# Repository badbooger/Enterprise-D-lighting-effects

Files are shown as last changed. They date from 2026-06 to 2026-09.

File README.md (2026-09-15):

# USS Enterprise-D Prop Controller

Custom lighting and sound controller for the DeAgostini USS Enterprise-D partwork model kit (31 issues). Replaces the original lighting PCBs with custom ESP32-based boards controlled from a 3D-printed LCARS PADD touchscreen.

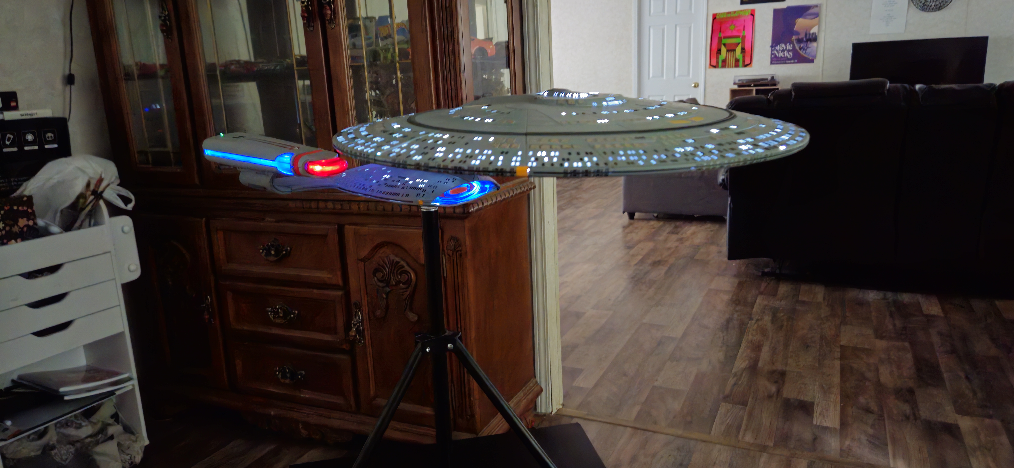
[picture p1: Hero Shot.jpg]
USS Enterprise-D prop model


## What it does

- **LCARS DataPad** — 7" touchscreen prop running a full LVGL LCARS interface. Controls all lighting, sound, and settings on both model sections wirelessly.
- **ESP-NOW mesh** — Bridge (saucer) and EngRoom (stardrive) communicate without any router or hub. Normal operation requires no WiFi.
- **Coordinated effects** — startup, shutdown, damage, warp, and navigation sequences across 18 LED groups on the saucer and 10 groups on the stardrive, all triggered from the PADD.
- **Sound** — DY-SV17F player on the Bridge drives 25 TNG sound files. DataPad has its own second player for UI sounds and ambient audio.
- **OTA updates** — all three units flash over WiFi via Arduino IDE. WiFi only starts when you need it; ESP-NOW resumes automatically when it disconnects.

All LEDs are white. All effects are brightness, PWM duty cycle, and timing patterns only — no colour control.

---

## Units

| Unit | Board | Sketch | Role |
|---|---|---|---|
| Bridge | ESP32-S3 | `Bridge_ESP/` | Saucer — 18 LED groups, sound |
| EngRoom | Xiao ESP32-C3 | `Engine_Room_ESP/` | Stardrive — 10 LED groups |
| DataPad 7" | Waveshare ESP32-S3 7" | `Data_Pad/` | LCARS touchscreen controller |
| WarpCore | Arduino Nano ESP32 | `WarpCore_ESP32/` | Standalone warp core display (see note below) |

There's also a **work-in-progress webpage-control variant** of Bridge and EngRoom — [`Bridge_ESP_Webpage/`](Bridge_ESP_Webpage) and [`Engine_Room_ESP_Webpage/`](Engine_Room_ESP_Webpage). Instead of the DataPad pushing WiFi credentials for OTA, Bridge hosts its own permanent access point with a built-in control webpage — no DataPad or home network required to run or control the model. It hasn't been tested as thoroughly as the sketches above yet; see each folder's README for details and current rough edges.

---

## Hardware

Six custom PCB designs (seven boards total), all designed in EasyEDA. Gerbers, BOMs, and pick-and-place files are in `enterprise documentation/PCB Design/`.

**Single power source option:** The EngRoom and Neck PCBs use wider 0.8–1mm VCC/GND traces than the rest of the boards, sized to carry the full model's power if you'd rather not run separate battery boxes. Route: drill a hole through the stand mount to run wires hidden from the stand into EngRoom's 2-pin JST connector → through the EngRoom PCB → out the FFC to the Neck PCB's 2-pin connector, reusing the same connector that would normally be power-in from a local neck battery → out through the neck to the spare 2-pin JST connector on Bridge PCB3, which is unused in the normal build → power wiring from there is the same as the original build. This wires the two sections together permanently — the model can no longer be physically separated into saucer and stardrive once this is done. The 2-pin connectors that come with the kit's battery boxes can be reused to make the jumper needed to run power from the Neck PCB to the Bridge PCB3 — or if you don't want to cut the wiring off the battery boxes, the connectors are standard JST and can be ordered from Amazon or a parts supplier of your choice.

**Fuse and reverse-polarity protection:** the external supply connects through a barrel jack instead of the model's battery boxes — unplug all three battery packs (both saucer packs and the neck pack) before running this way, since nothing in this design accounts for a battery pack and an external supply both being connected at once. Add an inline fuse (slow-blow, rated above the model's combined nominal draw — see `HARDWARE.md` for the full LED power budget) and a basic reverse-polarity diode in series with the barrel jack, outside the model where both are easy to inspect and replace. This is bare-minimum protection, not a full power-supply design — there's no BMS or onboard charge/discharge protection anywhere in this build. **Exact fuse rating, diode part, barrel jack size, and wiring routing are left to you** — every build's access points and cable runs differ enough that one prescribed part list won't fit every setup.

See `HARDWARE.md` for pinouts, resistor values, power budget, battery configuration, and connector maps.

Parts list with Amazon links: `amazon parts.txt`.

---

## Getting started

### Prerequisites

- Arduino IDE 2.x
- esp32 by Espressif Systems **v3.3.8** (Board Manager)
- Set your Arduino sketchbook path to this folder — all libraries are in `libraries/`

### First flash (USB)

> **Blank ESP32-S3 modules:** A new S3 chip that has never been programmed will not enumerate over USB — first flash must go through UART (TX/RX) with a USB-to-serial adapter. Alternatively, use an S3 desoldered from a dev board — those ship with USB CDC firmware already flashed. See `HARDWARE.md` for details.

Flash in this order so ESP-NOW communication works from the start:

1. **Bridge** — see [Bridge_ESP/README.md](Bridge_ESP/README.md)
2. **EngRoom** — see [Engine_Room_ESP/README.md](Engine_Room_ESP/README.md)
3. **DataPad** — see [Data_Pad/README.md](Data_Pad/README.md)

Before flashing: run `MAC_address_retriver/` on each board to get its MAC address, then update the peer MAC arrays in each sketch to match your hardware.

### OTA updates (after initial flash)

Normal operation: WiFi off, ESP-NOW on channel 1.

1. Press **START WIFI** on the DataPad — pushes your saved WiFi credentials to all units, all connect.
2. Arduino IDE → Tools → Port → select the network port for the unit to flash.
3. Upload. OTA password: **admin** (enter in Arduino IDE at upload time — no `setPassword()` call in the sketch).
4. Press **SAVE WIFI** again on the DataPad → all units disconnect, revert to channel 1.

> Use a **phone hotspot**, not a home mesh/multi-AP network. Units on different channels cannot reach each other via ESP-NOW and silently fail. See `DEVNOTES.md` for details.

---

## Repository contents

| Path | Contents |
|---|---|
| `Bridge_ESP/` | Saucer ESP32-S3 sketch |
| `Engine_Room_ESP/` | Stardrive Xiao ESP32-C3 sketch |
| `Bridge_ESP_Webpage/` | **Work in progress** — Bridge variant with a built-in WiFi control webpage |
| `Engine_Room_ESP_Webpage/` | **Work in progress** — EngRoom variant to pair with `Bridge_ESP_Webpage`, adds a WiFi fallback/recovery page |
| `Data_Pad/` | 7" DataPad sketch and LVGL UI files |
| `WarpCore_ESP32/` | WarpCore ESP32 sketch |
| `Bridge_NVS_Clear/` | Utility — wipes Bridge WiFi credentials from NVS |
| `EngRoom_NVS_Clear/` | Utility — wipes EngRoom WiFi credentials from NVS |
| `MAC_address_retriver/` | Utility — reads and prints a board's MAC address |
| `enterprise documentation/PCB Design/` | Gerbers, BOMs, pick-and-place for all 6 board designs |
| `enterprise documentation/Data Pad stl/` | DataPad PADD case STL files |
| `enterprise documentation/Warp_Core/` | Original Thingiverse WarpCore design archive (see below) |
| `enterprise documentation/pcbs test prints/` | PCB test-fit prints — print before ordering boards |
| `HARDWARE.md` | Full hardware reference |
| `SOUND_MAP.md` | Sound file list and trigger map |
| `amazon parts.txt` | Parts list with Amazon links |

**Not included:**
- `sounds/` — source TNG audio clips from [trekcore.com/audio](https://trekcore.com/audio/). See `SOUND_MAP.md` for the file list and naming format.
- `libraries/` — install per `PROJECT_REFERENCE.md`.

---

## WarpCore

The WarpCore is a standalone unit with its own repository — `WarpCore_ESP32/` is included here for reference. See the WarpCore repo for the full README, pin assignments, and build notes.

The 3D model is based on **ST:TNG Warp Core by ElmoC** (Thingiverse thing:1656741). The original listing is no longer available online. A complete archive including all STL files, the original PCB files, and the original Arduino sketch is preserved in `enterprise documentation/Warp_Core/`. Licensed under Creative Commons Attribution — Non-Commercial — No Derivatives 3.0.

Other warp core designs exist on Thingiverse in different sizes, including versions designed around ARGB LED strips which give a colour-animated effect. Worth exploring if you are starting from scratch.

---

## License

Code and PCB designs: [MIT](LICENSE)  
WarpCore 3D model: CC BY-NC-ND 3.0 (ElmoC — see `enterprise documentation/Warp_Core/LICENSE.txt`)  
Sound files: not included — source separately from trekcore.com/audio/

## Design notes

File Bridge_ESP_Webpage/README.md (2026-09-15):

# Bridge ESP (Webpage variant) — ESP32-S3

> **⚠️ Work in progress.** This is a newer variant of the Bridge firmware that hosts its own WiFi control page — it hasn't been through the same amount of real-world testing as the plain [`Bridge_ESP`](../Bridge_ESP) sketch yet. Expect rough edges. If you just want the proven, minimal firmware (DataPad-driven, no built-in webpage), use `Bridge_ESP` instead.

Saucer section controller — same core effects as `Bridge_ESP` (window groups, nav lights, impulse engines, sound player, startup/shutdown sequences, ESP-NOW to EngRoom/DataPad), plus:

- **Hosts its own WiFi access point and control webpage** (`WebServer.h`) — no home network or DataPad required to run the model. Connect a phone or laptop directly to Bridge's AP and control everything from a browser.
- **Autonomous demo mode** — an optional showpiece loop that cycles power on/off and fires random effects on its own, useful for unattended display.
- **DataPad auto-pairing window** — a button on the control page opens a short listen-and-adopt window so a new DataPad can be paired without recompiling anything.

---

## Arduino IDE setup

| Setting | Value |
|---|---|
| Board | ESP32S3 Dev Module |
| Board package | esp32 by Espressif Systems v3.3.8 |
| Partition scheme | Default 4MB with spiffs (or Huge APP if flash space is needed) |
| Upload speed | 921600 |

No external libraries needed — `WebServer.h` is part of the ESP32 Arduino core, same as everything else this sketch uses.

This folder needs both files together: `Bridge_ESP_Webpage.ino` and `control_html.h` (the control page's HTML/JS, served straight from flash).

---

## First flash

Same as `Bridge_ESP` — see that folder's README for PCB/module assembly notes and the board-settings-reset warning. OTA password is `admin`.

---

## MAC addresses to update

Open `Bridge_ESP_Webpage.ino` and find the peer MAC arrays near the top of the file:

```cpp
uint8_t broadcastAddress1[] = { 0x00, 0x00, 0x00, 0x00, 0x00, 0x00 }; // EngRoom
uint8_t broadcastAddress2[] = { 0x00, 0x00, 0x00, 0x00, 0x00, 0x00 }; // DataPad
```

Two ways to set these:
- **Edit and recompile** — replace with the actual MACs from your hardware (run `MAC_address_retriver/` on each board), same as the plain sketch.
- **Set them live over the control page** — once flashed and connected to Bridge's AP, browse to `http://<bridge-ip>/setmac?peer=engroom&mac=AA:BB:CC:DD:EE:FF` (or `peer=datapad`). Saved to NVS, applied immediately, survives reboots. No recompiling needed if you swap a board later.

---

## Connecting to Bridge's control page

Bridge hosts its own access point:

| Setting | Value |
|---|---|
| SSID | `Enterprise D` |
| Password | `ncc1701-d` |

Connect a phone or laptop to it, then browse to `http://192.168.4.1/`. Change the SSID/password constants near the top of the sketch if you'd rather use your own.

---

## Everything else

GPIO assignments, key effects, sound setup, and NVS settings are identical to the plain `Bridge_ESP` sketch — see that folder's README for the full reference tables. The NVS clear utility (`Bridge_NVS_Clear/`) works the same way here too.

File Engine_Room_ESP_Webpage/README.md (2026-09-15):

# Engine Room ESP (Webpage variant) — Xiao ESP32-C3

> **⚠️ Work in progress.** This is a newer variant of the EngRoom firmware, meant to pair with [`Bridge_ESP_Webpage`](../Bridge_ESP_Webpage). It hasn't been through the same amount of real-world testing as the plain [`Engine_Room_ESP`](../Engine_Room_ESP) sketch yet. Expect rough edges. If you just want the proven, minimal firmware, use `Engine_Room_ESP` instead.

Stardrive section controller — same core effects as `Engine_Room_ESP` (nacelles, deflector, impulse engines, nav lights, neck/case windows, ESP-NOW to Bridge/DataPad), plus:

- **Independent aft photon torpedo control**, for the optional second-LED "Photon 2x" torpedo variant (adds a connector on GPIO9, active-low, no transistor needed). Fires and animates separately from the forward tube — not just a mirror of it. If you don't have the second connector installed, this is simply unused.
- **Automatically joins Bridge's WiFi AP** on boot — no manual WiFi setup needed as long as `Bridge_ESP_Webpage` is running nearby with its default AP settings.
- **Fallback access point** if Bridge's AP can't be reached within 3 minutes (Bridge off, unflashed, or out of range) — EngRoom hosts its own small AP with a bare-bones recovery/test page, so you're never locked out of OTA just because Bridge is unreachable.

---

## Arduino IDE setup

| Setting | Value |
|---|---|
| Board | XIAO_ESP32C3 |
| Board package | esp32 by Espressif Systems v3.3.8 |
| Upload speed | 921600 |

No external libraries needed — `WebServer.h` is part of the ESP32 Arduino core, same as everything else this sketch uses.

---

## First flash

Same as `Engine_Room_ESP` — see that folder's README for module assembly notes, the download-mode button sequence, and the board-settings-reset warning. OTA password is `admin`.

---

## MAC addresses to update

Open `Engine_Room_ESP_Webpage.ino` and find the peer MAC arrays near the top of the file:

```cpp
uint8_t broadcastAddress[]  = { 0x00, 0x00, 0x00, 0x00, 0x00, 0x00 };  // DataPad
uint8_t bridgeAddress[]     = { 0x00, 0x00, 0x00, 0x00, 0x00, 0x00 };  // Bridge
uint8_t dataPad2Address[]   = { 0x00, 0x00, 0x00, 0x00, 0x00, 0x00 };  // DataPad 2.8" (optional)
```

Two ways to set these:
- **Edit and recompile** — replace with the actual MACs from your hardware (run `MAC_address_retriver/` on each board), same as the plain sketch.
- **Set them live over Serial** — connect at 115200 baud and send `SETMAC bridge AA:BB:CC:DD:EE:FF` (or `SETMAC datapad ...` / `SETMAC datapad2 ...`). Saved to NVS, applied immediately, survives reboots.

---

## Fallback AP and recovery page

If EngRoom can't join Bridge's AP within 3 minutes, it hosts its own:

| Setting | Value |
|---|---|
| SSID | `EngRoom Fallback` |
| Password | `ncc1701-d` |

Connect to it and browse to `http://192.168.4.1/` for a plain status/test page: connection status, All LEDs On/Off (also pings Bridge over ESP-NOW as a connectivity check), an LED test walk, a plain reboot, and a reset-to-default that clears settings but keeps your paired peer MACs. It keeps retrying Bridge's AP in the background and tears itself down automatically once Bridge is reachable again — no reboot needed.

---

## Everything else

GPIO assignments (including GPIO9 for the optional aft photon connector), key effects, and NVS settings are the same as the plain `Engine_Room_ESP` sketch — see that folder's README for the full reference tables. The NVS clear utility (`EngRoom_NVS_Clear/`) works the same way here too.

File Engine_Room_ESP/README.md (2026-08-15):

# Engine Room ESP — Xiao ESP32-C3

Stardrive section controller. Drives 9 LED groups through NPN transistors: nacelles (sine-wave pulse with warp mode), deflector, photon torpedoes, impulse engines, nav lights, engineering case sections, and neck (back of neck + both battle bridges on one pin). Communicates with Bridge and the DataPad via ESP-NOW. Supports OTA firmware updates and mDNS (`EngRoom.local`) when WiFi is connected.

---

## Arduino IDE setup

| Setting | Value |
|---|---|
| Board | XIAO_ESP32C3 |
| Board package | esp32 by Espressif Systems v3.3.8 |
| Upload speed | 921600 |

No external libraries needed — all dependencies are part of the ESP32 Arduino core.

---

## PCB and module assembly

The Seeed Studio Xiao ESP32-C3 must be soldered to the EngRoom PCB yourself — JLCPCB does not carry it as a placeable part, so it cannot be installed during PCB assembly. Order the Xiao separately and hand-solder it to the board after the PCB arrives.

Once soldered, the Xiao's own onboard USB-C connector is used for flashing — no other USB port is needed.

---

## First flash

Connect via the Xiao's USB-C port. The Xiao ESP32-C3 may need to be put into download mode on first flash: hold BOOT, tap RESET, release BOOT. Select the correct COM port in Arduino IDE and upload.

After the first USB flash, subsequent updates can be done OTA — see the root README for the OTA procedure.

**OTA password:** `admin` — entered in Arduino IDE at upload time.

> **Warning — board settings reset on sketch reload:** Arduino IDE resets board settings to defaults whenever a sketch is opened or the `.ino` file is replaced. Always verify the settings in the table above before flashing. If the wrong settings are used, the board will not boot and will require USB access to recover — the EngRoom board is inside the stardrive section and requires disassembly to reach.

---

## MAC addresses to update

Open `Engine_Room_ESP.ino` and find the peer MAC arrays near the top of the file:

```cpp
uint8_t broadcastAddress1[] = { 0x20, 0x6e, 0xf1, 0xa9, 0xa1, 0x14 };  // DataPad
uint8_t broadcastAddress2[] = { 0xe0, 0x72, 0xa1, 0xd7, 0x37, 0x14 };  // Bridge
```

Replace with the actual MACs from your hardware (run `MAC_address_retriver/` on each board).

---

## GPIO assignments

**Lower engineering section:**

| GPIO | Function |
|---|---|
| 2 | Battery ADC (270kΩ+100kΩ divider, ADC_11db) |
| 4 | Photon torpedoes |
| 5 | Nav lights |
| 6 | Deflector |
| 7 | Top engineering case |
| 8 | Left nacelle |
| 9 | Right nacelle |
| 10 | Impulse engine |
| 21 | Bottom engineering case |

**Neck section** (routed via FFC from lower engineering PCB):

| GPIO | Function |
|---|---|
| 20 | Neck windows — back of neck + both battle bridges wired together, one pin |

All LED groups are switched through MMBT2222A NPN transistors. Do not connect LEDs directly to GPIO pins.

> **Note on nav lights:** GPIO 5 drives 4 transistor bases in parallel (EngRoom PCB, neck PCB, port nacelle, starboard nacelle) — all nav LEDs across the stardrive section from one pin.

---

## Key effects

**Nacelle pulse (normal)** — slow sine-wave breathing (5000ms period, 80–115 duty range) when model is running.

**Nacelle warp mode** — triggered by `LED_WARP` command with a speed value 1–10. Three-phase startup: snap to 25% → ramp to 100% over ~1.5s → hold at speed-mapped brightness (80–100%). Speed changes while warp is active skip the ramp. Returns to normal sine on `LED_WARP val=0`.

> **Brighter warp flash:** The nacelle PCB uses 6× blue 1206 SMD LEDs wired as 3 parallel pairs, each pair sharing one current-limiting resistor. This build uses **240Ω** on those pairs — at 7.4V nominal with Vf ≈ 2.6–3.1V that's ~8.75mA per LED, noticeably brighter than a typical stock value and well within the 20mA LED rating — installed specifically to make the warp-flash effect punchier. In practice, brightness between paired LEDs is indistinguishable. Do not go below 220Ω. The single LEDs on the board (non-paired, through-hole) use a separate higher value, **470Ω**, to match the same per-LED current.
>
> The higher current only shows up during the warp effect itself. Normal-running nacelle brightness is capped in firmware well below what these resistors allow — the idle sine pulse stays in the 80–115/255 duty range (see "Nacelle pulse (normal)" below); only warp mode ramps up toward full 255 duty. So the resistor change buys headroom for the flash without making the nacelles run hot/bright all the time.

**Deflector** — 60% steady brightness during normal operation, 100% during warp.

**Photon torpedoes** — charge/fire flash sequence on `LED_ELEC_SHORT` (repurposed command). Charge for 750ms, fire flash at 200ms.

**Startup sequence** — lighting groups come on in steps coordinated with the Bridge startup. EngRoom sends `LED_BLINK` to Bridge at the nav step and `LED_ENGINE` at the impulse step so both sections sync their timing.

**Assembly mode** — all groups blink together for board testing and LED positioning.

---

## NVS settings

Namespace: `"engroom"`. All configurable from the DataPad settings screen.

| Key | Default | Purpose |
|-----|---|---|
| `blink_ms` | 1000 | Nav light blink interval (ms) |
| `sync_mode` | true | Assembled / Separated mode |
| `asm_mode` | false | Assembly blink mode |
| `eff_simple` | false | Simple effects mode (constant ON instead of sine/pulse) |

---

## NVS clear utility

If EngRoom gets stuck trying to connect to WiFi on every boot: flash `EngRoom_NVS_Clear/EngRoom_NVS_Clear.ino`, confirm "Done" in Serial Monitor (115200), then reflash the main sketch.

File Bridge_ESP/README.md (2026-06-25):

# Bridge ESP — ESP32-S3

Saucer section controller. Drives 15 window groups and 3 dedicated outputs (nav lights, two impulse engines) through NPN transistors. Runs the startup/shutdown sequence, engine pulse, navigation blink, and electrical-short damage effect. Hosts a sound player (DY-SV17F). Communicates with EngRoom and the DataPad via ESP-NOW.

---

## Arduino IDE setup

| Setting | Value |
|---|---|
| Board | ESP32S3 Dev Module |
| Board package | esp32 by Espressif Systems v3.3.8 |
| Partition scheme | Default 4MB with spiffs (or Huge APP if flash space is needed) |
| Upload speed | 921600 |

No external libraries needed — all dependencies (ArduinoOTA, ESPmDNS, Preferences, esp_now) are part of the ESP32 Arduino core.

---

## PCB and module assembly

The saucer PCBs are designed around an ESP32-S3 module (WROOM or equivalent). JLCPCB can place and solder the module as part of the PCB assembly order if they have the part in stock — check availability when ordering. The assembled PCB has its own USB-C connector for flashing, so no separate dev board is needed once the PCB is built.

If JLCPCB doesn't have the module available, or if you want to test the sketch before the PCBs arrive: flash the sketch onto a standalone ESP32-S3 dev board first, confirm it works, then transfer the module to the PCB. Once installed, use the onboard USB-C on the PCB or OTA for all subsequent flashes.

---

## First flash

Connect via the USB-C port on the PCB (or dev board). Select the correct COM port in Arduino IDE and upload.

After the first USB flash, subsequent updates can be done OTA — see the root README for the OTA procedure.

**OTA password:** `admin` — entered in Arduino IDE at upload time. There is no `ArduinoOTA.setPassword()` call in the sketch; the library accepts whatever the IDE sends.

> **Warning — board settings reset on sketch reload:** Arduino IDE resets board settings to defaults whenever a sketch is opened or the `.ino` file is replaced. Always verify the settings in the table above before flashing. If the wrong settings are used, the board will not boot and will require USB access to recover — the Bridge board is inside the saucer section and requires disassembly to reach.

---

## MAC addresses to update

Open `Bridge_ESP.ino` and find the peer MAC arrays near the top of the file. Replace with the actual MACs from your hardware (run `MAC_address_retriver/` on each board):

```cpp
uint8_t broadcastAddress1[] = { 0x3c, 0xdc, 0x75, 0xae, 0xcd, 0xb8 };  // EngRoom
uint8_t broadcastAddress2[] = { 0x20, 0x6e, 0xf1, 0xa9, 0xa1, 0x14 };  // DataPad
```

---

## GPIO assignments

| Label | GPIO | Function |
|---|---|---|
| G01–G15 | 6, 7, 35, 5, 15, 21, 16, 14, 13, 12, 11, 10, 8, 3, 9 | 15 window groups (indices 0–14) |
| NAV | 38 | Navigation lights — LEDC blink |
| IM LEFT | 36 | Impulse engine port — LEDC sine pulse |
| IM RIGHT | 37 | Impulse engine starboard — LEDC sine pulse |
| Sound TX | 17 | DY-SV17F UART TX |
| Sound RX | 18 | DY-SV17F UART RX |

All LED groups are switched through MMBT2222A NPN transistors. GPIO drives the transistor base; LEDs are on the collector side. Do not connect LEDs directly to GPIO pins.

**Startup sequence order:**
```
G15 → G14 → G02 → G01+G03 → G09 → G08+G10 → G07+G11 → G06+G12 → G05+G13 → G04 → NAV → Engines
```
Shutdown runs the same sequence in reverse.

---

## Key effects

**Engine pulse** — smooth sine-wave brightness cycle (80–255, 5-second period) on both impulse engines. Always on when the model is running.

**Navigation blink** — toggles at `blinkIntervalMs` (default 1000ms, configurable from DataPad). If DataPad contact is lost, switches to a fault pattern: 3 rapid flashes then a 1.8s pause.

**Electrical short (damage mode)** — 2–3 random window groups flicker via PWM; remaining windows snap to random on/off states; engines go to independent random flicker. Auto-cancels after 2 minutes. Restores pre-damage state on cancel.

**Auto-start** — if no ESP-NOW contact is received within `auto_ms` (default 30s) of boot, Bridge runs the startup sequence independently. Useful when running the saucer without the DataPad.

---

## Sound (DY-SV17F)

UART2, TX=GPIO17, RX=GPIO18, 9600 baud. 25 sound files on 4MB onboard flash. Files named `00001.mp3`–`00025.mp3` — copy them to the player in order (sorted by name). Ready-to-copy files are in `sounds/DY_Player/`. See `SOUND_MAP.md` for the full file list.

Auto-triggered sounds: startup plays file 1, shutdown plays file 2 or 3 (random), damage plays an alert klaxon then a random damage sound.

---

## NVS settings

Namespace: `"bridge"`. All timing values are configurable from the DataPad settings screen and persist across reboots.

| Key | Default | Purpose |
|-----|---|---|
| `blink_ms` | 1000 | Nav light blink interval (ms) |
| `win_ms` | 300 | Window startup step timing (ms) |
| `spc_ms` | 800 | Nav/engine startup step timing (ms) |
| `auto_ms` | 30000 | Auto-start timeout — 0 to disable |
| `conn_ms` | 300000 | Connection-lost timeout (ms) |
| `sync_mode` | true | Assembled (true) / Separated (false) mode |
| `asm_mode` | false | Assembly blink mode |

---

## NVS clear utility

If Bridge gets stuck trying to connect to WiFi on every boot: flash `Bridge_NVS_Clear/Bridge_NVS_Clear.ino`, confirm "Done" in Serial Monitor (115200), then reflash the main sketch.

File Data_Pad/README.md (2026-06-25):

# DataPad — Waveshare 7" ESP32-S3

LCARS touchscreen controller for the Enterprise-D prop. Runs a full LVGL-based LCARS interface on an 800×480 7" display. Controls all lighting, sound, WiFi/OTA, and settings across Bridge and EngRoom via ESP-NOW. Has its own DY1703A sound player for UI sounds and ambient audio.

---

## Arduino IDE setup

| Setting | Value |
|---|---|
| Board | Waveshare ESP32-S3-Touch-LCD-7 (or ESP32S3 Dev Module) |
| Board package | esp32 by Espressif Systems v3.3.8 |
| Flash size | 16MB |
| Partition scheme | 16M Flash (3MB APP/9.9MB FATFS) |
| PSRAM | OPI PSRAM |
| Upload speed | 921600 |

**Required libraries** (in `libraries/` — set sketchbook path to the project root):

| Library | Version | Notes |
|---|---|---|
| lvgl | 8.3.11 | Must be 8.x — LVGL 9 has a different API and will not compile |
| ESP32_Display_Panel | 1.0.0 | Display + touch driver |
| ESP32_IO_Expander | — | Dependency of ESP32_Display_Panel |
| esp-lib-utils | — | Dependency of ESP32_Display_Panel |

---

## First flash

Connect via USB-C to the Waveshare board. Select the correct COM port and upload. The board may need the flash mode button held during initial connection depending on the specific Waveshare revision.

After the first USB flash, subsequent updates can be done OTA — see the root README for the OTA procedure.

**OTA password:** `admin` — entered in Arduino IDE at upload time.

> **Warning — board settings reset on sketch reload:** Arduino IDE resets board settings to defaults whenever a sketch is opened or the `.ino` file is replaced. Always verify the settings in the table above before flashing. If the wrong partition scheme or PSRAM setting is used, the board will not boot and will require USB access to recover — the DataPad must be disassembled for that.

---

## MAC addresses to update

Open `Data_Pad.ino` and find the peer MAC arrays near the top of the file:

```cpp
uint8_t broadcastAddress1[] = { 0x3c, 0xdc, 0x75, 0xae, 0xcd, 0xb8 };  // EngRoom
uint8_t broadcastAddress2[] = { 0xe0, 0x72, 0xa1, 0xd7, 0x37, 0x14 };  // Bridge
uint8_t broadcastAddressWarpCore[] = { 0x20, 0x6e, 0xf1, 0x31, 0xda, 0x54 };  // WarpCore
```

Replace with the actual MACs from your hardware (run `MAC_address_retriver/` on each board).

---

## Screens

| Screen | File | Purpose |
|---|---|---|
| Screen 1 | `ui_Screen1.c` | Main ops — Power, Nav, Engines, Damage, Warp |
| Screen 2 | `ui_Screen2.c` | Settings — timing, sync mode, sensor, sound toggles |
| Screen 3 | `ui_Screen3.c` | WiFi credentials and OTA |
| BridgeSound | `ui_BridgeSound.c/.h` | DY-SV17F sound player controls |
| RedAlert | `ui_RedAlert.c/.h` | Full-screen red alert overlay |

---

## UI editing — important

The UI was built in SquareLine Studio (LVGL 8.3.x project) and then heavily hand-edited. Follow these rules before touching any UI file:

- **Never replace `ui_BridgeSound.c/.h` with a SquareLine Studio export** — it is hand-written from scratch and an SLS export will overwrite it.
- **Never replace `ui_Screen1.c` or `ui_Screen2.c` with an SLS export** — both have hand-written layout and event code that SLS doesn't know about.
- **`ui_events.c` stubs get re-commented on every SLS export** — after any SLS re-export, re-comment the stubs in `ui_events.c` manually.
- `ui.c` and `ui.h` (the screen registry) can be replaced with SLS export output safely.

All UI changes are made by editing the `.c` files directly.

---

## Sound (DY1703A)

UART1, TX=GPIO16, RX=GPIO15, 9600 baud. SD card in root — files `00001.mp3`–`00044.mp3`, no folders. Files 1–25 match the Bridge DY-SV17F file numbers exactly (same sound, same file number, different player). Files 26–44 are DataPad-only (touch feedback, voiced alerts, ambient loops, easter eggs).

See `SOUND_MAP.md` for the full file list.

---

## NVS settings

Namespace: `"datapad"`.

| Key | Default | Purpose |
|-----|---|---|
| `sync_mode` | 1 | Assembled (1) / Separated (0) — startup routes to both sections or each independently |
| `touch_snd` | false | UI touch click sounds |
| `ambient_on` | false | Ambient audio auto-play on power-up |
| `radar_on` | true | LD2410C presence sensor trigger enabled |
| `alert_radar` | true | Sensor fires red alert when model is already on |
| `nav_timing` | 1 | Nav light timing: 1=1.0s, 2=1.5s, 3=always on |
| `wifi_auto` | false | Auto-connect to saved WiFi on boot |

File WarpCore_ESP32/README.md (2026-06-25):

# USS Enterprise-D Warp Core Controller

ESP32-based lighting controller for a 3D-printed TNG warp core prop. Runs a 10-LED chase effect with a smooth ambient glow, speed-controlled by a potentiometer. Optionally integrates with the [Enterprise-D Prop Controller](<!-- add main repo link here -->) via ESP-NOW — the DataPad can control speed and on/off remotely, and the LD2410C presence sensor triggers the main model to power up when someone approaches.

Runs fully standalone with no other hardware required.

---

## 3D model

Based on **ST:TNG Warp Core by ElmoC**. Licensed under Creative Commons Attribution — Non-Commercial — No Derivatives 3.0.

The original Thingiverse listing (thing:1656741) is no longer available. A complete archive of all STL files, the original PCB files, and the original Arduino sketch is preserved in the main Enterprise-D repo under `enterprise documentation/Warp_Core/`.

A modified base (`WarpCoreBase_mmWaveSensor.3mf`) is included in that archive — it integrates the LD2410C mmWave sensor housing directly into the warp core base as a single unit, replacing the original base and a separate sensor mount.

Other warp core designs exist on Thingiverse in different sizes, including versions built around ARGB LED strips which give a full colour-animated effect. Worth exploring if you are starting from scratch — ARGB gives considerably more visual range than the single-colour PWM approach used here.

---

## Hardware

| Component | Notes |
|---|---|
| Arduino Nano ESP32 | Drop-in replacement for the original Arduino Nano in ElmoC's design |
| 10× NPN transistors (MMBT2222A or similar) | One per chase LED group |
| 10× chase LEDs | Through NPN transistors — do not connect directly to GPIO |
| 1× ambient LED | Driven via `analogWrite` on A5 |
| 10kΩ potentiometer | Speed control — wiper to A7, ends to 3.3V and GND |
| LD2410C mmWave presence sensor | Optional — OUT pin to D7, powered from 5V boost converter |

---

## Pin assignments

| Pin | Function | Notes |
|-----|---|---|
| A4 | Chase LED 1 | |
| A3 | Chase LED 2 | |
| A2 | Chase LED 3 | |
| A1 | Chase LED 4 | |
| A0 | Chase LED 5 | |
| D2 | Chase LED 6 | Use `D2` constant — raw `2` is a different GPIO on the Nano ESP32 |
| D3 | Chase LED 7 | Use `D3` constant |
| D4 | Chase LED 8 | Use `D4` constant |
| D5 | Chase LED 9 | Use `D5` constant |
| D6 | Chase LED 10 | Use `D6` constant |
| A5 | Ambient LED | `analogWrite` PWM — dim during chase, full on pause |
| A7 | Speed pot | ADC — wiper input |
| D7 | LD2410C OUT | Push-pull, HIGH = presence detected. No pull-up needed. |

> **Important:** On the Arduino Nano ESP32, `D2`–`D6` Arduino constants do **not** map to raw GPIO 2–6. Always use the `D2`/`D3` etc. constants in the sketch — using raw integers will drive the wrong pins.

---

## Arduino IDE setup

| Setting | Value |
|---|---|
| Board | Arduino Nano ESP32 |
| Board package | esp32 by Espressif Systems v3.3.8 |
| Upload speed | 921600 |

No external libraries needed — all dependencies (ArduinoOTA, ESPmDNS, Preferences, esp_now) are part of the ESP32 Arduino core.

---

## First flash

Connect via USB-C. Select the correct COM port in Arduino IDE and upload.

After the first USB flash, subsequent updates can be done OTA once WiFi is connected (see OTA section in the main Enterprise-D repo README).

**OTA password:** `admin` — entered in Arduino IDE at upload time.

> **Warning — board settings reset on sketch reload:** Arduino IDE resets board settings to defaults whenever a sketch is opened or the `.ino` file is replaced. Always verify the settings in the table above before flashing. If the wrong settings are used, the board will not boot and will require USB access to recover.

---

## MAC addresses to update

If integrating with the Enterprise-D system, open `WarpCore_ESP32.ino` and update the peer MAC arrays to match your hardware:

```cpp
uint8_t dataPadAddress[] = {0x20, 0x6e, 0xf1, 0xa9, 0xa1, 0x14};  // DataPad
uint8_t bridgeAddress[]  = {0xe0, 0x72, 0xa1, 0xd7, 0x37, 0x14};  // Bridge
uint8_t engRoomAddress[] = {0x3c, 0xdc, 0x75, 0xae, 0xcd, 0xb8};  // EngRoom
```

Run `MAC_address_retriver/` (from the main repo) on each board to read its MAC.

---

## How it works

### Standalone mode

On boot, if `on_default` is true in NVS (default), the chase effect starts immediately. Speed is read from the potentiometer on A7 — turn it to adjust the chase rate. No DataPad or other hardware needed.

### Chase effect

10 LEDs chase in sequence. When the last LED turns off, the ambient LED (A5) pulses to full brightness, holds briefly, dims back down, then the chase restarts. Speed maps pot/remote value 0–10 to a 200ms–20ms step delay.

### ESP-NOW integration (optional)

When connected to the Enterprise-D system the DataPad can:
- Turn the warp core on/off (`LED_ON` / `LED_OFF` / `LED_STARTUP` / `LED_SHUTDOWN`)
- Set warp speed 1–10 (`LED_WARP`) — overrides the pot while active, returns to pot on `LED_WARP val=0`
- Enable/disable the presence sensor (`LED_RADAR_EN`)

### Presence sensor (LD2410C)

When presence is detected on D7 and `radarEnabled` is true, WarpCore sends `LED_RADAR_TRIG` to the DataPad. DataPad powers up the full Enterprise model if it is off, or triggers red alert if it is already on.

Detection range is configured via the HLKRadarTool app over Bluetooth or UART. The current build has only the OUT pin wired (D7) — UART is not yet connected, so sensitivity must be configured via the Bluetooth app.

---

## NVS settings

Namespace: `"warpcore"`.

| Key | Default | Purpose |
|-----|---|---|
| `on_default` | true | Run chase effect on boot without waiting for DataPad |
| `radar_on` | true | LD2410C presence trigger enabled |
| `wifi_auto` | false | Auto-connect to saved WiFi on boot |

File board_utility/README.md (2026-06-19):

# Board Utility

> **Safety Warning:** These PCBs are experimental, hand-designed hobby boards — not certified consumer products. If you are building with LiPo or Li-ion batteries, take proper precautions: never leave charging batteries unattended, use appropriate cell protection, and verify polarity before connecting power. Incorrect wiring or battery handling can cause fire, burns, or damage to components. Proceed at your own risk.

---

## What This Does

This sketch comes preloaded on your ESP32 boards. When you power a board on for the first time, it starts a local WiFi access point — no internet connection or router needed. Connect to it with your phone or laptop and the board's MAC address is displayed on a webpage that opens automatically.

The boards in this project communicate with each other using ESP-NOW, a direct wireless protocol that requires each board to know the MAC addresses of its peers. Before you can flash the main sketches, you need to collect the MAC address from every board and enter them into the code.

**WiFi access point details:**
- SSID: `enterprise`
- Password: `ncc-1701-d`
- IP: `192.168.4.1`

This is a standalone access point — your phone/laptop connects directly to the ESP32. It does not connect to your home network or the internet.

**Built-in OTA (Over-The-Air) updates:** After the initial USB flash, this sketch can be updated wirelessly. If you connect your computer to the board's WiFi access point, the Arduino IDE will show `board_utility` as a network port under **Tools > Port**. You can upload updated sketches over WiFi without plugging in a USB cable. This also applies to the main project sketches once they are flashed — they all support OTA updates.

The MAC address is also printed to the serial monitor at 115200 baud if you prefer to read it that way.

## How to Use

1. **Open** `board_utility.ino` in the Arduino IDE.
2. **Select your board** in the IDE (e.g. ESP32-S3 for the Bridge, XIAO ESP32-C3 for EngRoom, etc.).
3. **Upload** via USB.
4. **Connect** your phone or laptop to the WiFi network:
   - SSID: `enterprise`
   - Password: `ncc-1701-d`
5. A captive portal page should **open automatically** showing the board's MAC address. If it doesn't, open a browser and go to `http://192.168.4.1`.
6. **Write down the MAC address** — you'll need it when setting up the main sketches.
7. **Repeat** for each board in the project.

## Clearing NVS Storage

The webpage also has buttons to clear the NVS (Non-Volatile Storage) on the board. NVS is where the main sketches save WiFi credentials, timing settings, and other preferences. If you need to reset a board to factory defaults or clear out saved WiFi credentials, tap the button for the unit you're working on:

- **Bridge** — clears the `bridge` namespace
- **EngRoom** — clears the `engroom` namespace
- **DataPad** — clears the `datapad` namespace
- **WarpCore** — clears the `warpcore` namespace
- **Clear All** — clears all four namespaces at once

Since this sketch is preloaded on the board, you don't need to edit any WiFi credentials or flash a separate clearing sketch — just connect to the AP and tap the button.

## OTA Updates

After the initial USB flash, you can update this sketch over WiFi:

1. Connect your computer to the `enterprise` WiFi network.
2. In Arduino IDE, go to **Tools > Port** and select `board_utility` from the network ports list.
3. Upload as normal.

## Next Steps

Once you have all your MAC addresses, head to the main repository for everything else — sketch documentation, GPIO pin assignments, board settings, wiring references, and assembly notes:

**https://github.com/badbooger/Enterprise-D-lighting-effects**

Each sketch folder in the repo has its own README with the specific setup instructions for that unit.

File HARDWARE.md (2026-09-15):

# USS Enterprise-D Prop Controller — Hardware Reference

## PCB Overview

The model splits into two physical sections, each with its own ESP32 and PCB stack.

| Section | Controller | PCB Stack | Ribbon Cables |
|---|---|---|---|
| Saucer (Bridge) | ESP32-S3 | 3 custom PCBs | 8-pin + 15-pin |
| Stardrive (EngRoom) | Xiao ESP32-C3 | 4 custom PCBs | 8-pin x2 |

Power distribution uses JST Micro 1.25 connectors throughout. The stardrive's two 8-pin FFCs (one signal, one power) are over-engineered — the entire stardrive draws 250–375mA, well within a single cable using the 2 spare signal pins for power.

---

## ESP32-S3 First Flash — UART Required for Blank Chips

A brand new ESP32-S3 WROOM module (fresh from reflow, never programmed) will not enumerate over USB. The S3's USB port is a software CDC peripheral — there is no hardware USB-to-UART bridge on the chip. Until firmware with USB CDC On Boot enabled is flashed, the PC never sees a serial port and the chip boot-loops on USB connection.

**First flash must go through the hardware UART pins (TX/RX) using a USB-to-serial adapter or a dev board with a UART bridge (CP2102/CH340).** Once a sketch is flashed with "USB CDC On Boot" enabled in Arduino IDE board settings, native USB works normally from that point on — including for OTA and future USB uploads.

**Alternative: use an S3 from a dev board.** ESP32-S3 dev boards ship with USB CDC firmware already flashed from the factory. Desolder the WROOM module from a dev board, reflow it onto the custom PCB, and USB works immediately — no UART step needed.

---

## Bridge ESP32-S3 — GPIO Pinout

| Group | GPIO Pin | Description |
|---|---|---|
| G01 | 6 | Window group 1 |
| G02 | 7 | Window group 2 |
| G03 | 35 | Window group 3 |
| G04 | 5 | Window group 4 |
| G05 | 15 | Window group 5 |
| G06 | 21 | Window group 6 |
| G07 | 16 | Window group 7 |
| G08 | 14 | Window group 8 |
| G09 | 13 | Window group 9 |
| G10 | 12 | Window group 10 |
| G11 | 11 | Window group 11 |
| G12 | 10 | Window group 12 |
| G13 | 8 | Window group 13 |
| G14 | 3 | Window group 14 |
| G15 | 9 | Window group 15 |
| NAV | 38 | Navigation lights |
| IM LEFT | 36 | Impulse engine — port |
| IM RIGHT | 37 | Impulse engine — starboard |
| TX (Sound) | 17 | DY-SV17F UART TX |
| RX (Sound) | 18 | DY-SV17F UART RX |

### Startup / Shutdown Group Order

```
G15 → G14 → G02 → G01+G02 (simultaneous)
→ G09
→ G08+G10 → G07+G11 → G06+G12 → G06+G13
```

### Known Issue — Pin Label Assignments Are Mirrored and Flipped

The reference drawing used during Bridge PCB design was sourced from a website and had its pin labels mirrored and flipped. The label assignments were taken from that drawing, so the group labels on the board do not match the original kit documentation.

**The physical board is correct** — mounting holes, connector positions, and board layout all fit the model as intended. No physical rework needed.

**Current state — functional as-is:** The LED connector labels on the board are correct relative to each other, so plugging each LED connector to its matching labelled pin works without any modification.

**Board revision items identified during neck assembly — both confirmed 2026-05-19:**

1. **Mounting holes** — need to shift to the opposite side of the board. During neck assembly the board had to be moved to clear the power switch, and the current hole positions no longer line up. Shift holes to the other side in the next PCB revision.
2. **Pin label assignments** — pin order issue encountered during neck assembly as expected. Resolved by swapping LEDs/connectors into physically correct positions rather than following kit documentation pin order. Labels need correcting in a board revision if kit documentation compatibility is wanted. Not required for current functionality.

---

## DY-SV17F Sound Player — Mode Selection

The DY-SV17F supports multiple operating modes (UART, one-wire, IO trigger, etc.), selected by pulling certain pins high or low at boot. PCB 3 has a resistor array of three groups of pull-up and pull-down footprints to allow the mode to be changed by populating or depopulating resistors, rather than cutting traces or rewiring. This was designed in as a fallback in case UART control didn't work — any other mode could be configured by swapping resistors instead of spinning a new board.

**Current mode: UART** (TX=GPIO17, RX=GPIO18, 9600 baud). UART works reliably.

**PCB revision 2026-05-21:** Non-UART mode resistors removed from PCB 3. Only the resistors required to configure UART mode are retained. Simplifies the board with no functional change.

### No-Sound Build Variant

If the DY-SV17F is not wanted — for a simpler build or to keep costs down — the sound player and its resistor array can be omitted entirely. Without the DY player there is no 5V requirement, which means the 2S (7.4V) battery is no longer necessary. A no-sound build could run on either:

- **Original kit power** — 3 AAA batteries, exactly as the kit shipped. Simple, no modifications needed.
- **1S LiPo + USB charging circuit** — single cell (~3.7V nominal) with a small charging module (e.g. TP4056). Adds recharging capability with less risk than the current 2S setup, which has no BMS. A reasonable upgrade path for a no-sound build.

Note: the 2S battery was chosen specifically to give a simple linear regulator path to 5V for the DY player. Remove the player and the reason for 2S goes away.

### External Boost Option (out of scope)

An alternative to the full 2S setup: add solder pads on the PCB to power the DY-SV17F from a small external boost converter (3.7V→5V) running off a 1S LiPo or the original 3 AAA cells. This would allow a simpler battery with sound still present. Adds a separate module and extra design work — outside the scope of the current project, noted here for future consideration only.

---

## LED Resistor Values and Voltage History

All LED current-limiting resistors are 0603 package. Values were chosen empirically to match the original kit brightness at each supply voltage.

| Version | Supply | LED current-limiting resistor | Calculated LED current (Vf ≈ 3.2V) |
|---|---|---|---|
| Original kit | 4.5V (3× AAA) | 820Ω | ~1.6mA |
| Current build (2S LiPo) | 7.4V nominal / 8.4V full | 1.2kΩ | ~3.5mA / ~4.3mA |
| 3S upgrade (board revision) | 11.1V nominal / 12.6V full | **2.2kΩ** | ~3.6mA / ~4.3mA |
| 5V bypass build (PCB 3, planned) | 5V (USB / direct 5V input) | **510Ω** (calculated, not yet built) | ~3.5mA |

The 2.2kΩ value for 3S was calculated to match the current 2S/1.2kΩ operating current almost exactly — same brightness, no PWM compensation needed. The 510Ω 5V value follows the same target current (~3.5mA) as the 2S and 3S builds; it hasn't been populated or tested on hardware yet — confirm before ordering.

**Note:** At these current levels (under 8mA in any configuration) the LEDs are lightly loaded relative to their ~20–30mA ratings. Long-term LED damage is not a concern at any of these supply voltages.

> ⚠️ **IMPORTANT — Two populations of 1.2kΩ resistors on the revised boards:**
> During the 2026-05-21 PCB revision, all transistor base resistors were changed from 10kΩ to **1.2kΩ** to reduce the BOM to a single resistor value per board. This means the boards now have two distinct groups of 1.2kΩ resistors:
> - **LED current-limiting resistors** — in series with each LED group. **These change when changing supply voltage.**
> - **Transistor base resistors** — between GPIO and transistor base. **These do NOT change with supply voltage — 1.2kΩ is correct for 3.3V logic at any supply.**
>
> When doing any voltage conversion, only replace the LED current-limiting resistors. The base resistors stay at 1.2kΩ regardless. Confusing these two populations and changing the base resistors would affect transistor drive and cause LEDs to be dim or not switch at all.

### 3S LiPo Upgrade Notes (for board revision)

Switching from 2S (7.4V) to 3S (11.1V nominal, 12.6V full) with existing 1.2kΩ resistors is safe for the LEDs — worst case is 7.8mA at full charge. PWM compensation works fine if doing this on current boards: drop baseline "full on" brightness from 255 to ~135 (~53% duty cycle) to match current brightness. No hardware change needed short-term.

For a board revision:
- Change **LED current-limiting resistors** to **2.2kΩ** — eliminates the brightness difference entirely (base resistors stay at 1.2kΩ)
- Replace linear voltage regulators with **buck converters** (e.g. MP2307, SOT-23-8 footprint) — linear regs run significantly hotter at 3S input (12.6V → 3.3V is a 9.3V drop vs 5.1V on 2S)
- Battery compartment gains ~50% more energy: 3× real 10440 cells (11.1V × 0.6Ah = 6.66Wh) vs current 2× cells + dummy (7.4V × 0.6Ah = 4.44Wh)
- 3S full charge = 12.6V — confirm voltage regulator input ratings before ordering

---

## EngRoom Xiao ESP32-C3 — LED Groups

9 LED pins, 6 groups (plus GPIO 2 for battery ADC):

| Group | Pins | Description |
|---|---|---|
| Windows | 3 pins (individual) | 3 addressable window groups: neck all (GPIO 20 — back of neck + both battle bridges wired together), eng top (GPIO 7), eng bot (GPIO 21) |
| Nacelles | 2 pins (1 group) | Port (GPIO 8) + starboard (GPIO 3) warp nacelles |
| Deflector | 1 pin | Deflector dish (GPIO 6) |
| Photon torpedoes | 1 pin | Forward torpedo launcher — GPIO 4, own 1.2kΩ resistor on neck PCB (see revision note below) |
| Impulse engines | 1 pin | Stardrive impulse (GPIO 10) |
| Nav lights | 1 pin | Navigation lights — GPIO 5, white LED, 4 transistors total: EngRoom PCB, neck PCB, port nacelle, starboard nacelle. Own 1.2kΩ resistor on neck PCB (see revision note below) |

> **Neck PCB revision in progress (2026-05-21):** Addresses nav/photon shared resistor and nav transistor issues.
> - Nav and photon LEDs previously shared a single 1.2kΩ resistor — caused photon backfeed to lower board nav LED (fix #3) and nav dimming (fix #5). Fixed in revision: each LED now has its own 1.2kΩ resistor on the neck PCB.
> - Nav lights redesigned: neck board previously had no transistor — the neck nav LED was connected directly to the EngRoom PCB transistor collector. Neck PCB now has its own transistor for the neck nav LED, driven by the GPIO 5 control signal via the FFC. GPIO 5 now drives 4 transistor bases in parallel (EngRoom, neck, port nacelle, starboard nacelle) — ~8.8mA total, within ESP32-C3 limits.
> - All pull-down resistors removed from neck PCB (consistent with battle bridge PCB decision — ESP32 OUTPUT mode holds pins LOW, external pull-downs redundant).
> - All base resistors changed from 10kΩ to 1.2kΩ — same value as LED current-limiting resistors, reduces BOM to one resistor value on the board.
> - Connector footprint reversed so nav/photon wiring is correct by design — no re-pinning needed after this revision.
> - Board layout and mounting hole locations updated to match original model dimensions.
>
> **EngRoom PCB also revised (2026-05-21):** Multiple changes — current boards unchanged, firmware update deferred until new boards fitted.
> - FFC connector updated — nav pin now carries GPIO 5 control signal to neck PCB nav transistor base (was post-transistor collector output).
> - Voltage regulator moved away from centre standoff; input/output decoupling caps moved with it.
> - Battery voltage monitor added on GPIO 2 (ADC1). Voltage divider: R1=270kΩ, R2=100kΩ — maps 6.0V–8.4V battery range to 1.62V–2.27V on ADC. Use ADC_11db attenuation in firmware. **Hand-assembly bench substitute:** 470kΩ (R1) + 200kΩ (R2) — maps same range to 1.79V–2.51V, comfortably within 11dB range and ratio close to final design. Calibrated multiplier (bench supply, 6.0V–8.4V, 2026-06-09): **Vbat = Vadc × 3.83** — accurate to within 1% across full range. Theoretical value was 3.70; ESP32 ADC reads ~3.4% low across this range. Divider placed on PCB close to GPIO 2, tapped directly from the local supply rail. Keep analog trace short.
> - Neck windows (10 LED-pair groups, 3 transistors) combined onto one GPIO signal — all 3 transistor bases tied to same net, no component changes needed.
> - Pull-down resistors removed. Base resistors changed from 10kΩ to 1.2kΩ — matches LED current-limiting resistor value, reduces BOM to one resistor value on the board.
> - Left nacelle connector footprint corrected to match physical wiring layout.
> - **New GPIO assignments for revised PCB:** GPIO 20 = all neck windows (back of neck + both battle bridges wired together), GPIO 8 = left nacelle, GPIO 3 = right nacelle, GPIO 2 = battery ADC (270kΩ+100kΩ, ADC_11db, multiplier 3.83). Firmware (`Engine_Room_ESP.ino`) updated to match — new board installed in model 2026-06-18.
>
> **Nacelle polarity fix (2026-06-17):** Left and right nacelle connector footprints had positive and negative pads reversed on the EngRoom PCB. Discovered during assembly — nacelle LEDs would not light with correct wiring polarity. PCB updated in EasyEDA and new Gerbers exported. No firmware change needed. Hardware workaround: masked the reversed pads with solder mask, then ran wires from the now-disconnected connector pins to power-in pads left over from the original kit board design — correctly oriented and already on the PCB, making the polarity swap straightforward.
>
> **GPIO 9 strapping pin fix (2026-06-18):** Right nacelle was originally assigned to GPIO 9, which is the BOOT strapping pin on ESP32-C3. The 1.2kΩ base resistor into the NPN transistor base-emitter junction pulled GPIO 9 LOW at power-on, putting the chip into download mode (boot freeze). Left nacelle on GPIO 8 was unaffected — Xiao board has a stronger external pull-up on GPIO 8. Fix: right nacelle moved to GPIO 3 in firmware and PCB. Hardware workaround on current board: solder mask GPIO 9 trace, jump wire to GPIO 3. Old EngRoom board was not affected — nacelles were on GPIO 2/3, neither is a strapping pin.

> **EngRoom + Neck PCB power trace widening (2026-08-08):** VCC/GND traces widened to 0.8–1mm on both boards (no other changes). Enables an optional single power source build — route power through a hole drilled in the stand mount into EngRoom's 2-pin JST connector, through the EngRoom PCB, out the FFC to the Neck PCB's 2-pin connector (reusing what's normally power-in from a local neck battery), out through the neck to the spare 2-pin JST on Bridge PCB3 (unused in the normal build), then stock wiring from there to Bridge PCB1/PCB2. This is a permanent mod — the saucer and stardrive can no longer be physically separated once wired this way. See `README.md` for the full write-up.
>
> **EngRoom Photon 2x — new board variant (2026-08-18):** Separate PCB variant (`Engroom Photon 2x.zip`, not a revision of the main EngRoom board) adding a 2-pin connector for a second, aft photon torpedo LED — mirrors a mod builders had already been doing by hand on models with an aft photon LED not in the original kit. Uses GPIO9, the only unassigned pin on the Xiao ESP32-C3, previously avoided due to the boot strapping issue above. Wired **active-low** to sidestep that issue rather than repeat it: LED anode to 3.3V through an on-board 330Ω 0603 series resistor, cathode to GPIO9 — idle/floating state (pin pulled high) puts no current through the LED, so nothing loads the pin down at boot the way the GPIO9 nacelle transistor did. Firmware drives GPIO9 LOW to light the LED. Single LED at ~3.5–4.3mA runs directly off the GPIO, no transistor needed. **Firmware support:** implemented as an independent second fire control (its own charge/fire animation, not a mirror of the forward tube) in the work-in-progress `Engine_Room_ESP_Webpage/` sketch — see that folder's README. Not yet ported to the plain `Engine_Room_ESP.ino`.
>
> **Planned next step (2026-08-15, not started):** Bridge saucer VCC/GND currently arrive as two separate rails, one per saucer battery pack. Since the single-power-source mod lands all incoming power at one point (PCB3's spare JST), the two saucer battery input rails need to be tied together on PCB1/PCB2 so the single source feeds both. EasyEDA not yet updated; PCB files pending, repo push deferred.
>
> **Fuse + barrel jack for single-power-source builds (planning, 2026-08-28, not yet built):** external supply enters through a barrel jack outside the model, in series with an inline fuse (slow-blow, sized above the combined nominal draw — Bridge ~353mA + EngRoom ~133mA, see LED power budget below) and a basic reverse-polarity diode. All battery packs get unplugged when running this way — nothing in this design tolerates a battery pack and external supply both connected at once. Exact fuse rating, diode part, and jack size are intentionally left to the builder, stated as a build-your-own-judgment call in `README.md` rather than a specified BOM item — every build's access points and cable runs differ too much for one prescribed part to fit all of them.
>
> **Kit external-power fuse — 2.5A slow-blow (ordered 2026-09-06):** Separate item from the single-power-source mod's fuse above — this one is for the standard kit's optional 9V power path (wall adapter and/or a 9V USB-C PD breakout/trigger board under evaluation), feeding the battery-input JST directly. Confirmed **not** routed through the ESP32-S3's own USB-C port, which is sized for 5V and would risk damaging the regulator/USB PHY at 9V. 2.5A is well above normal draw (see LED power budget below — well under 1A per section) so it won't nuisance-trip on boot inrush, but still clears a real wiring fault/short before anything overheats. **Ships loose in the kit, not pre-installed** — buyer wires it into the external power lead themselves; recommended placement is inline with the wall/USB-C power outside the model so a blown fuse is a quick swap rather than a teardown. Needs a line in the kit's box-insert warning/instruction card (not yet designed — see DEVNOTES Fix Queue Good-to-have #10).

> **Wiring issue resolved — nav/photon connector (2026-05-20):** Nav and photon wires were soldered in reverse order on the neck board connector. Connector re-pinned 2026-05-20 — firmware was already correct, no sketch change needed. Permanent fix applied in PCB revision above.

> **EngRoom lower PCB voltage regulator standoff — fixed in PCB revision 2026-05-21.** Regulator moved to clear the standoff. Decoupling caps moved with it.

### LED Count and Power Budget

| Section | LED count | LED pairs | Current @ 7.4V | Current @ 8.4V |
|---|---|---|---|---|
| EngRoom (all LEDs) | 50 | 25 | 87.5mA | 107.5mA |
| Bridge (all LEDs) | 170 | 85 | 297.5mA | 365.5mA |

ESP32 quiescent (normal use, ESP-NOW active, no WiFi):
- Xiao ESP32-C3 (EngRoom): ~45mA
- ESP32-S3 (Bridge): ~55mA

**Total current draw — all LEDs on:**

| Section | @ 7.4V nominal | @ 8.4V full charge |
|---|---|---|
| EngRoom | ~133mA | ~153mA |
| Bridge | ~353mA | ~421mA |

Real-world draw is lower — nav lights blink at ~50% duty, not all groups active simultaneously.

### Battery Configuration and Runtime

| Section | Config | 350mAh cells | 1000mAh cells |
|---|---|---|---|
| EngRoom | 1 set (2S, 2 cells) | 350mAh | 1000mAh |
| Bridge | 2 sets (2S2P, 4 cells) | 700mAh | 2000mAh |

Total cells: 6 × 10440 LiPo (AAA form factor).

**Estimated runtime — all LEDs on (worst case):**

| Section | 350mAh cells | 1000mAh cells |
|---|---|---|
| EngRoom | ~2.6 hrs | ~7.5 hrs |
| Bridge | ~2.0 hrs | ~5.7 hrs |

> **Battery note:** Original cells were 350mAh. Replacement/additional cells ordered are 1000mAh rated 10440. Bridge is the limiting section — 350mAh cells give ~2 hours worst case; 1000mAh cells give ~5.7 hours.

**Observed runtime — 2026-05-22 (real-world session):**

~2.5 hours of active use including all-LEDs-on testing, multiple OTA reflashes, and general operation. Cell voltages at end of session (measured per cell):

| Section | Start | End | Notes |
|---|---|-----|---|
| Bridge (saucer) | ~4.2V/cell | ~3.33V/cell | Getting low — near safe discharge floor. Total pack ~6.66V. |
| EngRoom (stardrive) | ~4.2V/cell | ~3.66V/cell | Still some headroom. Total pack ~7.32V. |

Bridge drained faster as expected — 170 LEDs at ~353mA vs EngRoom's 50 LEDs at ~133mA. **Note: Bridge was running on only one set of cells (350mAh) — the second set was not installed.** Full 2S2P config would be 700mAh and would roughly double Bridge runtime. The faster drain vs EngRoom is entirely explained by the higher current draw on half the intended capacity. Consistent with the ~2-hour estimate for 350mAh cells. Charge before further use when cells reach ~3.3V/cell.

**Battery compartment contact issue (discovered 2026-05-22):** 10440 LiPo cells (AAA form factor) have a protective insulating wrapper that extends over the top of the positive terminal to prevent shorts. The dummy filler cells have the same wrapper. The metal contact spring in the battery compartment lid can catch on this wrapper when cells are inserted, preventing the spring from making solid contact with the terminal. There is no workaround — the wrapper cannot be removed or repositioned. **If the model has no power or behaves unexpectedly after a battery swap, the first thing to check is the battery contacts.** Remove and re-seat all cells, pressing them firmly until the compartment lid closes flush and the spring contacts sit squarely on the terminal ends.

### EngRoom Current Measurements (bench)

| Section | State | Current | Notes |
|---|---|---|---|
| Neck | Power on (all neck LEDs lit) | 0.25 A (250 mA) | Measured on bench PSU, 2026-05-20. Includes ESP32-C3 current (WiFi likely active during test — explains higher reading vs calculated ~133mA). |
| Lower EngRoom | — | pending | Measure once accessible |
| Bridge | — | pending | Measure once accessible |
| Full model | — | pending | Both sections powered, all LEDs on |

### EngRoom Power Options

Unlike the Bridge, the EngRoom has no DY-SV17F and no 5V requirement. The 2S (7.4V) 10440 LiPo setup is used for consistency with the Bridge, but it is not technically required. The main drawback of the current setup is that to recharge the batteries they have to be physically removed from the model.

Simpler alternatives for the EngRoom:

- **Rechargeable AAA (NiMH)** — 3x NiMH cells (~3.6V total). Drop-in swap with no wiring changes. Only modification needed is changing the **LED current-limiting resistors** to values appropriate for the lower voltage (see LED Resistors table above). **Do not change the transistor base resistors** — both populations are 1.2kΩ on the revised boards but only the LED resistors are supply-voltage-dependent. Update the BOM to the correct LED resistor value only — worth confirming against the schematic before ordering.
- **1S LiPo + USB charging circuit** — single cell with onboard charging (e.g. TP4056). Adds recharging without battery removal. Same LED resistor consideration applies — base resistors stay at 1.2kΩ.

Either option removes the need to pull batteries for charging at the cost of a LED resistor BOM change. The rechargeable AAA route is the least effort — no new components, just different LED resistor values.

**Mains/external power via stand (future option):** The model sits on a display stand with a cable channel. A USB-C PD trigger board set to 9V could supply power through the stand and into the stardrive section — eliminating batteries in EngRoom entirely for display use. A 9V regulated supply or USB-C PD source would replace the 2S LiPo pack. Powering the saucer (Bridge) from the same source would require a mod to route power up through the neck connection, which is feasible but would make separating the two model sections harder. Alternative for saucer: leave Bridge on its own battery pack, power EngRoom from the stand only.

**Back to 4.5V / 1S LiPo with USB charging (future option):** The original kit LEDs were designed for 4.5V (3× AAA). Changing the **LED current-limiting resistors** to values appropriate for 4.5V (or a 1S LiPo at 3.7–4.2V) would allow a simpler single-cell setup with onboard USB charging — same approach as the DataPad (SM5308 charger, USB-C accessible from outside). Requires an LED resistor BOM change on all boards and a new 1S charging circuit, but removes the need to ever pull batteries. Compatible with USB-C PD supply via stand if resistors are matched to the supply voltage. **Note:** The revised boards have transistor base resistors that are also 1.2kΩ — do not change these. Only the LED current-limiting resistors are supply-voltage-dependent. See LED Resistors section for the full breakdown and the ⚠️ warning about the two populations.

**LIR2032 coin cell option (considered, not pursued):** The original kit includes 3× dual CR2032 holders (2 cells each = 6V per holder) used for section lighting. Standard CR2032s are 3V primary cells, not compatible with the 2S LiPo circuit. However, LIR2032 rechargeable lithium coin cells have the same 3.6–4.2V range per cell as 10440s — meaning 2× LIR2032 in series would match the 2S 10440 pack voltage. The 3 existing coin cell holders could in theory be wired in parallel with the 10440 pack to add capacity without modifying the compartments. Decided against: current runtime is adequate, wiring in the coin cell holders adds complexity and the holders are not well positioned for this purpose, and LIR2032 capacity (typically 70–100mAh each) adds only minor capacity gain per holder.

---

## Saucer Lighting — Section Map

Wiring color codes:

| Code | Colors |
|---|---|
| RB | Red / Black |
| RBlu | Red / Blue |
| YG / Gy | Yellow / Green |
| YW / WY | Yellow / White |
| GW | Green / White |
| YB | Yellow / Black |

### Saucer Sections by PCB and Connector

| Section | Top Connectors / PCB | Bottom Connectors / PCB |
|---|---|---|
| 1 | 36H 44D 28F — PCB 3,2,1 | 99C 83D (2-pin board 2 right) 65E*YG 99C*YB — PCB 1,2,3 |
| 2 | 24F 24E 18Fx2 40I 40H — PCB 1 | 76D (2-pin board 3 inboard) 62C 62C 01U*YB 62C 62C 71F — PCB 2,3 |
| 3 | 32C 48E 52C — PCB 2 | 76D* (2-pin board 3 outboard) 81E 105I#3 105I#2*RB — PCB 3 |
| 4 (top only) | 54D 53H 54D — PCB 3 | — |
| 5 | 35F 33C*YB 34G — PCB 2,3 | 101I 101I 101H 99C*R&BLU — PCB 3 |
| 6 | 43K 41H 42C — PCB 2 | 88G 88H — PCB 3 |
| 7 | 26E 27F 25E — PCB 1 | 84I 84H 84H — PCB 3 |
| 8 | 22K 22K 04J — PCB 1 | 73Gx3 (3 separate 4-pin connections) — PCB 2 |
| 9 | 04J 04J 19Ex4 20E 20E*RB 21I*YB — PCB 1 | 65E*RB 65E 60G 60H 67E 67E*YG — PCB 1,2 |
| 10 | 21I*RBlu 20E*YW 37C 38C — PCB 1 | 67E*RB 78H 78G 78G*RB — PCB 2,3 |
| 11 | 29J 30D 39F — PCB 2 | 78G*YW 92I 92H*YB — PCB 3 |
| 12 | 45D 46F 47F — PCB 2 | 92H*RBlu 96G 96G*YB — PCB 3 |
| 13 | 51E 50E*YW 49F — PCB 2 (50E split w/ impulse) | 96G*RBlu 107H 107I 105I*GY#2 105I#1*RB — PCB 3 |
| 14 | 01U*RBlu 01T — PCB 2 | 105I#1*YG 99D 83D — PCB 2,3 (2-pin board 2 left) |
| 15 (Bridge) | 01V — PCB 2 | — |
| 16 & 17 (Impulse) | 33C*RBlu 50E*RB — PCB 2,3 | — |
| 18 (Nav lights) | 58H 58E 58E 58F 58G — PCB 1 | — |

> Layout rule: always work **outer ring → inner ring**.
> "See Note" entries = 4-pin/2-LED connections split across panels — confirm wire combos once final layout is set.

---

## Upper Saucer Panel Map

Outer ring → inner ring order.

**Ring 1 (U1):**
| Panel | Connectors |
|---|---|
| U1-01 | 36H 36H |
| U1-02 | 44D 44D |
| U1-03 | 28F |
| U1-04 | 24F 24E 24E |
| U1-05 | 18F 18F / 18F 18F |
| U1-06 | 40I 40I 40H |
| U1-07 | 32C 32C |
| U1-08 | 48E 48E |
| U1-09 | 52C 52C |

**Ring 2 (U2):**
| Panel | Connectors | Notes |
|---|---|---|
| U2-01 | 35F 35F | |
| U2-02 | 43K 43K | |
| U2-03 | 27F 27F | |
| U2-04 | 22K 22K | |
| U2-05 | 19E | Split — also feeds U3-11 |
| U2-05 | 19E 21I | 21I is for panel U33-12 |
| U2-06 | 21I 37C | |
| U2-08 | 39F 39F | |
| U2-09 | 47F 47F | |
| U2-10 | 51E | |

**Ring 3 (U3):**
| Panel | Connectors | Notes |
|---|---|---|
| U3-01 | 54D 53D 54D | |
| U3-02 | 33C 33C | One 33C = impulse engines |
| U3-03 | 34G 34G | |
| U3-04 | 41H 41H | |
| U3-05 | 42C 42C | |
| U3-06 | 26E 26E | |
| U3-07 | 25E 25E | |
| U3-08 | 22K 22K | Split with U2-04 |
| U3-09 | 04J 04J | |
| U3-10 | 04J 04J 04J 04J | |
| U3-11 | 19E x6 | Split with U2-05 and U2-06 |
| U3-12 | 20E 20E 20E | |
| U3-13 | 20E 37C | |
| U3-14 | 38C 38C | |
| U3-15 | 29J 29J | |
| U3-16 | 30D 30D | |
| U3-17 | 45D 45D | |
| U3-18 | 46F 46F | |
| U3-19 | 49F 49F | |
| U3-20 | 50E 50E | Split with impulse engine |
| Bridge | 01V 01V | |
| Bridge decks + lower | 01T 01T 01U | 01U split with L1-06 |

---

## Lower Saucer Panel Map

Outer ring → inner ring order.

**Outer ring (L02):**
| Panel | Connectors | Notes |
|---|---|---|
| L02-01 | 101I 101I 101H (outer) / 101I 101I (inner) | |
| L02-02 | 88H 88H / 88G 88G | |
| L02-03 | 84H 84H 84H 84H / 84I 84I | |
| L02-04 | 73G x6 | |
| L02-05 | 65E (see notes) / 65E 65E | |
| L02-06 | 60G 60G | |
| L02-07 | 67E 67E / 67E (see notes) | |
| L02-08 | 78H 78H 78G 78G / (67E, 78G see notes) | |
| L02-09 | 92I 92I / (78G, 92H see notes) | |
| L02-10 | 96G 96G / (92H, 96G see notes) | |
| L02-11 | 107H 107I 107I / (96G, 105H see notes) | |

Saucer/neck transition: 105H and 99B add into L2 panels (see notes).

**Inner ring (L01):**
| Panel | Connectors | Notes |
|---|---|---|
| L01-01 | 99B 99B | |
| L01-02 | 83D | |
| L01-03 | 65E | See notes |
| L01-04 | 71F | |
| L01-05 | 62C 62C | |
| L01-06 | 01U | Split with bridge decks |
| L01-07 | 62C 62C | |
| L01-08 | 76D | Split with L01-09 |
| L01-09 | 76D | Split with L01-08 |
| L01-10 | 81D | |
| L01-11 | 105H 105H | Split with L02-11, neck/saucer transition |

Center under bridge: 105I (split bridge/L2-11), 99D, 83D (split bridge/L1-02).

---

## Split 4-Pin Connector Reference

All connectors marked `*` on the PCB label are split — the 4-pin connector is shared between two different lighting sections. Only the specified pins belong to the section you are wiring. Connecting the wrong pins will light the wrong panel group.

**Wire colour codes:** RB = Red/Black · RBlu = Red/Blue · YB = Yellow/Black · YG/GY = Yellow/Green · YW/WY = Yellow/White

Organised by connector for easy lookup during assembly:

| Connector | Pins 1–2 | Wire | Pins 3–4 | Wire | Notes |
|---|---|---|---|---|---|
| 01U | Section 2 | YB | Section 14 | RBlu | |
| 20E | Section 9 | RB | Section 10 | YW | ⚠️ Verify on assembly — known candidate for backwards LED connection |
| 21I | Section 9 | YB | Section 10 | RBlu | |
| 33C | Section 5 | YB | Section 16 & 17 | RBlu | |
| 50E | Section 13 | YW | Section 16 & 17 | RB | Section 13 share is split with impulse engines |
| 65E | Section 9 | RB | Section 1 | YG | |
| 67E | Section 10 | RB | Section 9 | YG | |
| 78G | Section 11 | YW | Section 10 | RB | |
| 92H | Section 11 | YB | Section 12 | RBlu | |
| 96G | Section 12 | YB | Section 13 | RBlu | |
| 99C | Section 1 | YB | Section 5 | RBlu | |
| 105I #1 | Section 13 | RB | Section 14 | YG | Split |
| 105I #2 | Section 3 | RB | Section 13 | YG | Split |
| 105I #3 | Section 3 | — | Section 3 | — | Not split — 4-pin, all pins Group 3 |

> ⚠️ **105I assembly note:** Three physically similar 4-pin connectors labelled 105I. #3 is not split — all pins belong to Group 3. #1 and #2 are split connectors whose pins span Groups 3, 13, and 14 across both. Verify each connector matches its label before seating — wrong connector = wrong group lit.

---

## Engine Section (Stardrive) Board Notes

- All lower lights on same circuit — not easy to separate
- Top LEDs: left and right independently
- Top middle dorsal: individual control
- Deflector: 2 individual LEDs on a 4-pin connector
- Option to add 2nd 2-pin connector for aft photon launcher

### Engine Section Connector Positions

| Position | Description |
|---|---|
| 79G | Top front right |
| 86H | Top middle right |
| 95J | Lower front right |
| 03G | Deflector (2 LEDs, 4-pin) |
| 84G | Top mid left |
| 77L | Top front left |
| 74G | Beacon lights |
| 93G | Lower back / lower front left |
| 101J | Lower back |
| 71E | Top rear left |
| 74H | Top rear right |
| 102F | Power IN |
| 81E | Top middle dorsal (2-pin, 1 LED) |

---

## Battle Bridge PCB Notes

- Saucer PCB 1 starts on stage 31
- Left Battle Bridge (LBB): connectors 11d, 10f, 9e, 11e (back of neck)
- Right Battle Bridge (RBB): 22L
- Aft battle bridge: 11d 10f 9e 11e
- Flashing lights: pins 3 & 4
- Photon launcher: pins 1 & 2 — **note: change to red LED**
- Impulse engine: 14d (2-pin)

### Pull-down resistors — do not fit, do not include in future revisions

The Left Battle Bridge board had a fault where fitting the base pull-down resistor caused all LEDs on the board to stay permanently on. Originally attributed to a copper pour clearance fault in EasyEDA, but testing never confirmed a direct short.

**Actual root cause (identified retroactively):** The battle bridge signal ran through the FFC back to GPIO 9 on the ESP32-C3 — the BOOT strapping pin. The pull-down resistor was pulling GPIO 9 LOW at power-on through the FFC, putting the chip into download mode. With the ESP in download mode, GPIO pins floated undefined, turning transistors on and keeping LEDs permanently lit. Same root cause as the later GPIO 9 nacelle boot freeze (see strapping pin fix 2026-06-18 above). The original boards used 10kΩ base resistors — on their own not enough to trigger the strapping pin, but the pull-down on top tipped it over. The revised boards changed to 1.2kΩ base resistors, which pull almost 10× harder — that's why the nacelle on GPIO 9 triggered the boot freeze on new boards without any pull-down at all.

**Resolution:** pull-down resistors removed from all battle bridge boards. Without the extra pull-down, the 10kΩ base resistor alone wasn't strong enough to hold GPIO 9 low at boot. Board operates correctly without them.

**Design decision:** do not include base pull-down resistors on any future board revisions. The ESP32 drives all LED pins as `OUTPUT` and actively holds them LOW when not commanded — this is lower impedance than any external pull-down resistor and makes the resistors redundant.

---

## Bridge PCB Revision 2026-05-21

All three Bridge PCBs revised. Current boards unchanged — firmware update deferred until new boards fitted.

- **PCB 2:** B0530W Schottky diode (SOD-123, 0.5A 30V, Vf≈0.34V) added on each 3.3V regulator output — prevents USB back-feed through battery regulator when battery is off. USB-C D+ and D- pins corrected (were swapped on original layout, required physical workaround to connect). **Hand-assembly substitute:** SS14 (SMA, 1A 40V) — electrically better, SMA body overhangs SOD-123 pads but both ends make solid contact. EasyEDA BOM retains B0530W for JLCPCB assembly.
- **PCB 2 EN pin circuit — fixed 2026-05-28:** Original schematic had the RC circuit reversed (3.3V → cap → EN → resistor → GND), holding EN low during boot. 100nF cap across reset switch also removed (unnecessary). EasyEDA updated to correct circuit: **3.3V → 10kΩ → EN pin → pushbutton → GND.** No capacitors. Confirmed working with new boards.
- **PCB 3:** Non-UART mode resistors removed from DY-SV17F mode selection array — only UART configuration resistors retained. Simplifies board with no functional change.
- **All boards:** Group 9 LED pin now correctly split between groups 9 and 1 — was only connected to group 9 on original layout. Battery voltage monitor added on GPIO 2 (ADC1) — voltage divider R1=270kΩ, R2=100kΩ on PCB, tapped from local supply rail close to GPIO 2. Maps 6.0V–8.4V → 1.62V–2.27V on ADC. Use ADC_11db attenuation in firmware.

> **PCB 3 — 0Ω regulator bypass jumper (2026-08-15):** Added a 0Ω 0603 resistor footprint in parallel with the linear regulator that steps the battery supply down to 5V for the DY-SV17F. PCB 3 is the only board with a 5V rail (for the sound module), so this is the only board that needs it. Lets a future 5V-input build skip a respin: depopulate the regulator, populate the 0Ω resistor to feed VCC straight from the 5V input, and swap the LED current-limiting resistors for the 5V-appropriate value (per the LED resistor table above).

---

## Nacelle PCB Notes

One board design used ×2 — port and starboard nacelles are identical boards. All components desoldered from original nacelle boards and transplanted to new PCBs, except the original power connector (footprint present on new board as a VCC injection point but not normally populated).

### SMD LEDs (YLED1206B, 1206)

6× blue 1206 SMD LEDs — main nacelle bussard collector glow ("warp flash" effect). Standard SMT assembly. Wired as 3 parallel pairs, each pair sharing a single current-limiting resistor, all 3 pairs switched together by one MMBT2222A transistor. LED specs: 20mA rated, Vf 2.6–3.1V.

**Current-limiting resistors (confirmed 2026-06-09, installed 2026-08-15):** Each parallel-pair resistor = **240Ω** (~8.75mA per LED at 7.4V nominal). Because each resistor serves a parallel pair, current won't split perfectly evenly (Vf mismatch), but the nacelle diffusers mask any visible imbalance — the only constraint is keeping the hotter LED under 20mA worst-case, which 240Ω satisfies comfortably. Chosen over the stock 820Ω-equivalent value purely to give a brighter warp-flash effect; see `Engine_Room_ESP/README.md` for why continuous brightness is still limited in firmware despite the higher available current.

### Through-hole footprints — not all are LEDs

The 4× through-hole LED footprints (204-10SUGC/S400-A5-L) serve different purposes and are all hand-assembled:

| Footprint use | Description | Resistor (0603) |
|---|---|---|
| 2×3×4 square LED | Actual square LED fitted directly to board | **470Ω** |
| VCC injection point | Replicates original power connector — not normally used, available if board needs external power injected for bench testing | — |
| Forward nacelle LED | Red 3mm LED on ~3" wire leads — runs to mounting location inside nacelle | **470Ω** |
| Nav lights | Two 3mm LEDs pigtailed in parallel, ~3" wire leads each — driven from nav lights transistor | **1.2kΩ** |

470Ω chosen to match ~8.75mA per LED of the parallel SMD pairs at 7.4V nominal, installed 2026-08-15. Nav lights 1.2kΩ unchanged from standard board value.

Original board photos retained for reference wiring layout.

---

## PCB Gerber Files

Located in `enterprise documentation/PCB Design/`:

| Gerber zip | BOM | Pick & Place | Description |
|---|-----|---|---|
| BridgePCB1.zip | BOM_BridgePCB1.xlsx | PickAndPlace_BridgePCB1.xlsx | Saucer PCB 1 |
| BridgePCB2.zip | BOM_BridgePCB2.xlsx | PickAndPlace_BridgePCB2.xlsx | Saucer PCB 2 (ESP32-S3, regulators, USB-C) |
| BridgePCB3.zip | BOM_BridgePCB3.xlsx | PickAndPlace_BridgePCB3.xlsx | Saucer PCB 3 (DY-SV17F sound player) |
| EngRoomPCB.zip | BOM_EngRoomPCB.xlsx | PickAndPlace_EngRoomPCB.xlsx | Engine room PCB (Xiao ESP32-C3) |
| Engroom Photon 2x.zip | BOM_Engroom Photon 2x.xlsx | PickAndPlace_Engroom Photon 2x.xlsx | Engine room PCB variant — adds 2-pin GPIO9 connector for front + aft photon torpedo LED connections |
| NeckPCB.zip | BOM_NeckPCB.xlsx | PickAndPlace_NeckPCB.xlsx | Neck PCB |
| NacellePCB.zip | BOM_NacellePCB.xlsx | PickAndPlace_NacellePCB.xlsx | Nacelle LED controller (used ×2) |

EasyEDA project files in `PCB Design/projects/` — main project: `enterprise pcbs.eprj`.

---

## 3D Print Files

All 3D print files are in `enterprise documentation/`.

### DataPad Case — `Data Pad stl/`

| File | Description |
|---|---|
| `shell data pad top.stl` | Top half of DataPad PADD case |
| `shell data pad bottom.stl` | Bottom half of DataPad PADD case |
| `Body23.stl` | Internal body/mount component |

### PCB Test-Fit Prints — `pcbs test prints/`

Test prints used to verify PCB dimensions before ordering. Print these before placing a JLCPCB order to confirm boards will fit in the model.

| File | Description |
|---|---|
| `PCB1.stl` | Test fit for saucer PCB 1 |
| `pcb 2&3.stl` | Test fit for saucer PCB 2 & 3 stack |
| `Necell test.stl` | Test fit for nacelle PCB |

### WarpCore — `Warp_Core/`

Full archive of the original Thingiverse design used for this build. The original listing (`thingiverse.com/thing:1656741`) is no longer available, so the complete download is preserved here.

**Design:** ST:TNG Warp Core by **ElmoC**
**License:** Creative Commons Attribution — Non-Commercial — No Derivatives (CC BY-NC-ND 3.0)
**Attribution file:** `attribution_card.html`, `LICENSE.txt`, `README.txt`

The original design uses a custom PCB (OSH Park order) and an Arduino Nano with a non-ESP32 sketch (`WarpCore/WarpCore.ino` — AVR only, uses SoftPWM, kept for reference). This project replaces that with an Arduino Nano ESP32 and a custom sketch.

| File/Folder | Description |
|---|---|
| `files/*.stl` | All printable parts (chamber, injectors, light rings, uprights, base, etc.) |
| `files/*.brd` / `*.zip` | Original Eagle PCB files — unmodified |
| `WarpCore/WarpCore.ino` | Original Arduino sketch — unmodified, AVR only |
| `files/Instructions.pdf` | Original build instructions |
| `images/` | Original Thingiverse photos |

**Note on alternatives:** Other warp core designs exist on Thingiverse in different sizes and configurations, including versions designed around ARGB LED strips rather than discrete NPN-transistor-driven LEDs. These may be worth considering for anyone building from scratch — ARGB gives colour control (the moving green/blue glow effect) vs. the single-colour PWM approach used here.

---

## DataPad (Waveshare 7" ESP32-S3) — Physical Build

3D-printed PADD prop case housing the Waveshare ESP32-S3-Touch-LCD-7 (800×480, 7" display). Self-contained unit with internal 1S LiPo, two independent charging paths, and a local sound module.

### Battery

3000mAh 1S LiPo, internal to the printed case.

**Observed runtime — 2026-05-22:** ~7 hours of active use including UI interaction, OTA reflashing, ESP-NOW communication, and screen on throughout. Battery was not fully depleted at the end of the session — exact remaining charge not measured. Power draw not yet characterised (screen backlight + ESP32-S3 + DY1703A audio player — screen likely dominates). The 3000mAh capacity is generous for this use case; runtime is not a concern for normal display sessions.

### Power Switch

SPDT 2-position switch wired as a transfer switch on the battery positive rail. The common terminal connects to battery+. The two throws connect to the load rail and the SM5308 charger BAT pin respectively — so only one path is connected to the battery at a time.

- **ON:** battery connects to Waveshare board and all electronics. External SM5308 charger is disconnected from battery. The Waveshare board has a built-in LiPo charger that could charge the battery in this state, but the Waveshare USB-C ports are not accessible with the case closed and fully assembled — so in practice charging does not occur in the ON position during normal use.
- **OFF:** Waveshare board and all electronics are disconnected from battery. External SM5308 charger is connected to battery and charges it. This is the only charging path available without disassembling the case.

The SPDT transfer arrangement naturally prevents the SM5308 and the load from being on the battery simultaneously, which avoids the charge termination issue that occurs when a load draws current through an SM5308 (no power-path management on that IC).

### Charging

Only one charging method is usable without opening the case:

**External SM5308 charger — USB-C port on case exterior:**

1S LiPo charger module based on the **SM5308** IC. BAT pin connects to the SPDT switch (OFF throw). Charge by flipping the switch to OFF and connecting USB-C to the external port. The board is unpowered while charging.

The Waveshare board has a built-in LiPo charger accessible via its own USB-C ports, but those ports are not reachable when the case is closed. That path is only available during bench work with the case open.

### Sound — DY1703A

- DY Electronics DY1703A module, RS485 connector, UART1: TX=GPIO16, RX=GPIO15, 9600 baud
- Same DY Electronics 0xAA frame protocol as the Bridge DY-SV17F — identical command structure
- Requires 5V; supplied by a small boost converter from the 3.3V rail (Waveshare only exposes 3.3V)
- SD card: files `00001.mp3`–`00044.mp3` in root (no folders). Full file map in `SOUND_MAP.md`.
  - Files 1–25: shared with Bridge DY-SV17F — same file number = same sound on both players
  - Files 26–44: DataPad-only sounds (touch feedback, voiced alerts, ambient loops, easter eggs)

### Mounting

Case attaches to Waveshare screen with M3×4 screws. Waveshare USB-C port is not accessible without disassembly — use the external SM5308 USB-C port for normal charging.

---

## DataPad 2.8" (Waveshare ESP32-S3-Touch-LCD-2.8)

**Board:** Waveshare ESP32-S3-Touch-LCD-2.8 (240×320 SPI, CST328 touch)
**Sketch:** `Data_Pad_240x320/Data_Pad_28/Data_Pad_28.ino`
**mDNS:** `DataPad2.local`

### Power latch

The board uses a hardware power latch circuit. Pressing the power button momentarily applies battery power; firmware must drive **GPIO 7 HIGH** during `setup()` to hold the MOSFET latched. Without it the board powers off the instant the button is released.

`BAT_Init()` sets GPIO 7 HIGH as its first action — this is the `PWR_HOLD_PIN` define in `BAT_Driver.h`.

To power off from software: `digitalWrite(7, LOW)`.

### GPIO assignments

| GPIO | Function |
|---|---|
| 5 | LCD backlight PWM |
| 7 | Power hold latch (OUTPUT, HIGH = on) |
| 8 | Battery ADC (voltage divider) |
| 39 | LCD RST |
| 40 | LCD SCLK |
| 41 | LCD DC |
| 42 | LCD CS |
| 45 | LCD MOSI |

---

## WarpCore Hardware

**Board:** Arduino Nano ESP32 (drop-in replacement for original Arduino Nano)
**Sketch:** `WarpCore_ESP32/WarpCore_ESP32.ino`
**mDNS:** `WarpCore.local`
**MAC:** `20:6e:f1:31:da:54`

Original Arduino Nano sketch (`WarpCore/WarpCore.ino`) kept as reference only — uses SoftPWM library, AVR-only, not portable to ESP32.

**Original assembly note:** First build used solid-core ethernet wire throughout. Solid core has no flex tolerance — connections broke during handling and required resoldering. Use stranded wire for any rework.

### Pin assignments

| Pin | Function |
|-----|---|
| A4, A3, A2, A1, A0 | Chase LEDs 1–5 (NPN transistors) |
| D2, D3, D4, D5, D6 | Chase LEDs 6–10 (NPN transistors) |
| A5 | Ambient LED (NPN transistor) |
| A7 | Speed pot (wiper; ends to 3.3V and GND) |
| D7 | LD2410C OUT (presence detection) |

**Note:** Use `D2`–`D6` Arduino constants in firmware, not raw integers `2`–`6`. On the Nano ESP32, raw `2` = GPIO 2 = A1 on the connector — wrong pin.

### LD2410C mmWave Presence Sensor

- **Supply:** 5V from a small boost converter stepping up the Nano ESP32's 3.3V rail
- **Logic:** 3.3V OUT pin, push-pull — no pull-up resistor needed on D7
- **Configuration:** UART pins not yet wired (only OUT is connected). Plan is a spare Arduino Nano as USB-to-serial passthrough to HLKRadarTool on a PC for detection-range/gate-sensitivity tuning — see `DESIGN_STORY.md` Presence Detection section. OUT = HIGH on presence, LOW on clear.
- **Firmware behaviour:** rising edge on D7 → sends `LED_RADAR_TRIG` to DataPad only (not directly to Bridge/EngRoom — DataPad holds the authoritative on/off state and calls `PowerUpAll()` if the model is off, avoiding a startup/trigger loop). 3-second debounce lockout. Ignored if model already on.
- **Enable/disable toggle:** implemented — SENSORS ON/OFF button on DataPad Screen 2, persisted to NVS (`radar_on`) on both WarpCore and DataPad via `LED_RADAR_EN`.
- **Sensor housing:** new WarpCore base with an integrated sensor bay (single 0.4mm PLA wall as the radar window) is designed and printed — not yet fitted. See `DESIGN_STORY.md` "Remaining to Complete the Project".

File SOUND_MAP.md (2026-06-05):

# Sound Map — Bridge DY-SV17F & DataPad DY1703A

## Overview

Two separate sound players, two separate SD cards. File numbers 1–25 are identical on both
cards (same sounds, same slots) so BRIDGE/PAD/BOTH destination mode needs no translation.
Files 26+ exist on the DataPad card only.

| Player | Unit | UART | Baud | Storage | Files |
|---|---|---|---|---|---|
| DY-SV17F | Bridge ESP32-S3 | UART2 TX=GPIO17 RX=GPIO18 | 9600 | 4MB flash | 00001–00025 |
| DY1703A | DataPad ESP32-S3 | UART1 TX=GPIO16 RX=GPIO15 | 9600 | SD card | 00001–00042 |

Default volume: 15 / 30 on both players.

---

## Sound Sources

**Star Trek sounds (files 01–42):** All TNG audio clips sourced from [TrekCore Audio Archive](https://www.trekcore.com/audio/). The site has a much larger selection than what's used here — the files listed below are just what worked for this build. You can substitute any clips you prefer, just keep in mind which slots are auto-triggered by firmware effects (startup, shutdown, damage) versus which are manual-only buttons on the DataPad. Those distinctions are noted in the trigger map and button table below. As long as the slot numbers match, the content is up to you.

**Touch sounds (files 26–27):** Generic UI click sounds — any two short click/beep sounds will work.

**Star Wars easter egg sounds (files 43–44):** Not included in this repository. Source from your own soundtrack or digital purchase. Files 43 and 44 can be any two audio files — the button code expects them at those slot numbers regardless of content.

---

## Bridge File Map (DY-SV17F) — files 01–25

Ready-to-copy files: `sounds/DY_Player/` — copy all 25 files to the root of the Bridge player flash.
Total size: ~3.9MB (within 4MB flash limit).

> If the player rejects files, remove `00003.mp3` (tng_poweringdown, 402KB) first —
> it is the least essential file and freeing it drops total size to ~3.5MB.

### Power — files 01–03
Auto-trigger: **startup always plays file 01**; **shutdown plays random 02–03**

| File | Original filename | Description |
|---|---|---|
| 00001.mp3 | tng_poweringup.mp3 | Power-up / systems online — startup trigger |
| 00002.mp3 | ship_shutdown.mp3 | Ship shutdown sound |
| 00003.mp3 | tng_poweringdown.mp3 | Power-down sequence |

### Alerts — files 04–06
Auto-trigger: damage sequence; manual ALERTS button on DataPad

| File | Original filename | Description |
|---|---|---|
| 00004.mp3 | alert08.mp3 | Alert beep — very short |
| 00005.mp3 | alert01.mp3 | Alert tone 1 — short |
| 00006.mp3 | alertklaxon_clean2.mp3 | Red alert klaxon — long, cut off at 2.5s |

> Files 04 and 06 are used as the damage alert (randomly chosen). File 05 is manual only.

### Damage — files 07–12
Auto-trigger: **random from 07–12** after the alert klaxon

| File | Original filename | Description |
|---|---|---|
| 00007.mp3 | largeexplosion1.mp3 | Large explosion hit |
| 00008.mp3 | largeexplosion3.mp3 | Large explosion hit 2 |
| 00009.mp3 | shield_sizzle.mp3 | Shield impact / sizzle |
| 00010.mp3 | smallexplosion2.mp3 | Small explosion |
| 00011.mp3 | starboardnacellenotfunctional_ep.mp3 | Voiced: "Starboard nacelle not functional" |
| 00012.mp3 | tng_powerloss.mp3 | Power loss sound |

### Warp — files 13–18
Manual only — WARP button on DataPad cycles through these

| File | Original filename | Description |
|---|---|---|
| 00013.mp3 | tng_flyby2.mp3 | Ship flyby whoosh |
| 00014.mp3 | tng_warp4_clean.mp3 | Warp engage — warp 4 |
| 00015.mp3 | tng_warp7.mp3 | Warp engage — warp 7 |
| 00016.mp3 | tng_warp_exit.mp3 | Warp exit / drop out |
| 00017.mp3 | tng_warp_flash.mp3 | Warp flash effect |
| 00018.mp3 | tng_warp_out2.mp3 | Warp out |

### Weapons — files 19–25
Manual only — WEAPONS button on DataPad cycles through these

| File | Original filename | Description |
|---|---|---|
| 00019.mp3 | tng_fireallweapons_ep.mp3 | Voiced: "Fire all weapons" |
| 00020.mp3 | tng_phaser_clean.mp3 | Phaser fire |
| 00021.mp3 | tng_phaser_strike.mp3 | Phaser strike impact |
| 00022.mp3 | tng_torpedo2_clean.mp3 | Photon torpedo 2 |
| 00023.mp3 | tng_torpedo_clean.mp3 | Photon torpedo |
| 00024.mp3 | tng_weapons2_clean.mp3 | Weapons fire 2 |
| 00025.mp3 | tng_weapons_clean.mp3 | Weapons fire |

---

## DataPad-Only File Map (DY1703A) — files 26–42

Files 01–25 on the DataPad SD card are identical copies of the Bridge files above.
Files 26–42 are DataPad-only — never sent to the Bridge via ESP-NOW.

Source files are in the `sounds/` subfolders listed below.
Name them `00026.mp3`, `00027.mp3` etc. when copying to the DataPad SD card.

### Touch feedback — files 26–27
Played locally on button press. DataPad only.

| File | Source file | Description |
|---|---|---|
| 00026.mp3 | `sounds/Data Pad sounds/padd_1.mp3` | UI touch sound 1 |
| 00027.mp3 | `sounds/Data Pad sounds/padd_2.mp3` | UI touch sound 2 |

### Voiced alerts — files 28–31
Richer alert lines with voice. DataPad only.

| File | Source file | Description |
|---|---|---|
| 00028.mp3 | `sounds/alerts with voices/tng_red_alert1.mp3` | Red alert with voiced klaxon |
| 00029.mp3 | `sounds/alerts with voices/lifesupportfailurealldecksabandonship_ep.mp3` | "Life support failure, all decks abandon ship" |
| 00030.mp3 | `sounds/alerts with voices/warningprimaryshieldsfailing_ep.mp3` | "Warning: primary shields failing" |
| 00031.mp3 | `sounds/alerts with voices/warningstructuralintegrity_ep.mp3` | "Warning: structural integrity..." |

### Ambient — files 32–38
Background loop sounds. DataPad only.

| File | Source file | Description |
|---|---|---|
| 00032.mp3 | `sounds/ambient sounds/ambient_bridge_1.mp3` | Bridge ambience 1 |
| 00033.mp3 | `sounds/ambient sounds/tng_bridge_1.mp3` | Bridge ambience 2 |
| 00034.mp3 | `sounds/ambient sounds/tng_bridge_2.mp3` | Bridge ambience 3 |
| 00035.mp3 | `sounds/ambient sounds/tng_bridge_3.mp3` | Bridge ambience 4 |
| 00036.mp3 | `sounds/ambient sounds/engineering_clean.mp3` | Engineering ambience |
| 00037.mp3 | `sounds/ambient sounds/tng_engine_1.mp3` | Engine room 1 |
| 00038.mp3 | `sounds/ambient sounds/tng_engine_2.mp3` | Engine room 2 |

### Easter eggs — files 39–42
DataPad only.

| File | Source file | Description |
|---|---|---|
| 00039.mp3 | `sounds/Funny add in joke to play/selfdestructsequenceinitiatedwarpcorebreach_ep.mp3` | "Self destruct sequence initiated, warp core breach" |
| 00040.mp3 | `sounds/Funny add in joke to play/selfdestructsequenceterminated_ep.mp3` | "Self destruct sequence terminated" |
| 00041.mp3 | `sounds/Funny add in joke to play/unabletocomply.mp3` | "Unable to comply" |
| 00042.mp3 | `sounds/Funny add in joke to play/youarenotauthorisedtoaccessthisfacility_clean.mp3` | "You are not authorised to access this facility" |
| 00043.mp3 | *(user-supplied — not included in repo)* | Star Wars main theme |
| 00044.mp3 | *(user-supplied — not included in repo)* | Imperial March (Darth Vader's Theme) |

---

## Bridge Trigger Map

| Event | Behaviour | Code location |
|---|---|---|
| Startup sequence begins | Always plays file 01 (tng_poweringup) | `Bridge_ESP.ino` — `LED_STARTUP` case |
| Shutdown sequence begins | Random file 02 or 03 | `Bridge_ESP.ino` — `LED_SHUTDOWN` case |
| Damage effect starts | Random file 04 or 06 (alert) for 2.5s, then random file 07–12 | `Bridge_ESP.ino` — `initElecShort()` + `updateElecShort()` |
| Damage cancelled/expired | Sound stops | `Bridge_ESP.ino` — `stopElecShort()` |

---

## DataPad Sound Screen Buttons

Each button cycles through its category. Label updates to show `CATEGORY\nN / total` on each press.
Destination (BRIDGE / PAD / BOTH) set via toggle on Screen2.

| Button | Category | File range | Destination |
|---|---|---|---|
| POWER | Power sounds | 01–03 | BRIDGE / PAD / BOTH |
| ALERTS | Alert tones | 04–06 | BRIDGE / PAD / BOTH |
| DAMAGE | Damage effects | 07–12 | BRIDGE / PAD / BOTH |
| WARP | Warp sounds | 13–18 | BRIDGE / PAD / BOTH |
| WEAPONS | Weapon effects | 19–25 | BRIDGE / PAD / BOTH |
| STOP | — | — | BRIDGE / PAD / BOTH |
| Volume slider | — | 0–30 | Bridge only (DataPad volume set separately on Screen2) |
| REPEAT | — | off / one / all | Bridge only |

---

## Code Constants

### Bridge (Bridge_ESP.ino)

```cpp
#define SND_POWERUP_FILE      1
#define SND_SHUTDOWN_FIRST    2
#define SND_SHUTDOWN_LAST     3
#define SND_DMG_ALERT_1       4
#define SND_DMG_ALERT_2       6
#define DMG_ALERT_MS       2500
#define SND_ALERT_FIRST       4
#define SND_ALERT_LAST        6
#define SND_DAMAGE_FIRST      7
#define SND_DAMAGE_LAST      12
#define SND_WARP_FIRST       13
#define SND_WARP_LAST        18
#define SND_WEAPONS_FIRST    19
#define SND_WEAPONS_LAST     25
```

### DataPad (Data_Pad.ino) — shared range

```cpp
// Files 01–25 match Bridge exactly
#define SND_POWER_FIRST       1
#define SND_POWER_LAST        3
#define SND_ALERT_FIRST       4
#define SND_ALERT_LAST        6
#define SND_DAMAGE_FIRST      7
#define SND_DAMAGE_LAST      12
#define SND_WARP_FIRST       13
#define SND_WARP_LAST        18
#define SND_WEAPONS_FIRST    19
#define SND_WEAPONS_LAST     25
```

### DataPad (Data_Pad.ino) — DataPad-only range

```cpp
#define SND_TOUCH_FIRST      26
#define SND_TOUCH_LAST       27
#define SND_VOICED_FIRST     28
#define SND_VOICED_LAST      31
#define SND_AMBIENT_FIRST    32
#define SND_AMBIENT_LAST     38
#define SND_EASTER_FIRST     39
#define SND_EASTER_LAST      42
```

---

## How to Load the Bridge DY-SV17F

1. Connect the player via USB (appears as USB mass storage) or use UART flash tool
2. Copy all 25 files from `sounds/DY_Player/` to the root of the player flash
3. Files must be named exactly `00001.mp3`–`00025.mp3` — no folders, no other names
4. Eject and power cycle — player is ready

## How to Prepare the DataPad SD Card

1. Copy all 25 files from `sounds/DY_Player/` to the root of the SD card (same names)
2. Rename and copy each DataPad-only file according to the table above (26–42) — source Star Trek clips from trekcore.com/audio/
3. Optionally add files 00043.mp3 and 00044.mp3 for the Star Wars easter egg buttons — source from your own copy; any two audio files will work at those slots
4. Files must be in the root — no folders
5. Insert SD card into the DY1703A module

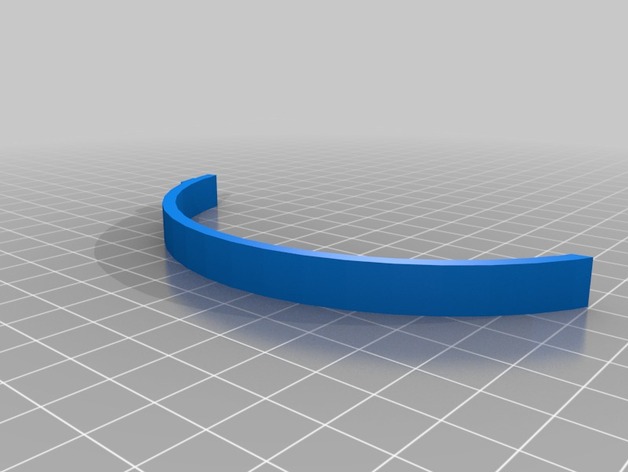
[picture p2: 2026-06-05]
enterprise documentation/Warp_Core/images/bf9760fb8efc488b7846441db6a65bcb_preview_featured.jpg

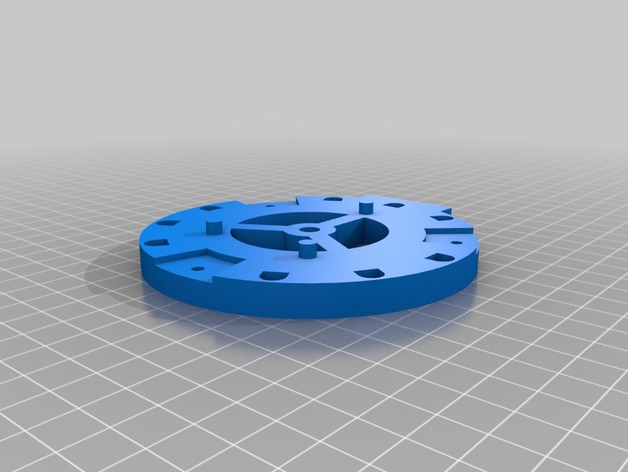
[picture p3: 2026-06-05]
enterprise documentation/Warp_Core/images/197d14a9973d91c49881e64cc06550b7_preview_featured.jpg

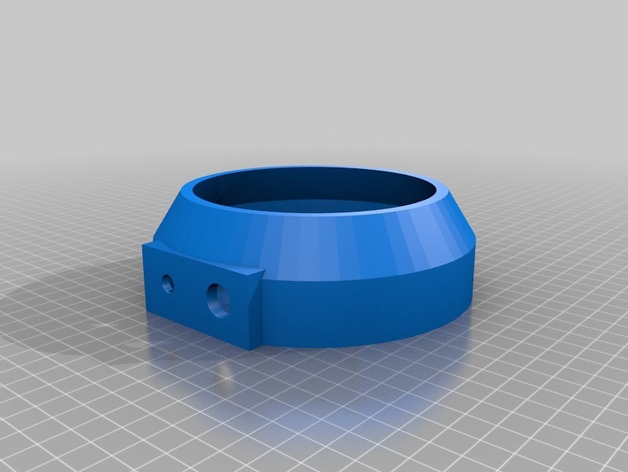
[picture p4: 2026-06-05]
enterprise documentation/Warp_Core/images/9cea04320cbff1a7e1a783edec57f82e_preview_featured.jpg

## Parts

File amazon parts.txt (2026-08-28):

Data Pad Battery
https://www.amazon.com/dp/B0DTHGXTNT

Speakers (DataPad and saucer)
https://www.amazon.com/dp/B0B4D1BN4F

10440 LiPo battery
No longer on Amazon — any 10440 LiPo cell will work

Red 2x3x4 square LED
https://www.amazon.com/dp/B0FWRK92NB
Note: good spares to have on hand — LED leads on the model can break during assembly

White 2x3x4 square LED
https://www.amazon.com/dp/B01C5HL0PO
Note: good spares to have on hand — LED leads on the model can break during assembly

3mm LED kit
https://www.amazon.com/dp/B073XL9DGP

7" touchscreen (DataPad)
https://www.amazon.com/dp/B0D6XSY476

DataPad power switch
https://www.amazon.com/dp/B0DN69L9SG

mmWave presence sensor (LD2410C)
https://www.amazon.com/dp/B0FKBF3CT4

2-pin 1.25mm JST connector
https://www.amazon.com/dp/B013JRWCBU
Note: good spares to have on hand — JST connectors on the model can break during assembly

4-pin 1.25mm JST connector
https://www.amazon.com/dp/B0DFCHWTXK
Note: good spares to have on hand — JST connectors on the model can break during assembly

USB 1S LiPo charger
https://www.amazon.com/dp/B0F9P2WDVH

Sound board - DY-SV17F (saucer)
https://www.amazon.com/dp/B0BPSPPW52
Note: board-mounted form factor, 4MB onboard flash for sound files

Sound board - DY-SV17F (DataPad)
https://www.amazon.com/dp/B07YFPBGF8
Note: same DY-SV17F controller, different form factor — uses SD card for sound file storage

AAA battery placeholder
https://www.amazon.com/dp/B0828GKYKC

8-pin ribbon cable
https://www.amazon.com/dp/B0FK5DGV29

1mm FFC ribbon cable kit (8-pin and 15-pin, saucer board connections)
https://www.amazon.com/dp/B0CTHDDJDF

Boost converter (DataPad sound board)
https://www.amazon.com/dp/B0B4TB9QNY

Xiao ESP32-C3 (EngRoom)
https://www.amazon.com/dp/B0DGX3LSC7

ESP32-S3
https://www.amazon.com/dp/B0CGYXJB6Y

Inline fuse holder (single power source mod), 5x20mm, 10-pack
https://www.amazon.com/DIGITEN-5x20mm-Holder-Inline-screw/dp/B00VLBAF84
Note: only one needed for the mod — good spares to have on hand. Pick a slow-blow fuse rated above the model's combined nominal draw, see HARDWARE.md power budget

Barrel jack (single power source mod)
Link not chosen yet — size/polarity is the builder's choice based on their external supply

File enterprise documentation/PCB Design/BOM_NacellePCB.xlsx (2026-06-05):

No. | Quantity | Comment | Designator | Footprint | Value | Manufacturer Part | Manufacturer | Supplier Part | Supplier
1 | 1 | KH-CL1.0-H2.5-8PIN | CN19 | FPC-SMD_KH-CL1.0-H2.5-8PIN |  | KH-CL1.0-H2.5-8PIN | kinghelm(金航标) | C2797239 | LCSC
2 | 6 | YLED1206B | LED1,LED5,LED6,LED7,LED8,LED9 | LED1206-FD_BULE |  | YLED1206B | YONGYUTAI(永裕泰) | C28310438 | LCSC
3 | 4 | 204-10SUGC/S400-A5-L | LED2,LED3,LED4,LED10 | LED-TH_BD3.0-P2.54-FD |  | 204-10SUGC/S400-A5-L | EVERLIGHT(亿光) | C99763 | LCSC
4 | 2 | MMBT2222A 1P | Q2,Q3 | SOT-23-3_L2.9-W1.3-P1.90-LS2.4-BR |  | MMBT2222A 1P | CJ(江苏长电/长晶) | C8512 | LCSC
5 | 8 | 1.2kΩ | R1,R3,R5,R7,R8,R9,R10,R12 | R0603 | 1.2kΩ | 0603WAF1201T5E | UNI-ROYAL(厚声) | C22765 | LCSC

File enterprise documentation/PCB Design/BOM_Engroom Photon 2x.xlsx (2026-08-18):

No. | Quantity | Comment | Designator | Footprint | Value | Manufacturer Part | Manufacturer | Supplier Part | Supplier
1 | 1 | 10uF | C4 | C0603 | 10uF | CL10A106KP8NNNC | SAMSUNG(三星) | C19702 | LCSC
2 | 1 | 100nF | C5 | C0603 | 100nF | CC0603KRX7R9BB104 | YAGEO(国巨) | C14663 | LCSC
3 | 13 | HC-1.25-4PLT | CN1,CN2,CN3,CN4,CN5,CN6,CN7,CN8,CN9,CN10,CN11,CN12,CN13 | CONN-SMD_4P-P1.25_HCTL_HC-1.25-4PLT |  | HC-1.25-4PLT | HCTL(华灿天禄) | C2845390 | LCSC
4 | 4 | KH-CL1.0-H2.5-8PIN | CN14,CN15,CN16,CN17 | FPC-SMD_KH-CL1.0-H2.5-8PIN |  | KH-CL1.0-H2.5-8PIN | kinghelm(金航标) | C2797239 | LCSC
5 | 6 | MMBT2222A 1P | Q2,Q3,Q4,Q5,Q6,Q7 | SOT-23-3_L2.9-W1.3-P1.90-LS2.4-BR |  | MMBT2222A 1P | CJ(江苏长电/长晶) | C8512 | LCSC
6 | 20 | 1.2kΩ | R1,R3,R5,R8,R11,R14,R17,R19,R20,R21,R22,R23,R24,R25,R26,R27,R28,R29,R30,R31 | R0603 | 1.2kΩ | 0603WAF1201T5E | UNI-ROYAL(厚声) | C22765 | LCSC
7 | 1 | 100k | R33 | R0603 | 100k | GR0603F243RT5G00 | GiantOhm(鼎声微电) |  | LCSC
8 | 1 | 270k | R34 | R0603 | 270k | GR0603F243RT5G00 | GiantOhm(鼎声微电) |  | LCSC
9 | 1 | 330Ω | R35 | R0603 | 330Ω | FRC0603F3300TS | FOJAN(富捷) | C2933198 | LCSC
10 | 3 | ZX-MX1.25-2PLT | U1,U10,U11 | CONN-SMD_2P-P1.25-MX1.25-2P-LT |  | ZX-MX1.25-2PLT | Megastar(兆星) | C7430473 | LCSC
11 | 1 | LM1117MP-3.3/TR | U8 | SOT-223-3_L6.5-W3.4-P2.30-LS7.0-BR |  | LM1117MP-3.3/TR | HGSEMI(华冠) | C498153 | LCSC
12 | 1 | XIAO_ESP32C3 | U9 | CONN-SMD_113991054

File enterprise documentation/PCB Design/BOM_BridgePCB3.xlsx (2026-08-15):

No. | Quantity | Comment | Designator | Footprint | Value | Manufacturer Part | Manufacturer | Supplier Part | Supplier
1 | 23 | HC-1.25-4PLT | 33C,36H,78G,78G*,84H,84H-,84I,88G,88H,92H*,92I,96G,96G*,99C,99C*,101I,101I-,105I*3/13PIN2,105I*13/14PIN1,105IPIN3,107H,107I,Skper | CONN-SMD_4P-P1.25_HCTL_HC-1.25-4PLT |  | HC-1.25-4PLT | HCTL(华灿天禄) | C2845390 | LCSC
2 | 10 | ZX-MX1.25-2PLT | 53H,54D,54D-,76D,76D-,81E,99D,101H,In/Out2,In/Out3 | CONN-SMD_2P-P1.25-MX1.25-2P-LT |  | ZX-MX1.25-2PLT | Megastar(兆星) | C7430473 | LCSC
3 | 1 | 100nF | C12 | C0603 | 100nF | CC0603KRX7R9BB104 | YAGEO(国巨) | C14663 | LCSC
4 | 1 | 10uF | C13 | C0603 | 10uF | CL10A106KP8NNNC | SAMSUNG(三星) | C19702 | LCSC
5 | 1 | KH-FG1.0-H2.0-15PIN | FPC7 | FPC-SMD_15P-P1.0_KINGHELM_KH-FG1.0-H2.0-15PIN |  | KH-FG1.0-H2.0-15PIN | kinghelm(金航标) | C2925383 | LCSC
6 | 13 | MMBT2222A 1P | Q19,Q20,Q21,Q22,Q23,Q24,Q25,Q26,Q27,Q28,Q29,Q30,Q31 | SOT-23-3_L2.9-W1.3-P1.90-LS2.4-BR |  | MMBT2222A 1P | CJ(江苏长电/长晶) | C8512 | LCSC
7 | 47 | 1.2kΩ | R99,R101,R102,R104,R106,R107,R108,R109,R111,R112,R114,R115,R116,R117,R118,R120,R121,R122,R123,R125,R126,R127,R128,R129,R131,R132,R133,R135,R136,R137,R138,R140,R141,R142,R144,R145,R146,R147,R149,R150,R151,R152,R154,R155,R156,R157,R212 | R0603 | 1.2kΩ | 0603WAF1201T5E | UNI-ROYAL(厚声) | C22765 | LCSC
8 | 1 | 0Ω | R213 | R0603 | 0Ω | 0603WAF0000T5E | UNI-ROYAL(厚声) | C21189 | LCSC
9 | 1 | DY-SV17F 4 | U10 | DY-SV17F
10 | 1 | LM1117S-5.0(MS) | U11 | SOT-223-4_L6.5-W3.5-P2.30-LS7.0-BR |  | LM1117S-5.0(MS) | MSKSEMI(美森科) | C20538887 | LCSC

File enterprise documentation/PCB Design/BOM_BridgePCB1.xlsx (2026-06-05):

No. | Quantity | Comment | Designator | Footprint | Value | Manufacturer Part | Manufacturer | Supplier Part | Supplier
1 | 27 | HC-1.25-4PLT | 04J,04J*,04J-,18F,18F-,19E,19E*,19E+,19E-,20E,20E*,21I*,22K,22K-,24E,25E,26E,27F,37C,38C,40I,58E,58E-,58F,60G,65E,65E* | CONN-SMD_4P-P1.25_HCTL_HC-1.25-4PLT |  | HC-1.25-4PLT | HCTL(华灿天禄) | C2845390 | LCSC
2 | 10 | ZX-MX1.25-2PLT | 24F,28F,40H,58G,58H,60H,IN_1,IN_2,OUT_1,SW_1 | CONN-SMD_2P-P1.25-MX1.25-2P-LT |  | ZX-MX1.25-2PLT | Megastar(兆星) | C7430473 | LCSC
3 | 1 | KH-CL1.0-H2.5-8PIN | CN2 | FPC-SMD_KH-CL1.0-H2.5-8PIN |  | KH-CL1.0-H2.5-8PIN | kinghelm(金航标) | C2797239 | LCSC
4 | 7 | MMBT2222A 1P | Q33,Q34,Q35,Q36,Q37,Q38,Q39 | SOT-23-3_L2.9-W1.3-P1.90-LS2.4-BR |  | MMBT2222A 1P | CJ(江苏长电/长晶) | C8512 | LCSC
5 | 41 | 1.2kΩ | R160,R161,R163,R164,R165,R166,R167,R168,R170,R171,R172,R173,R175,R176,R177,R178,R179,R181,R182,R183,R184,R186,R187,R188,R189,R190,R191,R192,R193,R194,R195,R196,R197,R198,R199,R200,R201,R202,R203,R204,R205 | R0603 | 1.2kΩ | 0603WAF1201T5E | UNI-ROYAL(厚声) | C22765 | LCSC

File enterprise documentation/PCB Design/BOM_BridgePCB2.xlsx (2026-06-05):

No. | Quantity | Comment | Designator | Footprint | Value | Manufacturer Part | Manufacturer | Supplier Part | Supplier
1 | 26 | HC-1.25-4PLT | 01T,01U*,01V,29J,30D,32C,34G,35F,39F,41H,42C,43K,44D,45D,46F,47F,48E,49F,50E*,52C,67E,67E*,73G,73G*,73G-,78H | CONN-SMD_4P-P1.25_HCTL_HC-1.25-4PLT |  | HC-1.25-4PLT | HCTL(华灿天禄) | C2845390 | LCSC
2 | 10 | ZX-MX1.25-2PLT | 51E,62C,62C*,62C+,62C-,71F,83D,83D-,In/Out,In/Out1 | CONN-SMD_2P-P1.25-MX1.25-2P-LT |  | ZX-MX1.25-2PLT | Megastar(兆星) | C7430473 | LCSC
3 | 2 | 10uF | C4,C14 | C0603 | 10uF | CL10A106KP8NNNC | SAMSUNG(三星) | C19702 | LCSC
4 | 2 | 100nF | C5,C15 | C0603 | 100nF | CC0603KRX7R9BB104 | YAGEO(国巨) | C14663 | LCSC
5 | 1 | KH-CL1.0-H2.5-8PIN | CN4 | FPC-SMD_KH-CL1.0-H2.5-8PIN |  | KH-CL1.0-H2.5-8PIN | kinghelm(金航标) | C2797239 | LCSC
6 | 2 | B0530W | D1,D2 | SOD-123_L2.7-W1.6-LS3.7-RD |  | B0530W | YTL(亚特联) | C53477314 | LCSC
7 | 1 | KH-FG1.0-H2.0-15PIN | FPC6 | FPC-SMD_15P-P1.0_KINGHELM_KH-FG1.0-H2.0-15PIN |  | KH-FG1.0-H2.0-15PIN | kinghelm(金航标) | C2925383 | LCSC
8 | 14 | MMBT2222A 1P | Q1,Q6,Q7,Q8,Q9,Q10,Q11,Q12,Q13,Q14,Q15,Q16,Q17,Q18 | SOT-23-3_L2.9-W1.3-P1.90-LS2.4-BR |  | MMBT2222A 1P | CJ(江苏长电/长晶) | C8512 | LCSC
9 | 50 | 1.2kΩ | R1,R2,R11,R13,R15,R17,R19,R21,R23,R25,R27,R29,R31,R33,R35,R65,R66,R67,R68,R69,R70,R71,R72,R73,R74,R75,R76,R77,R78,R79,R80,R81,R82,R83,R84,R85,R86,R87,R88,R89,R90,R91,R92,R93,R94,R95,R96,R97,R98,R213 | R0603 | 1.2kΩ | 0603WAF1201T5E | UNI-ROYAL(厚声) | C22765 | LCSC
10 | 2 | 5.1kΩ | R207,R208 | R0603 | 5.1kΩ | AR03BTCX5101 | Viking(光颉) | C318133 | LCSC
11 | 2 | 10kΩ | R211,R216 | R0603 | 10kΩ | 0603WAF1002T5E | UNI-ROYAL(厚声) | C25804 | LCSC
12 | 1 | 100k | R214 | R0603 | 100k | GR0603F243RT5G00 | GiantOhm(鼎声微电) |  | LCSC
13 | 1 | 270k | R215 | R0603 | 270k | GR0603F243RT5G00 | GiantOhm(鼎声微电) |  | LCSC
14 | 2 | TS-1088-AR02016 | SW1,SW2 | SW-SMD_L3.9-W3.0-P4.45 |  | TS-1088-AR02016 | XUNPU(讯普) | C720477 | LCSC
15 | 2 | LM1117MP-3.3/TR | U8,U14 | SOT-223-3_L6.5-W3.4-P2.30-LS7.0-BR |  | LM1117MP-3.3/TR | HGSEMI(华冠) | C498153 | LCSC
16 | 1 | 2.4GHz | U13 | WIRELM-SMD_ESP32-S3-WROOM-1 | 2.4GHz | ESP32-S3-WROOM-1-N8R2 | ESPRESSIF(乐鑫) | C2913204 | LCSC
17 | 1 | TYPE-C 16PIN 2MD(073) | USB1 | USB-C-SMD_TYPE-C-6PIN-2MD-073 |  | TYPE-C 16PIN 2MD(073) | SHOU HAN(首韩) | C2765186 | LCSC

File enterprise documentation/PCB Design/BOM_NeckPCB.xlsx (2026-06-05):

No. | Quantity | Comment | Designator | Footprint | Value | Manufacturer Part | Manufacturer | Supplier Part | Supplier
1 | 2 | KH-CL1.0-H2.5-8PIN | CN19,CN20 | FPC-SMD_KH-CL1.0-H2.5-8PIN |  | KH-CL1.0-H2.5-8PIN | kinghelm(金航标) | C2797239 | LCSC
2 | 11 | HC-1.25-4PLT | CN21,CN22,CN23,CN24,CN25,CN26,CN27,CN28,CN29,CN30,CN31 | CONN-SMD_4P-P1.25_HCTL_HC-1.25-4PLT |  | HC-1.25-4PLT | HCTL(华灿天禄) | C2845390 | LCSC
3 | 6 | MMBT2222A 1P | Q8,Q9,Q10,Q11,Q12,Q13 | SOT-23-3_L2.9-W1.3-P1.90-LS2.4-BR |  | MMBT2222A 1P | CJ(江苏长电/长晶) | C8512 | LCSC
4 | 19 | 1.2kΩ | R32,R34,R36,R38,R40,R42,R43,R44,R45,R46,R47,R48,R49,R50,R51,R52,R53,R54,R55 | R0603 | 1.2kΩ | 0603WAF1201T5E | UNI-ROYAL(厚声) | C22765 | LCSC
5 | 2 | ZX-MX1.25-2PLT | U11,U12 | CONN-SMD_2P-P1.25-MX1.25-2P-LT |  | ZX-MX1.25-2PLT | Megastar(兆星) | C7430473 | LCSC

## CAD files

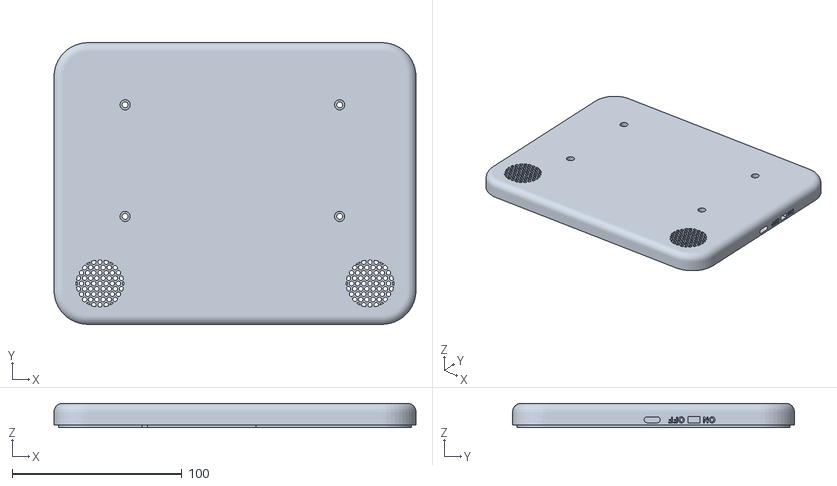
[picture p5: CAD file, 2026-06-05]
enterprise documentation/Data Pad stl/shell data pad bottom.stl
213.0 x 165.8 x 14.4

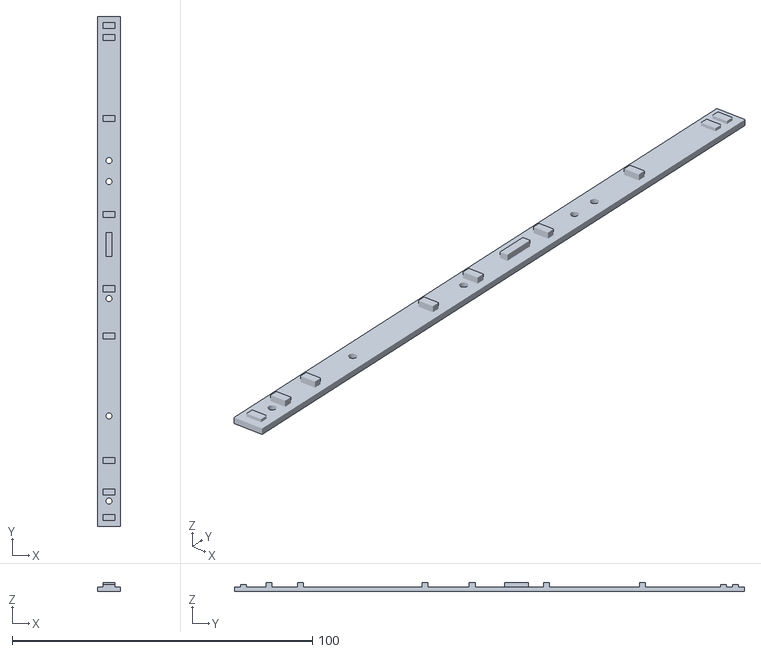
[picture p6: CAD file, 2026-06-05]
enterprise documentation/pcbs test prints/Necell test.stl
7.75 x 170.0 x 3.00

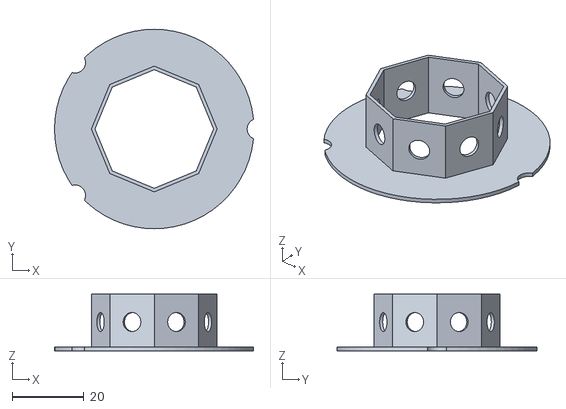
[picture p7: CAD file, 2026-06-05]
enterprise documentation/Warp_Core/files/LightShelf.stl
55.4 x 55.5 x 15.8

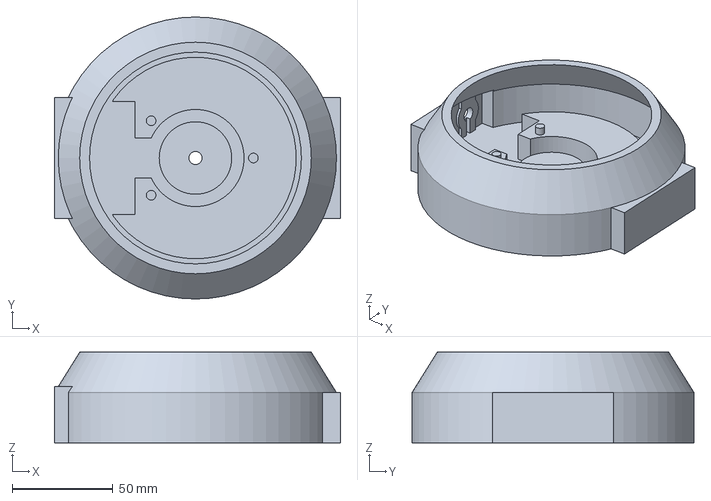
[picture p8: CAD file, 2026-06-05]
enterprise documentation/Warp_Core/WarpCoreBase_mmWaveSensor.3mf
142.0 x 140.0 x 45.0 mm

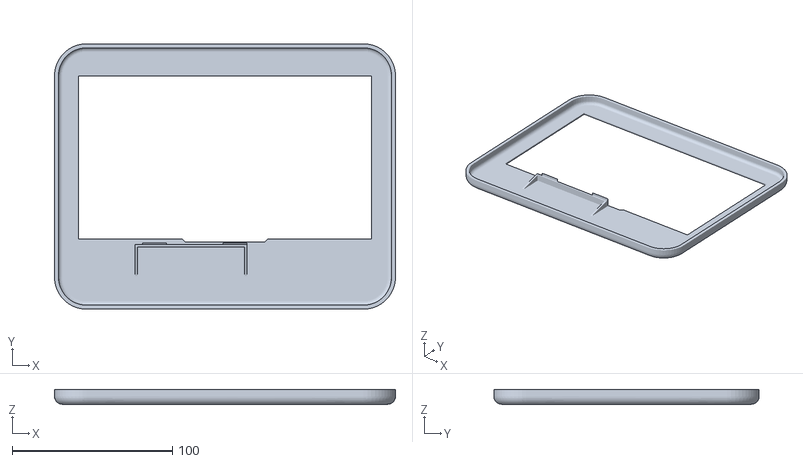
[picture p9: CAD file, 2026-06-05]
enterprise documentation/Data Pad stl/shell data pad top.stl
213.0 x 165.8 x 9.10

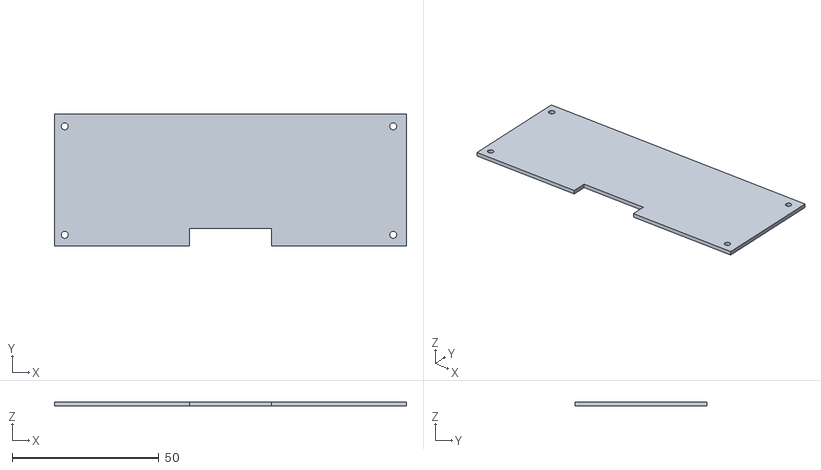
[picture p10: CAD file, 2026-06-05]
enterprise documentation/pcbs test prints/PCB1.stl
120.0 x 45.0 x 1.50

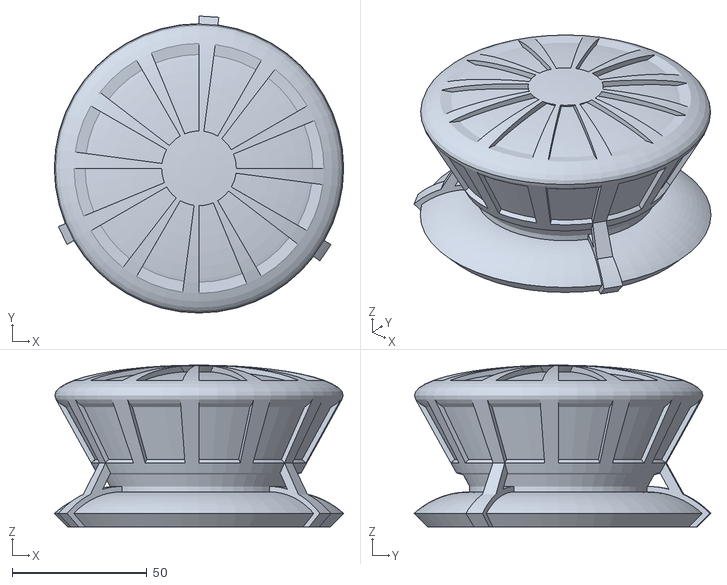
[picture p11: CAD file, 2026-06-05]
enterprise documentation/Warp_Core/files/MatterInjector.stl
107.3 x 110.2 x 60.0

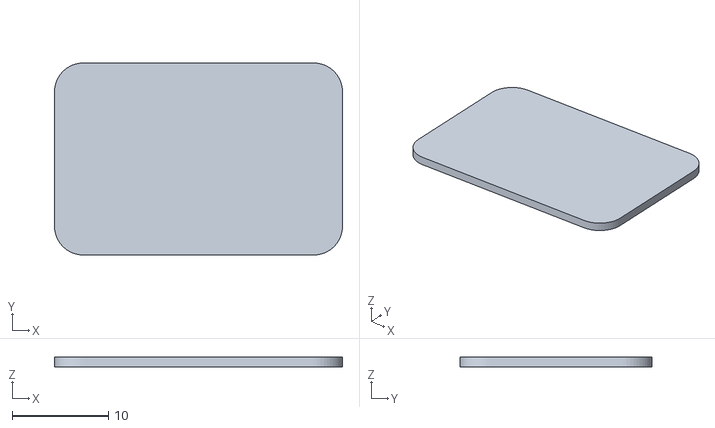
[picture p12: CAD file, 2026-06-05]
enterprise documentation/Data Pad stl/Body23.stl
30.0 x 20.0 x 1.00

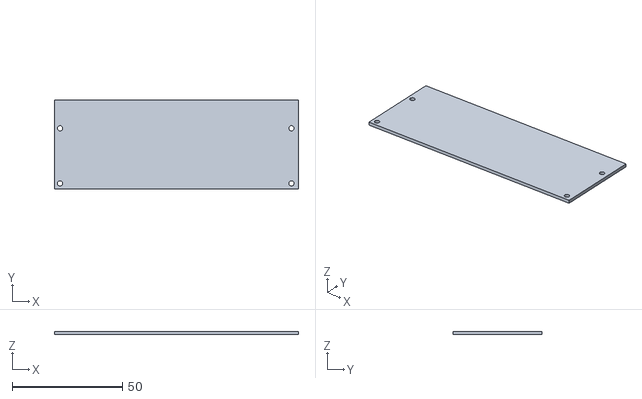
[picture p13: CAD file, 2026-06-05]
enterprise documentation/pcbs test prints/pcb 2&3.stl
110.7 x 40.3 x 1.50

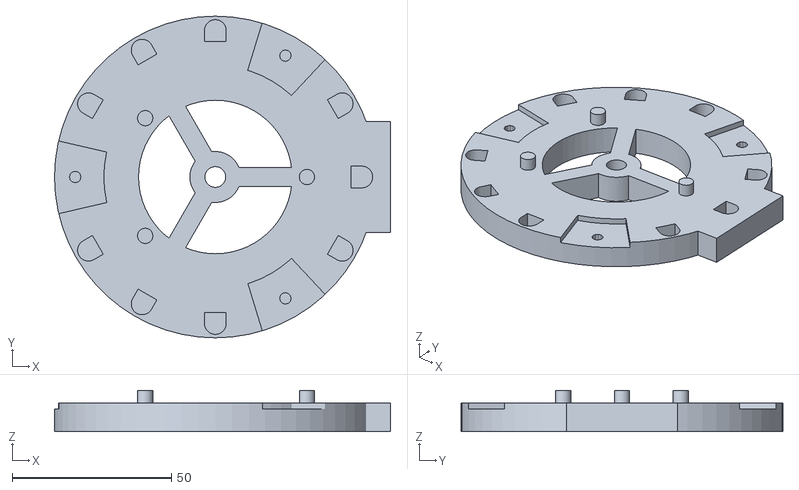
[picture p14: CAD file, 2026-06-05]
enterprise documentation/Warp_Core/files/SupportRingToRingLower.stl
105.5 x 101.0 x 13.0

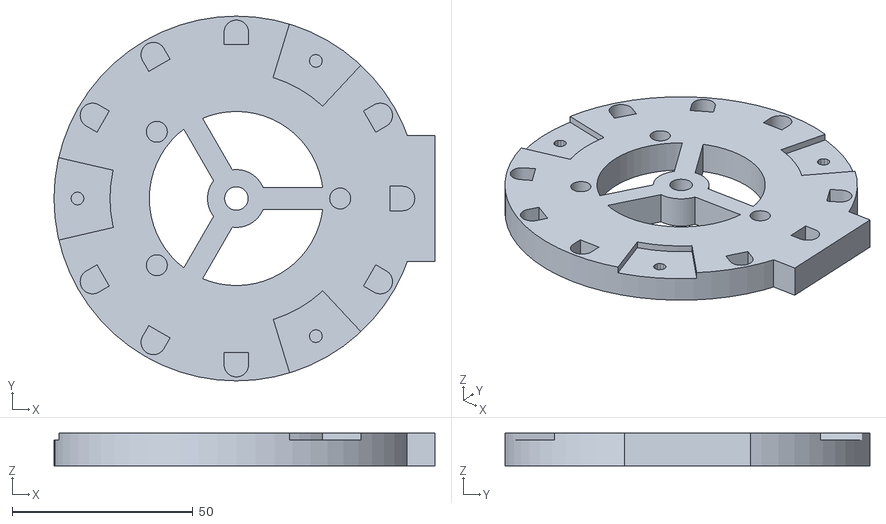
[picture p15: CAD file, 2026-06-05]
enterprise documentation/Warp_Core/files/SupportRingToRingUpper.stl
105.5 x 101.0 x 9.00

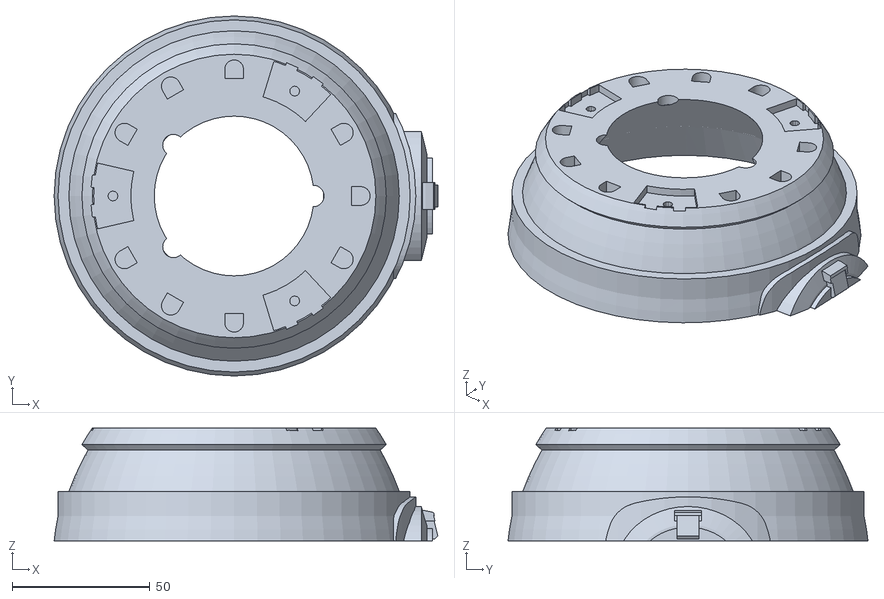
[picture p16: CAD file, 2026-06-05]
enterprise documentation/Warp_Core/files/ChamberEnd.stl
139.4 x 130.7 x 41.0

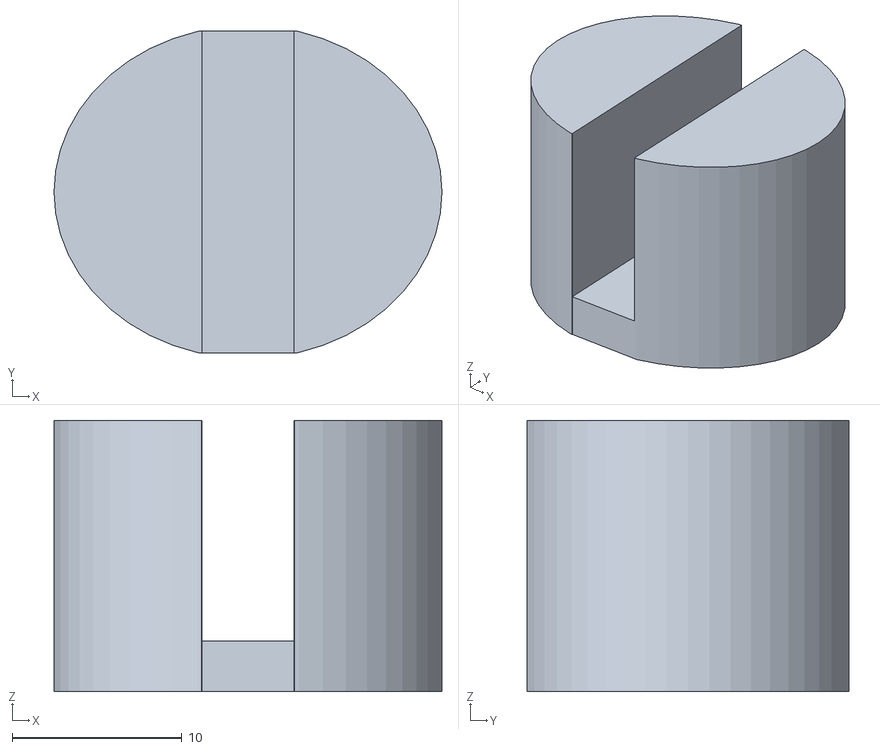
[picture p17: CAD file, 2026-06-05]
enterprise documentation/Warp_Core/files/Warp_Core_Dilithium_Plug.stl
22.9 x 19.0 x 16.0

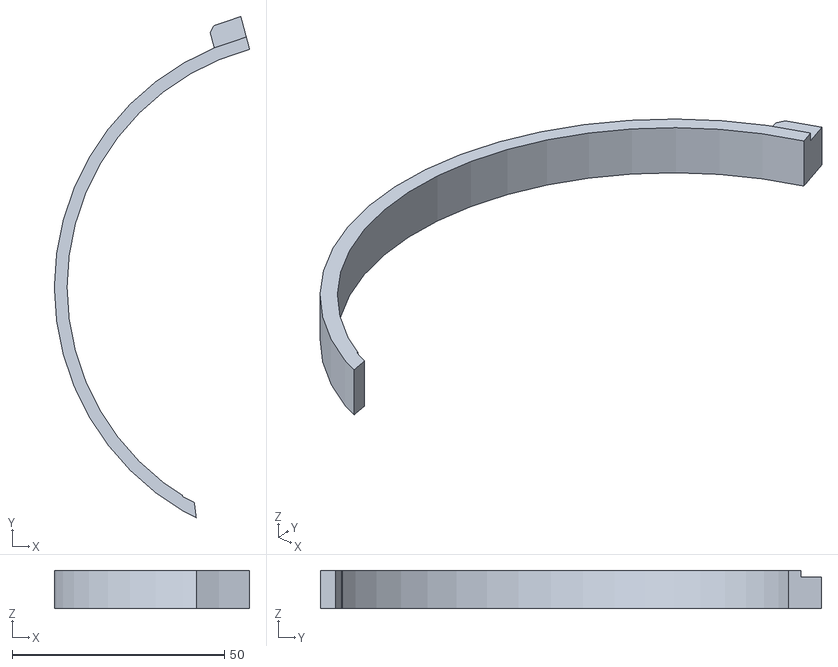
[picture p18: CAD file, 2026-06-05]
enterprise documentation/Warp_Core/files/Warp_Core_MARC_Lights_Extended.stl
46.0 x 118.0 x 9.00

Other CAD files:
enterprise documentation/Warp_Core/files/SupportRingToMI.stl
enterprise documentation/Warp_Core/files/LightRing.stl
enterprise documentation/Warp_Core/files/SupportRingBase.stl
enterprise documentation/Warp_Core/files/WarpCoreBase.stl
enterprise documentation/Warp_Core/files/ChamberMiddle.stl
enterprise documentation/Warp_Core/files/LightRingSupportUnit.stl
enterprise documentation/Warp_Core/files/MatterInjector_repaired.stl
enterprise documentation/Warp_Core/files/Upright.stl
enterprise documentation/Warp_Core/files/knob.stl

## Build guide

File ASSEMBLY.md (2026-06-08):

# Assembly Notes — FFC Routing & Component Mounting

A handful of build photos showing how cabling and key components were fitted inside the model. Not a step-by-step manual — more a visual reference for the trickiest parts if you're doing a similar retrofit: routing flat flex cables (FFC) through the kit's structural frame, and fitting the speaker and DataPad electronics into limited space.

See `HARDWARE.md` for connector pinouts and the full hardware reference.

---

## FFC routing through the frame

Flat flex cables were chosen specifically because they slip through gaps that already exist in the kit's structural frame — no cutting, drilling, or filing required. Regular wire bundles are too thick to route the same way. The connection points between sections cap the cable width at 8-pin, which is what shaped the two-cable split (control signals / power) through the stardrive.

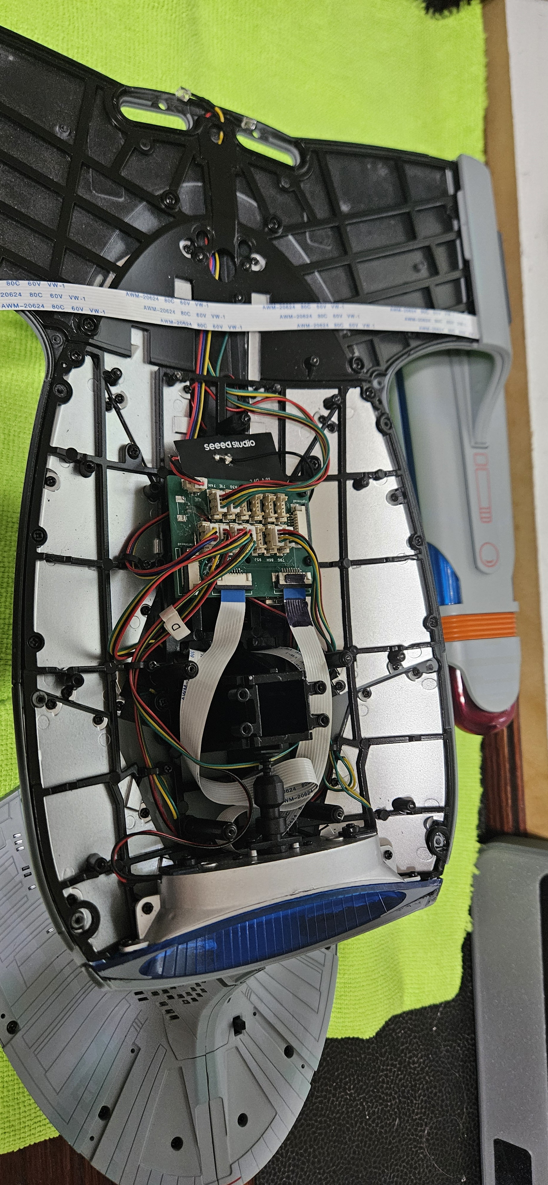
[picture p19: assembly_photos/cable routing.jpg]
Cable routing through the stardrive frame


Stardrive (EngRoom) section, showing both the nacelle and neck FFC runs coming through the structural framing to the EngRoom board — the cables follow existing channels in the frame rather than running over or through it.

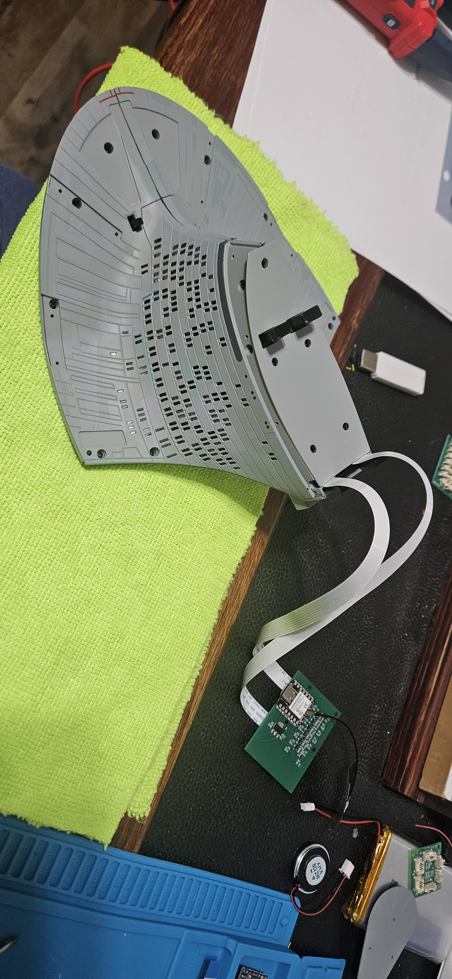
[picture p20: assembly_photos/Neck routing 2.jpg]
Neck section FFC routing


Neck-to-EngRoom connection — the FFC routed between the two sections, wrapped in electrical tape to help prevent shorting against the frame.

The neck bottom plate is normally held on by 5 screws. The last 2 (closest to the cable run) were left out here to avoid putting pressure on the FFC at that point — they can be fitted if you're careful about clearance, but aren't required for this to go together properly.

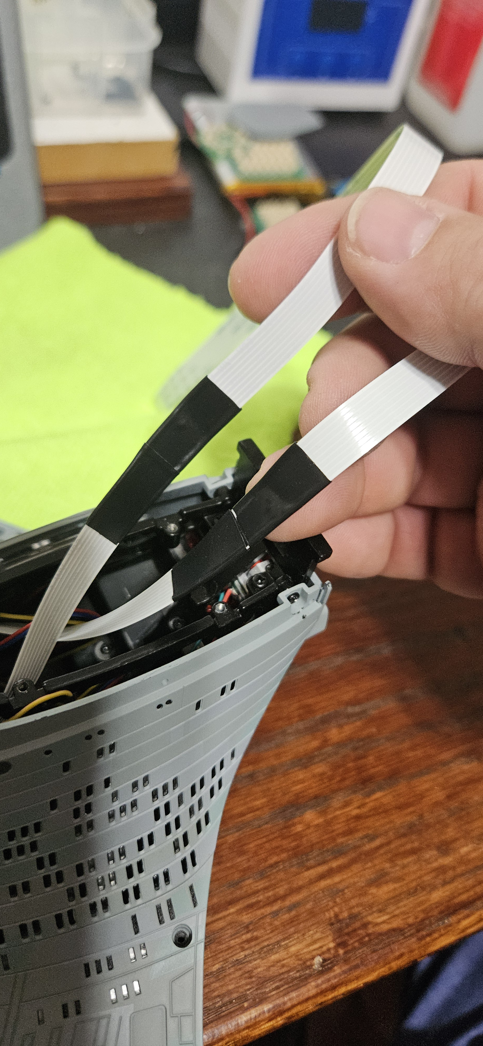
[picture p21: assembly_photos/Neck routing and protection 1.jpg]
Close-up of the taped FFC at the neck connection


Closer look at the same run and tape wrap.

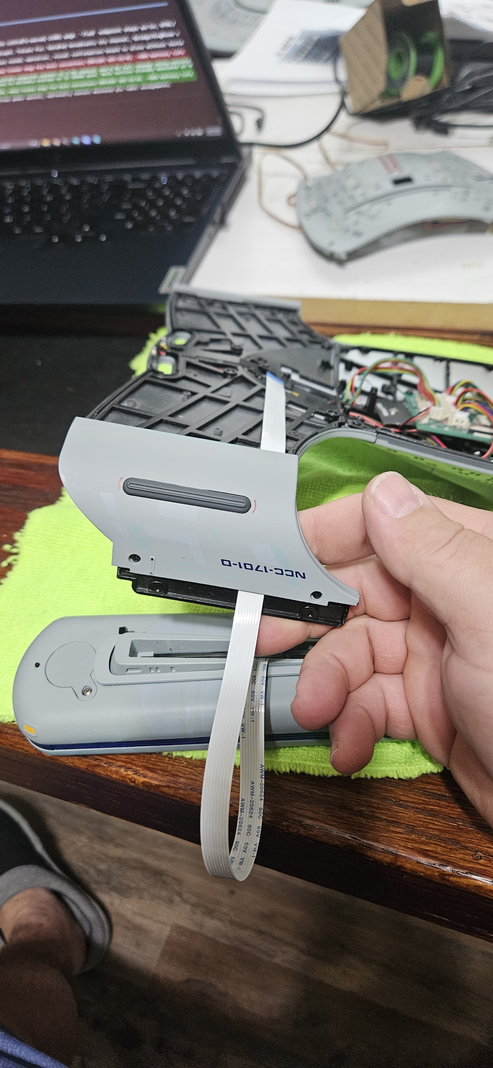
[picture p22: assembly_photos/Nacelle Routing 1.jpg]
Nacelle FFC routing 1


FFC entering the nacelle assembly from the pylon — routed along the inside of the structure to the nacelle's LED groups.

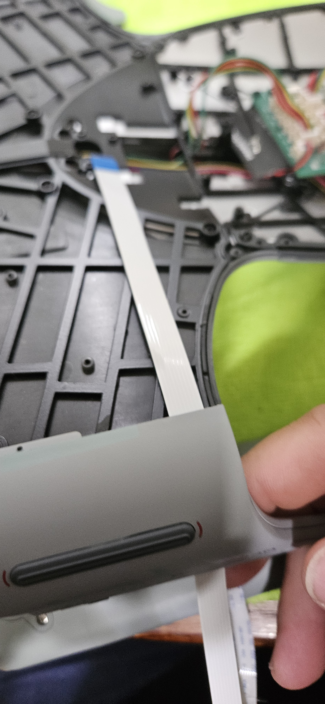
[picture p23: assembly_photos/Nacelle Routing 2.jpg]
Nacelle FFC routing 2


Close-up of the same run, showing the cable bridging from the pylon frame into the nacelle body.

---

## Speaker mounting

There are two speakers for the DY-SV17F sound player, secured to the lower framing with zip ties — one on the left, one on the right. With careful placement they clear everything else in the saucer (wiring, PCB stack, LED ring) and fit nicely.

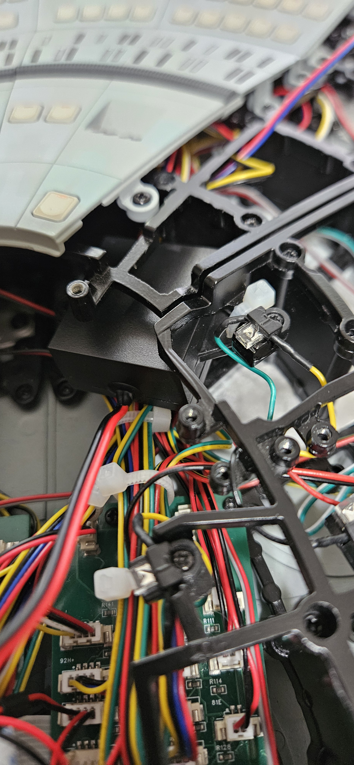
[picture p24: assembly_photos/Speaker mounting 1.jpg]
Speaker mounting 1


Speaker zip-tied to the lower framing, positioned clear of the surrounding window-group wiring and PCB.

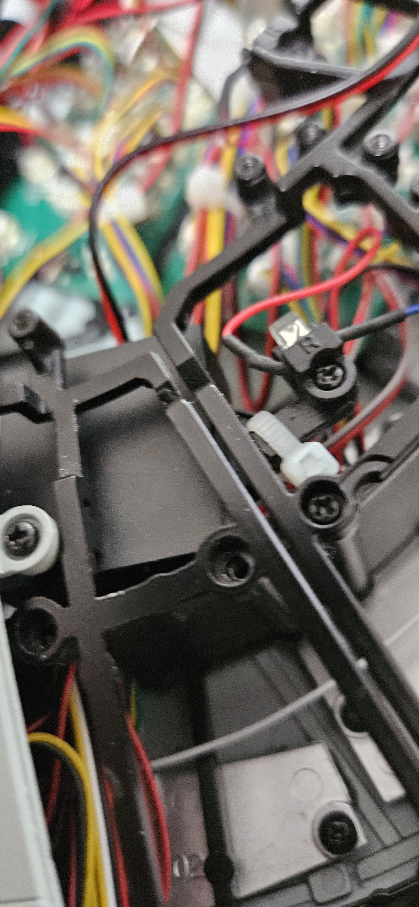
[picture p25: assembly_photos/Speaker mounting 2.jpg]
Speaker mounting 2


Closer view of the zip-tie mount and connector.

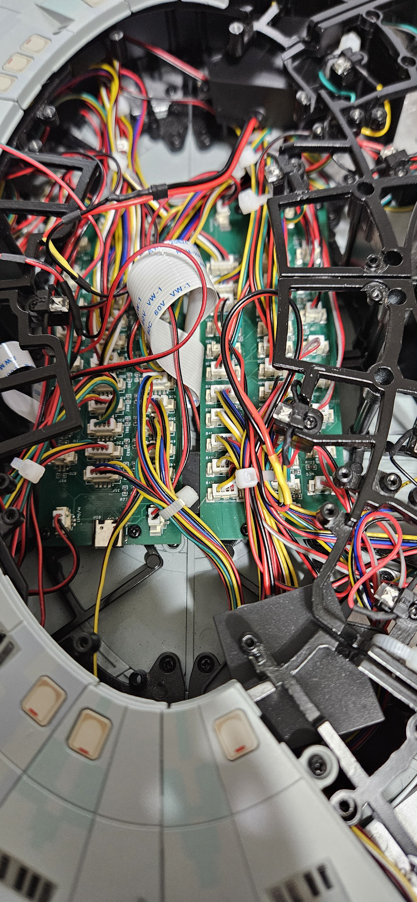
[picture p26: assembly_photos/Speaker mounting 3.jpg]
Speaker mounting 3


Wider view showing the speaker's position relative to the LED ring PCB — also visible here is the FFC routing: the connections sit underneath the boards, and the cable slips easily between the hull panels and the framing as needed.

---

## DataPad internal wiring

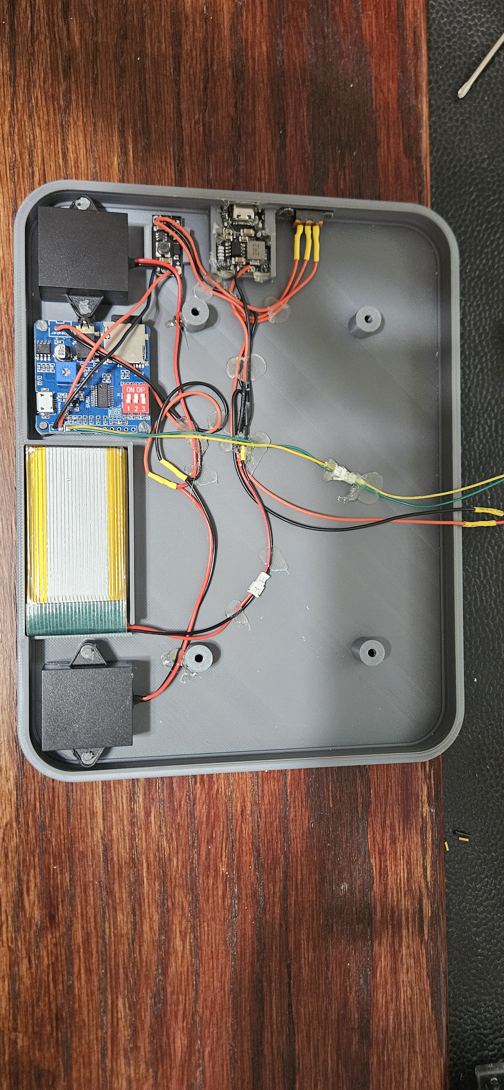
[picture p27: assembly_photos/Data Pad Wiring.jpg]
DataPad internal wiring


Inside the 3D-printed DataPad case: speaker, charger board, ESP32, and LiPo battery. See the DataPad section of the root `README.md` and `HARDWARE.md` for the full hardware rundown — battery, charging, and power switch wiring.

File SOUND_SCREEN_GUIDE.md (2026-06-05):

# Sound Screen — SquareLine Studio Integration Guide

## What Was Generated
The following files are ready to use in the project:
- `Data_Pad/Data_Pad/ui_BridgeSound.c` — full sound screen implementation
- `Data_Pad/Data_Pad/ui_BridgeSound.h` — declarations
- `Data_Pad/Data_Pad/ui.h` — already updated to include BridgeSound
- `Data_Pad/Data_Pad/ui.c` — already updated to init/destroy BridgeSound

---

## What You Need to Do in SquareLine Studio

### Step 1 — Add the Sound Screen
1. In SLS, click **Add Screen**
2. Name it exactly: `BridgeSound`
   - SLS will prefix it with `ui_` → the screen object becomes `ui_BridgeSound`
   - This must match exactly or the init calls in `ui.c` won't link
3. Leave the screen **completely blank** — no objects, no events
   - All content is already built in `ui_BridgeSound.c`

### Step 2 — Add a Navigation Button on Screen1
1. On Screen1, add a button wherever you want the "Sound" nav button
2. Name it whatever you like (e.g. `SndNavBtn`) — it won't conflict
3. Set the button's action:
   - **Event:** Clicked
   - **Action:** Change Screen
   - **Screen:** BridgeSound
   - **Animation:** Fade On
   - **Speed:** 500ms, Delay: 0ms
4. SLS will auto-generate the event handler for this button in `ui_Screen1.c`

### Step 3 — Export from SLS
Export / Create Template Project as normal.

### Step 4 — Handle the Exported Files

**Replace these with the SLS-exported versions (SLS owns these):**
- `ui.h` — will now include `ui_BridgeSound.h`
- `ui.c` — will now call `ui_BridgeSound_screen_init/destroy`
- `ui_Screen1.c` — will have the new nav button event handler

**Keep these files — do NOT replace with SLS output:**
- `ui_BridgeSound.c` ← SLS generates an empty stub; keep the hand-written version
- `ui_BridgeSound.h` ← same — keep the hand-written version

### Step 5 — Re-comment ui_events.c Stubs
As usual after any SLS export, re-comment the stubs in `ui_events.c`:
```c
//void PowerUpAll(lv_event_t * e)    { }
//void NavLightsSet(lv_event_t * e)  { }
//void ImpulsEng(lv_event_t * e)     { }
//void DamageControl(lv_event_t * e) { }
//void StartWiFi(lv_event_t * e)     { }
//void SaveWifi(lv_event_t * e)      { }
```
The sound handlers (SoundPlay1-4, SoundStop, SoundVolume, SoundRepeat) are
forward-declared in `ui_BridgeSound.h` — they do NOT appear in `ui_events.h`
and do NOT need stubs in `ui_events.c`.

---

## Screen Layout Reference (ui_BridgeSound)
Screen size: 800 × 480, coordinates relative to center

| Object | Type | Position (x, y) | Size (w × h) | Color | Notes |
|---|---|---|---|---|---|
| ui_SndBackBtn | Button  | -315, -195 | 100 × 40 | Green | Navigates back to Screen1 |
| ui_SndBackLabel | Label | child of above  | — | — | Text: "< BACK" |
| ui_SndTitle | Label | 45, -195 | content | White | Text: "SOUND CONTROLS"  |
| ui_SndPlay1Btn | Button  | -125, -100 | 230 × 70 | Green | Plays SND_FILE_1 |
| ui_SndPlay1Label | Label | child of above  | — | — | Text: "Sound 1" (update when named) |
| ui_SndPlay2Btn | Button  | 125, -100 | 230 × 70 | Green | Plays SND_FILE_2 |
| ui_SndPlay2Label | Label | child of above  | — | — | Text: "Sound 2" |
| ui_SndPlay3Btn | Button  | -125, -20 | 230 × 70 | Green | Plays SND_FILE_3 |
| ui_SndPlay3Label | Label | child of above  | — | — | Text: "Sound 3" |
| ui_SndPlay4Btn | Button  | 125, -20 | 230 × 70 | Green | Plays SND_FILE_4 |
| ui_SndPlay4Label | Label | child of above  | — | — | Text: "Sound 4" |
| ui_SndStopBtn | Button  | 0, 65 | 380 × 55 | Red | Stops playback |
| ui_SndStopLabel | Label | child of above  | — | — | Text: "STOP" |
| ui_SndVolLabel | Label | -185, 140 | content | White | Text: "Volume" |
| ui_SndVolSlider | Slider  | 60, 140 | 310 × 20 | — | Range 0–30, default 20  |
| ui_SndRepeatBtn | Button  | 0, 193 | 210 × 42 | Blue | Cycles: OFF → LOOP ONE → LOOP ALL |
| ui_SndRepeatLabel  | Label | child of above  | — | — | Text updates on each press |

---

## Naming Note
All object names use the `ui_Snd` prefix so they are clearly grouped and will
never conflict with default SLS auto-numbered names (`ui_Button51` etc.).
Adding more buttons or labels to any other screen in SLS will not collide.

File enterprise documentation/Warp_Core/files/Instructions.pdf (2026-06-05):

# ST:TNG Warp Core

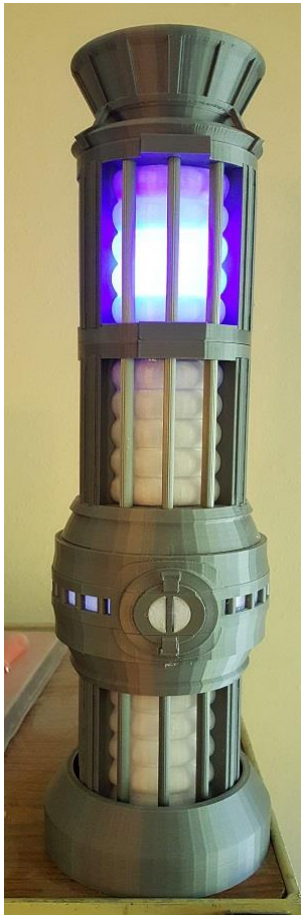
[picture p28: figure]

### Printed Parts:

- WarpCoreBase.stl
- SupportRingBase.stl
- ChamberEnd.stl (x2)
- ChamberMiddle.stl
- SupportRingToRingLower.stl
- SupportRingToRingUpper.stl
- SupportRingToMI.stl
- MatterInjector.stl
- Knob.stl
- LightRing.stl (x15)
- LightShelf.stl (x15)
- Upright.stl (x27)
- LightRingSupportUnit.stl (x9)
- Warp_Core_Dilithium_Plug.stl
- Warp_Core_MARC_Lights_Extended.stl (x2)

### Hardware:

- M3 x 10mm screws
- ¼” Threaded Rod – 18”+
- ¼” Nut (x2)
- ¼” Fender Washer
- Wire (6 and 4 conductor cables will be helpful)
- LED – Blue (x120)
- LED – White (x12)
- Arduino Nano
- 2N7002 (SMC) or 2N7000 Mosfet (x11)
- 10K Resistor – SMC or Through Hole (x11)
- 10K Potentiometer
- 6 Pin Molex Connector (x3 – Digikey WM4204-ND)
- 6 Pin Molex Housing (x3 - Digikey WM2004-ND)
- 4 Pin Molex Connector (Digikey WM4202-ND)
- 4 Pin Molex Housing (Digikey WM2002-ND)
- 2 Pin Molex Connector (Digikey WM4200-ND)
- 2 Pin Molex Housing (Digikey WM2000-ND)
- Crimp Connectors Female (x24– Digikey WM1114-ND)
- Power Connector (Digikey CP-011A-ND)
- WarpCore PDB (OSHPark - https://oshpark.com/shared_projects/OjKfgvHc) or prototype board.

- Optional – Single row headers, male and female, for Nano
- Hot Glue
- 12v Power Supply

### Assembly

These instructions are not a complete step by step guide on assembling the Warp Core. It is a guide on how the parts fit together. While I try to be as clear as possible in describing each step, it is up to the user to determine how best to complete each step. I have included pictures to help demonstrate what things should look like that is described in the text.

I am a Software Engineer, not an English Major or manual writer. I will be the first to admit that my writing is not the best. I have tried to do the best I can to describe how to assemble things. Successful assembly will rely on the users mechanical and electronic skills. This is not a novice level project.

Begin by printing the light shelfs and light rings. If you do them in groups of 5, you can be working on one set while the next set prints.

Each light shelf contains 8 blue LEDs connected as 2 parallel runs of 4 LEDs in series. Insert 4 LEDs, making sure the leads are orientated the same. The longer lead is the anode that connects to supply voltage. I orientated the LEDs as shown below. The anode, when looking at the picture, is the lead on the left. Hot glue the LEDs in place.

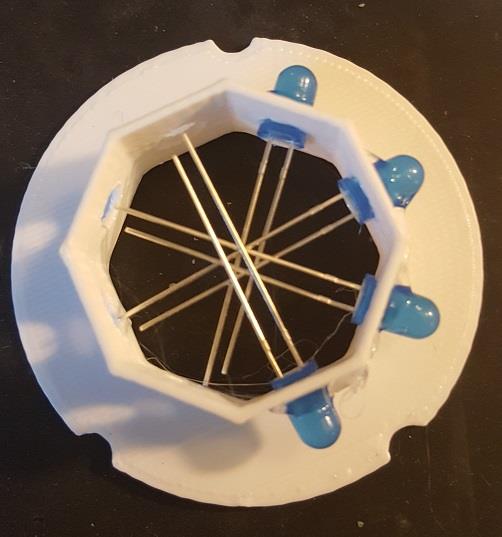
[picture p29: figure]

Repeat this for the other 4 shelves. This will allow time for the glue to dry before moving to the next step.

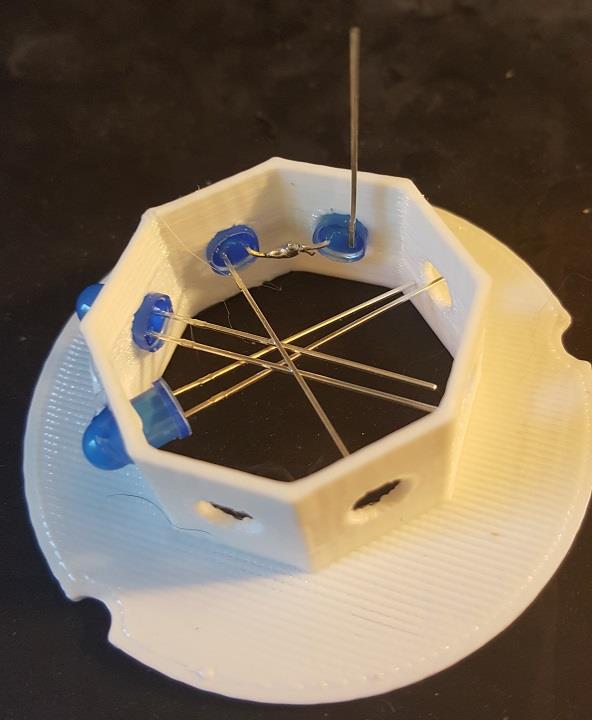
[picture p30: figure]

Bend the anode of the first LED up and out of the way. Connect the cathode (short lead) of the LED to the anode of the next LED. Repeat for the other LEDs. You should end up with something like the

picture below.

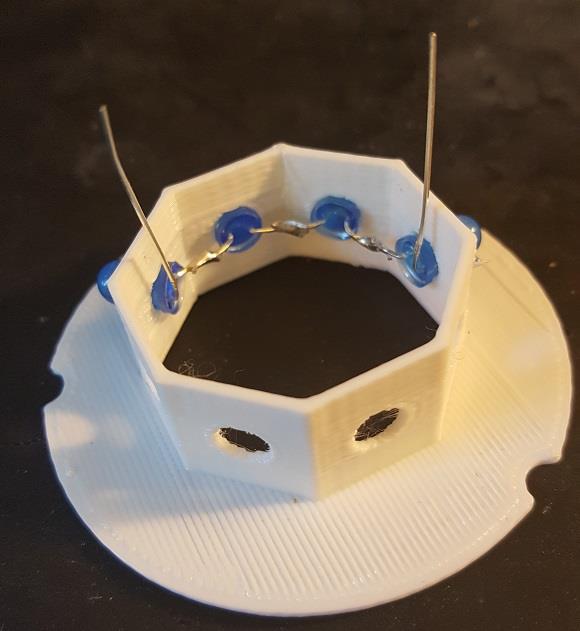
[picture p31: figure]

Using the 12v power supply, or a bench power supply, connect the anode (long lead) to +12vdc and the cathode (short lead) to ground, or negative, or zero, or whatever you want to call it. Make sure all the

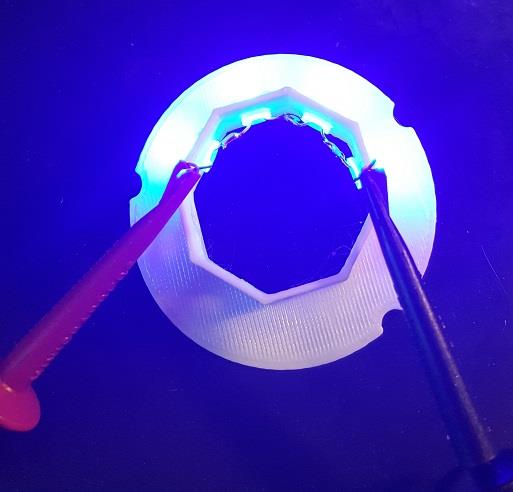
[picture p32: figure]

LEDs light.

Add the other 4 LEDs following the same procedure used for the first four and hot glue the LEDs in place. Set aside so the glue and set and repeat for the other 4 shelves.

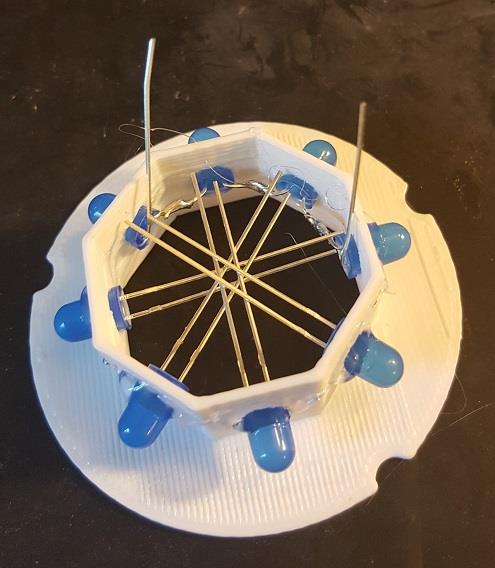
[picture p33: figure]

After you have all 5 shelves finished, the other 4 LEDs can be wired together in the same fashion as the first four. Using the power supply, make sure all the LEDs work.

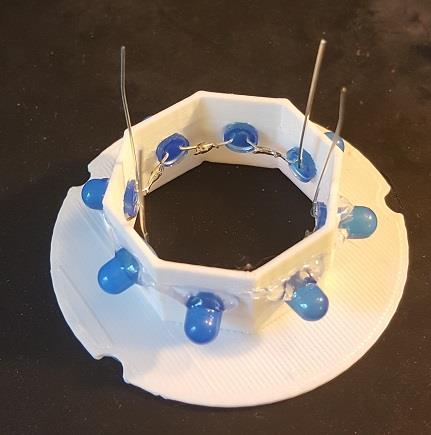
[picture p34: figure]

Connect the cathodes together to a wire as shown below. It is best to use various color wires to be able to identify which wire goes to each shelf. I used the wires in the following order: Black, Blue, White, Brown, Green, and Red. By using the same order on each set of shelves, it will make wiring to the Nano easier.

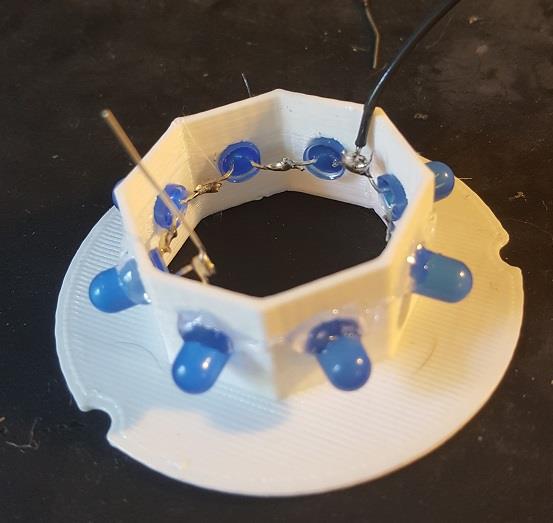
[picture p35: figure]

The anodes are connected together and one of the leads is left long. This will be used to connect to the next shelf.

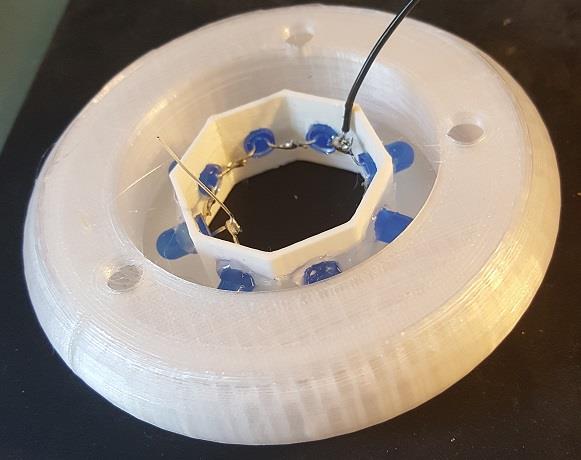
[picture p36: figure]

Place the light shelf into a light ring. Congratulations. You now have one done. Only14 more to go.

Repeat this process for the next four shelves, stacking them on top of each other. I ran the wire from the shelf below under the wire on the one above to keep the wires together. I wrapped the anode lead from the lower shelf around the anode wires of the shelf above as shown below.

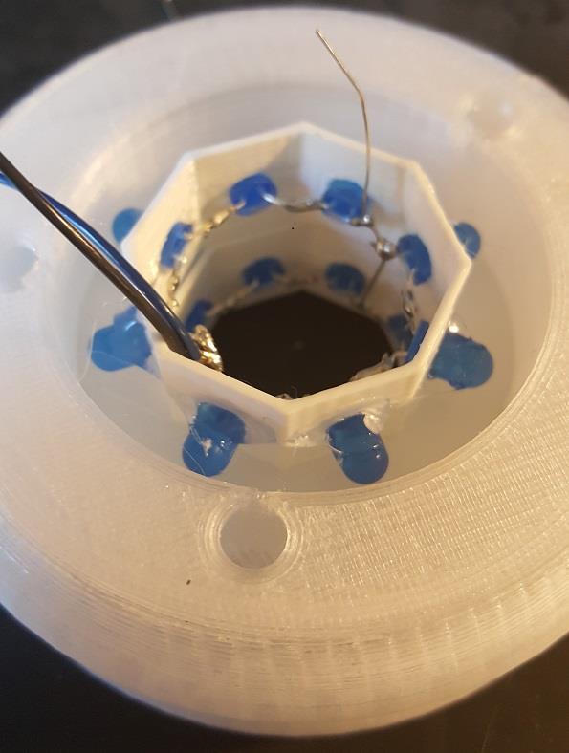
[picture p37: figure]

Once you have all the shelves wired together, you should have a stack of 5 rings. On the top ring, run the red wire around to the anode wires. You should have 6 wires. If you connect the Red wire to +12, you can check each ring by connecting one of the other wires to ground. Complete the other two light stacks

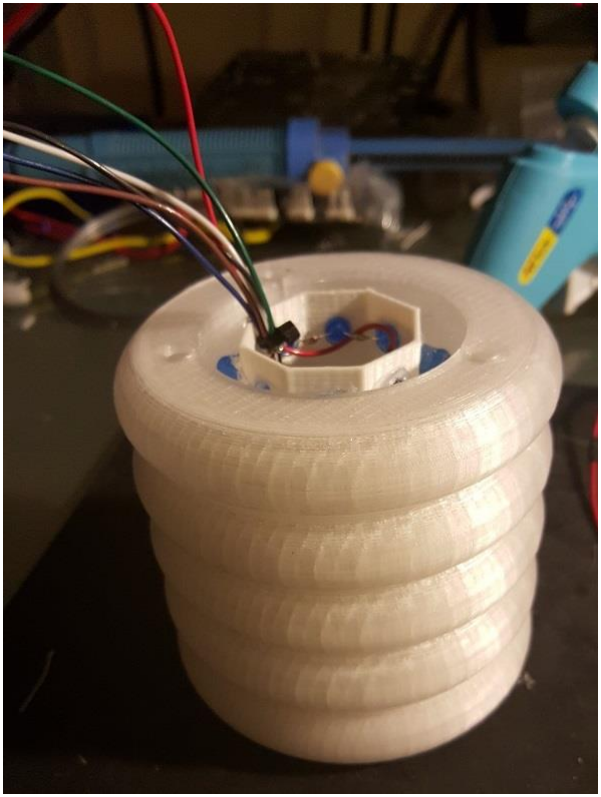
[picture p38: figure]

Once all 3 light stacks are finished, the three light sections can be made. Use the SupportRingBase, 3 LightRingSupportUnits, 9 Uprights, and a ChamberEnd. Place the light stack on the SupportRingBase and fit a LightRingSupportUnit next to it. Use a M3x10mm screw to hold the support unit in place. Repeat with the other 2 support units.

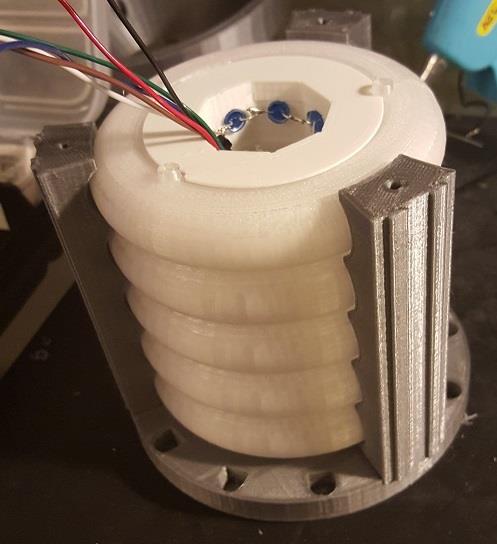
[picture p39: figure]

Insert the 9 uprights into the holes.

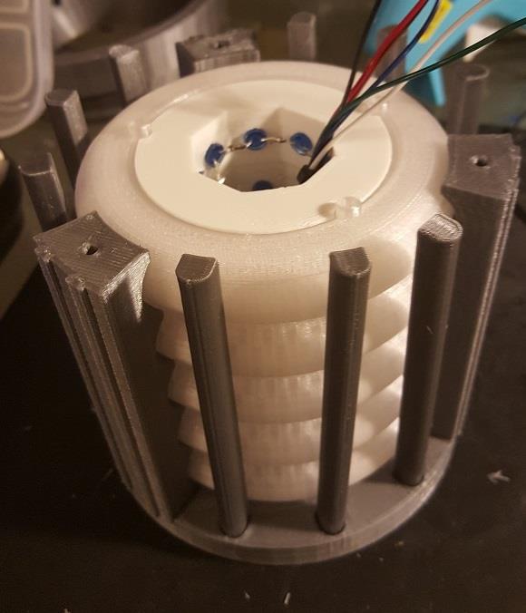
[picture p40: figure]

Place the ChamberEnd on top, aligning the uprights and supports into the corresponding holes. This can be a bit tricky. What I found works best was the get one support in place and the uprights next to it in place and loosely put in one screw to hold everything together. I could then get the other uprights and supports in place and put the other two screws in place and tighten them up. DO NOT OVER TIGHTEN THE SCREWS!

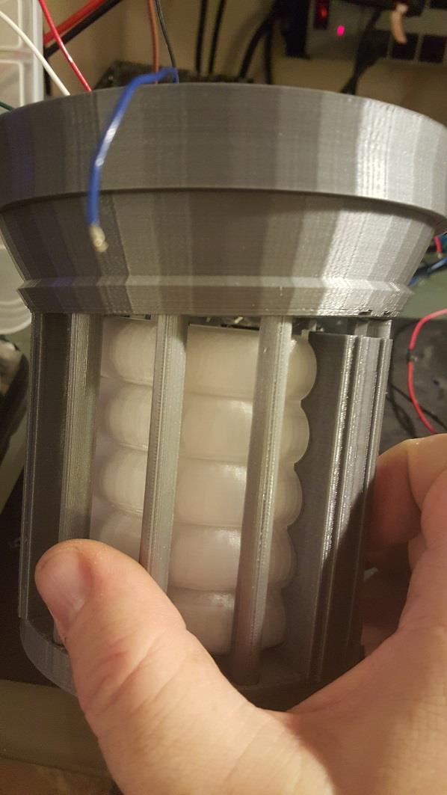
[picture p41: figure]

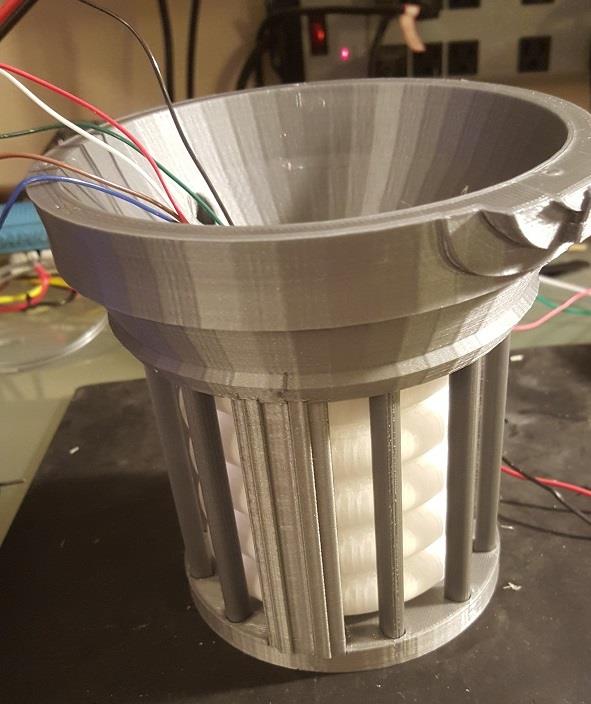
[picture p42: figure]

Assemble the other two sections using the same process using ChamberEnd, SupportRingToRingLower and SupportRingToRingUpper, SupportRingToMI.

Set the three light segments aside and assemble the WarpCoreBase.

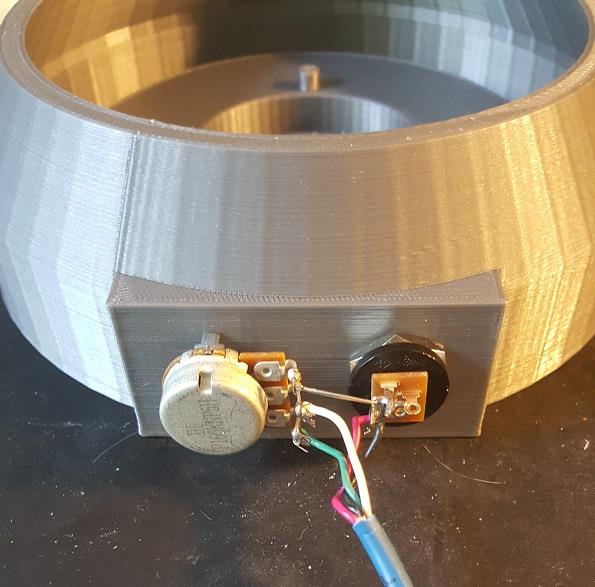
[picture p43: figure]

I found getting the wire lengths right was easy if I used the mounting holes in the base as shown above. The red wire attaches to the center connecter of the power plug. This is +12vdc. The black wire goes to the outer connector, or ground. The top connector on the pot is connected to ground. White to the center and green to the bottom. I then moved the assembly to the inside and bolted everything into place

The four wires are routed up through the light unit made with the SupportRingToBase (there is no tab on this one like there is on the other two). The light unit can then be set into place on the base, aligning the nubs into the matching holes. They only fit one way.

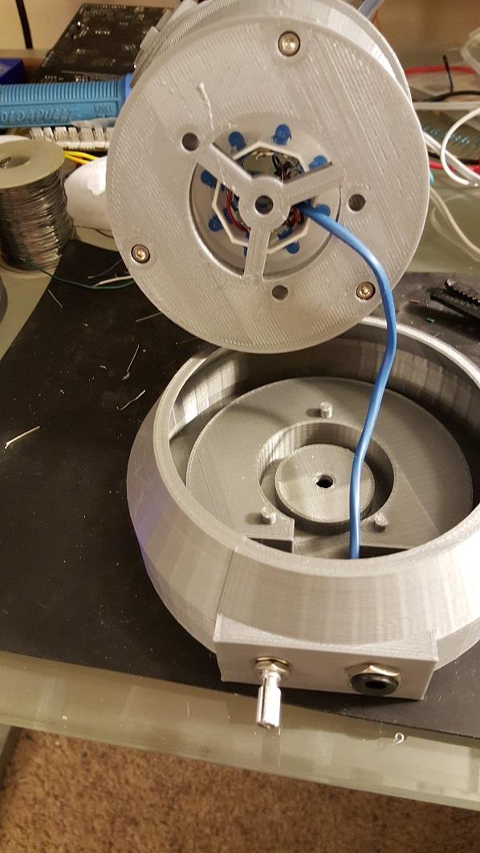
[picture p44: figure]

Using a similar technic as the light shelves, assemble the LEDS in the ChamberMiddle. There are 3 sets of 4 LEDs in series in this section. You will need to run a couple extra wires to connect the anode and cathode of the third set of LEDs to the other two. The lead sticking up at the 9 o’clock position is the anode and the lead at 4 o’clock is the cathode.

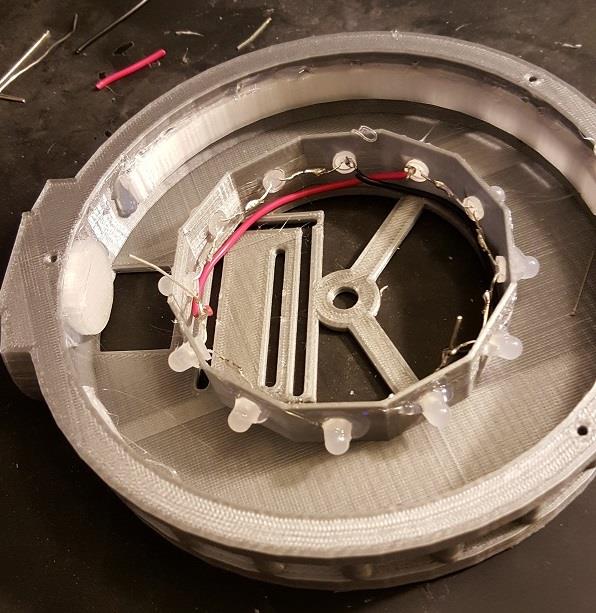
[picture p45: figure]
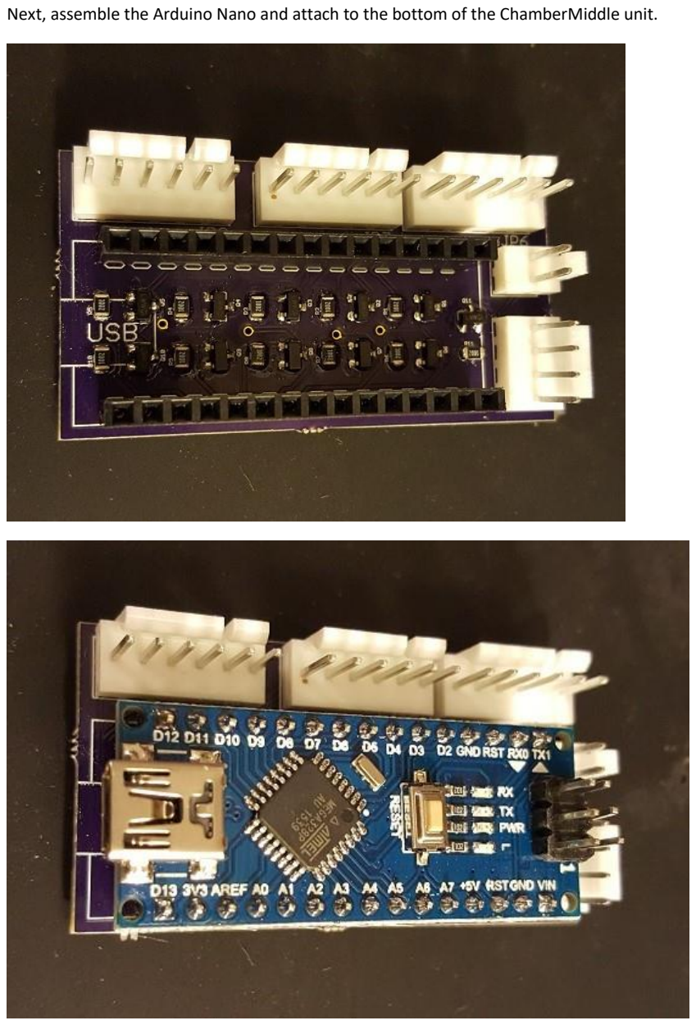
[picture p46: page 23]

Next, assemble the Arduino Nano and attach to the bottom of the ChamberMiddle unit.

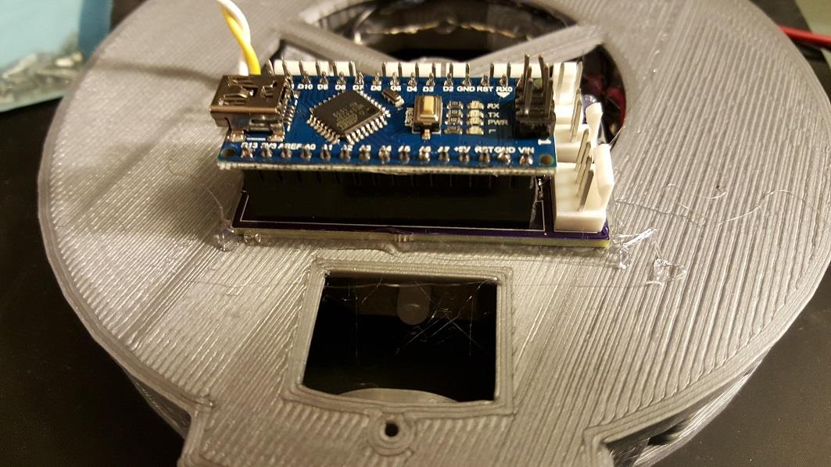
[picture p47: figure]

Wire the four conductor cable from the power/pot as shown below. Black is ground. Green goes to the bottom connection of the pot. White to the middle connector. Red to +12vdc.

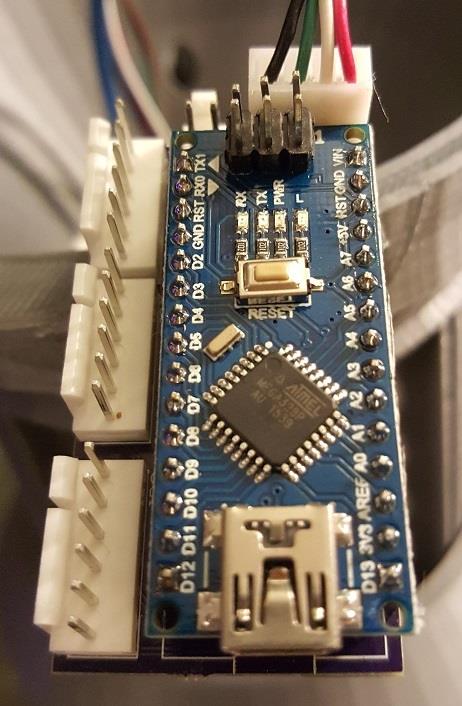
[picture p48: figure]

Wire up the three light sections. Connect a six pin molex header to the six wires from each section. If you used the same wire colors as I did, this is how it will look. Each group is wired the same. The right two connectors go to the two light sections around the chamber. It doesn’t matter which plug is used.

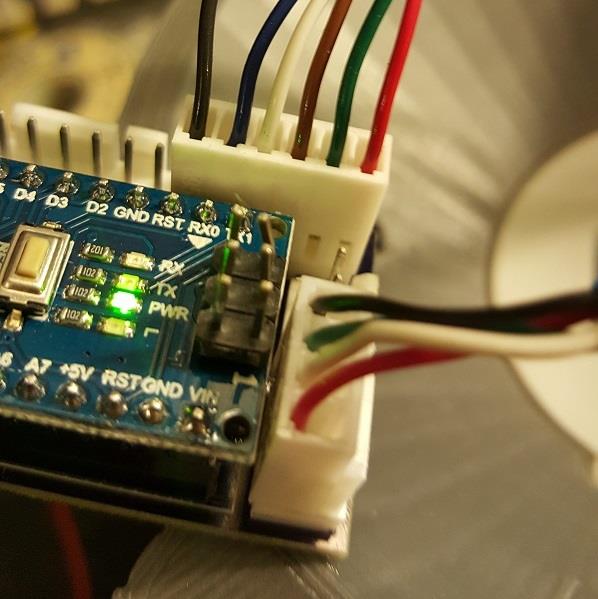
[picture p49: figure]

Wire the two pin connector to the chamber lights. The bottom pin connects to the anode. Top pin to the cathode.

Now would probably be a good time to glue in the Warp Core Dilithium Plug and MARC Lights Extended pieces.

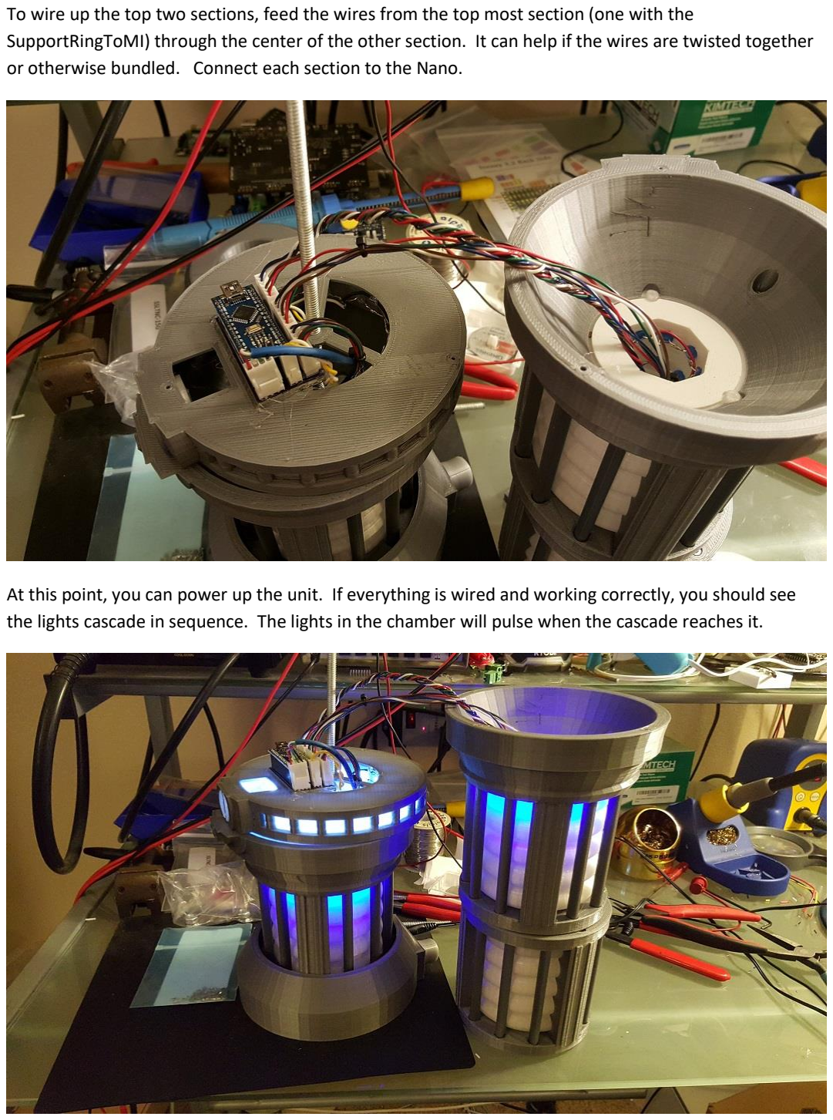
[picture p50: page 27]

To wire up the top two sections, feed the wires from the top most section (one with the SupportRingToMI) through the center of the other section. It can help if the wires are twisted together or otherwise bundled. Connect each section to the Nano.

At this point, you can power up the unit. If everything is wired and working correctly, you should see the lights cascade in sequence. The lights in the chamber will pulse when the cascade reaches it.

Embed one of the ¼” nuts into the Matter Injector. I found it easiest to do by first dropping the nut into the Matter Injector…

Place a ¼” nut and washer on the rod allowing plenty of space for the rod to reach the nut in the Matter Injector.

Place the ¼” threaded rod through the hole and onto the top of the nut. Reach down with your fingers or other long object to hold the nut in place and thread the rod into the nut.

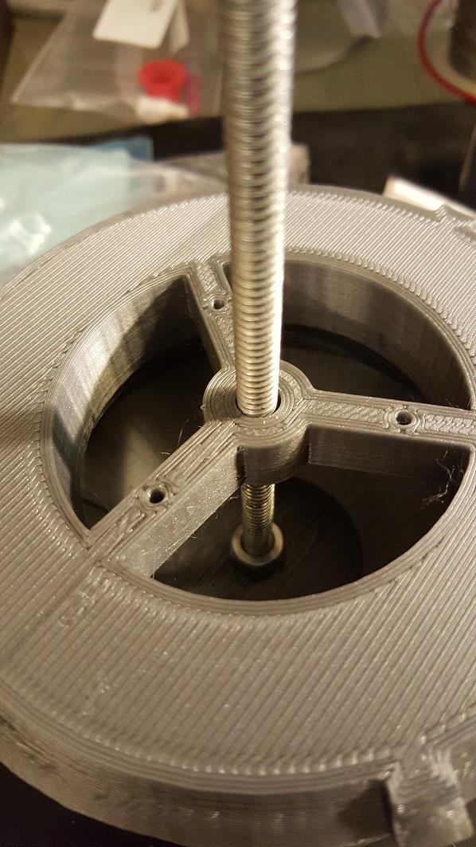
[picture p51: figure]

Pull the rod with the nut up and tighten the second nut and washer.

Keep tightening the outer nut until the inner nut seats itself and then remove the rod.

Move the nut and washer to one of the ends of the rod. Slide the rod up through the Warp Core base, lower light section, and chamber middle.

Continue sliding the rod through the upper two light sections. You will have to pull the rod out to be able to thread the rod through the upper light sections .

The following step is optional, but I find it helpful to keep the sections aligned. Where each of the pieces sit on each other, other than the base to the first light section, there are small holes. They holes are sized such that a piece of 1.75mm filament will fit in them. There are matching holes on the opposite piece for the filament pieces to fit into. Each section will only fit together one way using these alignment holes.

Once all the sections are fitted together, screw the Matter Injector cap onto the top to tighten everything together. Depending on how long the threaded rod is, you may have to cut it so it will fit.

Plug in the Warp Core and enjoy.

If you find that I have left out something, or things are not clear, please message me on Thingiverse. I’ll do my best to help clear up any issues.

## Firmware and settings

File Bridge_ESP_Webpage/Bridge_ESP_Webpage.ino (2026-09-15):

/*
  Bridge ESP — ESP32-S3
  18 LED groups + DY-SV17F sound + ESP-NOW + OTA
  GPIO outputs: see "GPIO outputs Bridge.txt"
*/

#include <esp_now.h>
#include <WiFi.h>
#include <esp_wifi.h>
#include <Preferences.h>
#include <ESPmDNS.h>
#include <NetworkUdp.h>
#include <ArduinoOTA.h>
#include <WebServer.h>
#include "control_html.h"

// ── Network / OTA ─────────────────────────────────────────────────────────────
void RevertWiFi();
void StartWiFi(bool saveCredentials = false);

const char* mdnsName      = "Bridge";
bool        servicesStarted = false;
bool        wifiActive      = false;   // true after StartWiFi() succeeds
uint32_t    wifiDropMs      = 0;       // millis() when WiFi drop first detected
#define WIFI_REVERT_MS 90000UL         // auto-revert after 90s of dropped WiFi
uint8_t     wifiChannel   = 1;   // cached channel — updated from main task, safe to read in callbacks

// ── Web control page (bench AP — Batch_Provisioning copy only) ───────────────
// Kit-facing control page: Bridge hosts its own AP + web server, EngRoom stays
// ESP-NOW-only. See UTILITY_BATCH_PROVISIONING.md / project_prop_controller_kit.
const char* AP_SSID = "Enterprise D";
const char* AP_PASS = "ncc1701-d";
WebServer   bridgeWebServer(80);
bool        macLoadedFromNvs = false;   // set true in setup() if either peer MAC came from NVS

// ── Bench debug status LED — ESP32-S3 dev board onboard NeoPixel ─────────────
// GPIO48 confirmed on the S3 dev board (see Batch_Bootstrap.ino). NOT present
// on the real Bridge PCB — bench debug aid only, never carry onto real hardware.
#define STATUS_LED_PIN         48
#define STATUS_LED_BRIGHTNESS  40
uint32_t statusFlashUntilMs = 0;

// ── MAC addresses ─────────────────────────────────────────────────────────────
uint8_t broadcastAddress1[] = {0x00, 0x00, 0x00, 0x00, 0x00, 0x00}; // EngRoom — run MAC_address_retriver on your board (or use /setmac below)
uint8_t broadcastAddress2[] = {0x00, 0x00, 0x00, 0x00, 0x00, 0x00}; // DataPad — run MAC_address_retriver on your board (or use /setmac below)
String  selfMacStr; // Bridge's own MAC, set in setup(), read by /macs

// ── Sound (DY-SV17F on UART2) ────────────────────────────────────────────────
#define USE_SOUND
#define SOUND_TX    17
#define SOUND_RX    18
#define SOUND_BAUD  9600

// File ranges on the DY-SV17F — files named 00001.mp3 … 00025.mp3
// Each effect picks a random file from its range at play time.
#define SND_POWERUP_FILE      1   // 01 tng_poweringup — always this on startup
#define SND_SHUTDOWN_FIRST    2   // 02 ship_shutdown
#define SND_SHUTDOWN_LAST     3   // 03 tng_poweringdown

#define SND_ALERT_FIRST    4   // 04 alertklaxon_clean2
#define SND_ALERT_LAST     6   // 05 alert01  06 alert08

// Damage sequence: alert klaxon plays first, then cuts to a random damage sound
#define SND_DMG_ALERT_1    4   // alert08 (short beep)
#define SND_DMG_ALERT_2    6   // alertklaxon_clean2 (long — gets cut off at DMG_ALERT_MS)
#define DMG_ALERT_MS    2500   // ms of alert before switching to damage sound

#define SND_DAMAGE_FIRST   7   // 07 largeexplosion1  08 largeexplosion3
#define SND_DAMAGE_LAST   12   // 09 shield_sizzle  10 smallexplosion2
                               // 11 starboardnacellenotfunctional  12 tng_powerloss

#define SND_WARP_FIRST    13   // 13 tng_flyby2  14 tng_warp4  15 tng_warp7
#define SND_WARP_LAST     18   // 16 tng_warp_exit  17 tng_warp_flash  18 tng_warp_out2

#define SND_WEAPONS_FIRST 19   // 19 tng_fireallweapons  20 tng_phaser  21 tng_phaser_strike
#define SND_WEAPONS_LAST  25   // 22 tng_torpedo2  23 tng_torpedo  24 tng_weapons2  25 tng_weapons

// Sound commands — sent via ledCmd field from DataPad (must match DataPad constants)
#define SND_CMD_PLAY    50   // ledValue = file number 1–25
#define SND_CMD_STOP    51
#define SND_CMD_VOL     52   // ledValue = 0–30
#define SND_CMD_REPEAT  53   // ledValue = 0=off  1=loop one  2=loop all

// ── LED command constants (identical across all three units) ──────────────────
#define GRP_ALL_WINDOWS   18
#define GRP_BOTH_ENGINES  19
#define GRP_ALL          -1
#define LED_ON            1
#define LED_OFF           2
#define LED_DIM           3
#define LED_BLINK         4
#define LED_ENGINE        5
#define LED_ELEC_SHORT    6
#define LED_STARTUP       7
#define LED_SHUTDOWN      8
#define LED_SET_BLINK_MS  20
#define LED_SET_WIN_MS    21
#define LED_SET_SPC_MS    22
#define LED_SET_AUTO_MS   23   // set auto-start timeout; ledValue = ms (0 = disable)
#define LED_SET_CONN_MS   24   // set connection-lost timeout; ledValue = ms
#define LED_SYNC_MODE     25   // assembled/separated mode (ledValue 1=assembled 0=separated)
#define LED_EFFECTS_SIMPLE 26  // EngRoom only: nacelle/deflector/impulse → constant ON
#define LED_ASSEMBLY_MODE  27  // toggle assembly blink mode (ledValue 1=on 0=off)
#define LED_WARP           28  // nacelle/WarpCore warp speed (ledValue 0=off, 1-10=speed)
#define LED_BAT_LEVEL     31   // Bridge → DataPad: battery voltage (ledValue = mV)
#define LED_PAIR_DATAPAD  34   // both ESPs: open a listen-and-adopt window for a broadcasting DataPad (startWifi=4)
#define LED_ALL_OFF       99

// Bridge-local only, kit/no-DataPad firmware — never sent over ESP-NOW, so kept
// well clear of the shared cross-sketch ledCmd range (see control.html CMD map).
#define LED_DEMO_MANUAL   100  // ledValue 1=on 0=off — toggles the autonomous demo cycle, session-only (not saved to NVS)
#define LED_DEMO_SOUND    101  // ledValue 1=on 0=off — gates sound the demo loop itself plays; muted by default

// ── Shared message struct (identical across all three units) ──────────────────
typedef struct struct_message {
  int      status;
  int      boardInd;
  char     password1[65];
  char     ssid1[33];
  int      startWifi;
  int      wifiStatus;
  uint32_t ipAddress;
  int      ledGroup;
  int      ledCmd;
  int      ledValue;
} struct_message;

struct_message      myData;
esp_now_peer_info_t peerInfo;

// ── ESP-NOW incoming command flags ────────────────────────────────────────────
volatile int  startWifi1       = 0;
volatile bool newLedCmd        = false;
volatile bool pendingStateReply = false;
int pendingGroup = 0;
int pendingCmd   = 0;
int pendingValue = 0;

// ── Pin map — indices 0-17, ordered to match STARTUP_SEQ ─────────────────────
//               [0] [1] [2] [3] [4]  [5]  [6]  [7]  [8]  [9] [10] [11] [12] [13] [14] [15] [16] [17]
int pinArray[] = { 6,  7, 35,  5, 15,  21,  16,  14,  13,  12,  11,  10,   8,   3,   9,  38,  36,  37};
//               G01 G02 G03 G04 G05  G06  G07  G08  G09  G10  G11  G12  G13  G14  G15  NAV  IML  IMR
#define NUM_GROUPS  18
#define NUM_WINDOWS 15  // indices 0-14
#define IDX_NAV     15
#define IDX_ENG_A   16
#define IDX_ENG_B   17

// ── LEDC (ESP32 Arduino core 3.x API — pin-based, no channel numbers) ─────────
#define LEDC_FREQ  5000
#define LEDC_BITS  8
// Convenience pin accessors
#define PIN_ENG_A    pinArray[IDX_ENG_A]   // GPIO 36
#define PIN_ENG_B    pinArray[IDX_ENG_B]   // GPIO 37
#define PIN_NAV      pinArray[IDX_NAV]     // GPIO 38
#define PIN_BAT_ADC  2                     // ADC1 — voltage divider R1=270kΩ R2=100kΩ

bool windowZoneDimActive = false;   // true when all windows are ledcAttach'd for zone dim

// ── NVS timing settings ───────────────────────────────────────────────────────
Preferences  prefs;
uint32_t blinkIntervalMs  = 500;    // NAV blink toggle interval
uint32_t winStartupMs     = 300;    // delay between window steps in startup
uint32_t spcStartupMs     = 800;    // delay before NAV and engines in startup
uint32_t autoStartDelayMs = 10000;  // auto-startup if no ESP-NOW contact (0 = disabled)

// ── Assembly mode ─────────────────────────────────────────────────────────────
// Alternates odd/even window groups to help identify panels during reassembly
bool     asmMode    = false;
uint32_t lastAsmMs  = 0;
bool     asmPhase   = false;   // false = odd groups ON, true = even groups ON

// ── Assembled/Separated sync mode ────────────────────────────────────────────
bool assembledMode = true;   // false = each unit runs independently
bool startupSolo   = false;  // set per LED_STARTUP command; true = run full sequence

// ── Auto-start fallback ───────────────────────────────────────────────────────
uint32_t bootMs               = 0;
bool     bootIndicatorActive  = false;
uint32_t bootIndicatorStartMs = 0;
uint32_t bootIndicatorBlinkMs = 0;
bool     bootIndicatorPhase   = false;
bool     espNowReceived  = false;
bool     autoStartFired  = false;

// ── Autonomous "showpiece" demo mode (kit/no-DataPad Bridge firmware only) ───
// DEVNOTES.md Pending Work #30. Default-on: once the first auto_ms delay above
// elapses, the model power-cycles itself forever — random EngRoom effects
// while "on," then shuts down, waits, and powers back on. LED_DEMO_MANUAL can
// override it off/back on from the web page, but that override is session-only
// (never written to NVS) — a power-cycle always comes back up demo-on.
bool     demoModeOn       = true;
bool     demoSoundOn      = false;   // LED_DEMO_SOUND — muted by default
bool     demoPoweredPhase = false;   // true once the current "powered on" phase has begun
uint32_t demoPhaseUntilMs = 0;       // millis() when the current on/off phase should end
uint32_t demoNextEffectMs = 0;       // next random-effect trigger time (powered-on phase only)
uint32_t demoWarpOffMs    = 0;       // 0 = no demo-triggered warp effect currently running
#define DEMO_ON_MIN_MS     180000UL  // 3 min
#define DEMO_ON_MAX_MS     360000UL  // 6 min
#define DEMO_OFF_MIN_MS     30000UL  // 30s
#define DEMO_OFF_MAX_MS     90000UL  // 90s
#define DEMO_EFFECT_MIN_MS  15000UL  // 15s between random effects
#define DEMO_EFFECT_MAX_MS  45000UL  // 45s
#define DEMO_WARP_MIN_MS     8000UL  // how long a demo-triggered warp effect runs
#define DEMO_WARP_MAX_MS    20000UL

// ── DataPad auto-adopt pairing (Fix Queue #9 / UTILITY_BATCH_PROVISIONING.md) ─
// LED_PAIR_DATAPAD opens a temporary window; a fresh DataPad broadcasts
// startWifi=4 (ESP-NOW broadcast address, no prior peer knowledge needed on
// either side) to announce itself. Captured in OnDataRecv() below.
bool     pairWindowOpen   = false;
uint32_t pairWindowUntilMs = 0;
#define PAIR_WINDOW_MS 60000UL   // 60s

// ── WiFi save flag (startWifi=2 = connect + save to NVS) ─────────────────────
volatile bool saveWifi1 = false;

// ── Connection monitor ────────────────────────────────────────────────────────
uint32_t connLostMs      = 300000; // 5 min — declare lost if no message for this long
uint32_t lastContactMs   = 0;      // updated on every received ESP-NOW message
bool     connectionLost  = false;

// NAV fault-blink pattern: 3 quick flashes then a long pause
// Array is alternating on/off durations in ms; even index = ON, odd index = OFF
const uint16_t CONN_LOST_PATTERN[] = {120, 80, 120, 80, 120, 1800};
#define CONN_PATTERN_LEN 6
uint8_t  connPatternIdx = 0;
uint32_t connPatternMs  = 0;

// ── Global effect state ───────────────────────────────────────────────────────
enum Effect { EFF_IDLE, EFF_STARTUP, EFF_SHUTDOWN, EFF_ELEC_SHORT };
Effect   currentEffect = EFF_IDLE;

// ── Blink (NAV) state ─────────────────────────────────────────────────────────
bool     blinkState    = false;
bool     blinkActive   = false;
uint32_t lastBlinkMs   = 0;

// ── Engine flicker state ──────────────────────────────────────────────────────
bool     engActive     = false;
bool     engSync       = true;   // true = A+B together, false = independent (damage)

// ── Startup / shutdown sequencer ──────────────────────────────────────────────
struct SeqStep { int idx[2]; int count; };

const SeqStep STARTUP_SEQ[] = {
  {{14, -1}, 1},   // Step 0:  G15 alone
  {{13, -1}, 1},   // Step 1:  G14 alone
  {{ 1, -1}, 1},   // Step 2:  G02 alone
  {{ 0,  2}, 2},   // Step 3:  G01 + G03 (G02 already on — G01,G02,G03 now lit)
  {{ 8, -1}, 1},   // Step 4:  G09 alone
  {{ 7,  9}, 2},   // Step 5:  G08 + G10
  {{ 6, 10}, 2},   // Step 6:  G07 + G11
  {{ 5, 11}, 2},   // Step 7:  G06 + G12
  {{ 4, 12}, 2},   // Step 8:  G05 + G13
  {{ 3, -1}, 1},   // Step 9:  G04 alone
  {{15, -1}, 1},   // Step 10: NAV — starts blinking  (spcStartupMs delay before this)
  {{16, 17}, 2},   // Step 11: IM LEFT + IM RIGHT      (spcStartupMs delay before this)
};
#define SEQ_TOTAL_STEPS 12

int      seqStep   = 0;
uint32_t lastSeqMs = 0;

// ── Electrical short state ────────────────────────────────────────────────────
struct WinShortState {
  bool     active;         // true = participates in effect; false = frozen at pre-damage state
  bool     flickerMode;    // true = PWM flicker (ledcAttach'd), false = slow on/off
  bool     on;
  uint32_t nextMs;
};
WinShortState winShort[NUM_WINDOWS];
uint32_t nextEngDmgAMs = 0;
uint32_t nextEngDmgBMs = 0;

// Damage auto-cancel state (timer and pre-damage restore)
bool     preDmgEngActive        = false;
bool     preDmgBlinkActive      = false;
bool     preDmgZoneActive       = false;
bool     preDmgWindowOn[NUM_WINDOWS];
uint32_t damageTimeoutMs   = 120000;
uint32_t damageStartMs     = 0;

// Damage sound sequencing: phase 1 = alert playing, phase 2 = damage sound playing
uint8_t  dmgSndPhase  = 0;
uint32_t dmgSndNextMs = 0;


// ═══════════════════════════════════════════════════════════════════════════════
// LED HELPERS
// ═══════════════════════════════════════════════════════════════════════════════

void winWrite(int idx, bool on) {
  if (windowZoneDimActive) return;   // zone dim has control, ignore individual writes
  digitalWrite(pinArray[idx], on ? HIGH : LOW);
}

void allWindowsOff() {
  if (windowZoneDimActive) {
    for (int i = 0; i < NUM_WINDOWS; i++) ledcDetach(pinArray[i]);
    windowZoneDimActive = false;
  }
  for (int i = 0; i < NUM_WINDOWS; i++) {
    pinMode(pinArray[i], OUTPUT);
    digitalWrite(pinArray[i], LOW);
  }
}

void allOff() {
  allWindowsOff();
  ledcWrite(PIN_ENG_A, 0);
  ledcWrite(PIN_ENG_B, 0);
  ledcWrite(PIN_NAV,   0);
  blinkActive   = false;
  engActive     = false;
  blinkState    = false;
  currentEffect = EFF_IDLE;
}

void setZoneDim(uint8_t brightness) {
  if (!windowZoneDimActive) {
    for (int i = 0; i < NUM_WINDOWS; i++)
      ledcAttach(pinArray[i], LEDC_FREQ, LEDC_BITS);
    windowZoneDimActive = true;
  }
  for (int i = 0; i < NUM_WINDOWS; i++) ledcWrite(pinArray[i], brightness);
}

void releaseZoneDim(bool leaveOn) {
  if (!windowZoneDimActive) return;
  for (int i = 0; i < NUM_WINDOWS; i++) {
    ledcDetach(pinArray[i]);
    pinMode(pinArray[i], OUTPUT);
    digitalWrite(pinArray[i], leaveOn ? HIGH : LOW);
  }
  windowZoneDimActive = false;
}


// ═══════════════════════════════════════════════════════════════════════════════
// BATTERY ADC
// ═══════════════════════════════════════════════════════════════════════════════

float batVolts = 0.0f;

float readBatteryVolts() {
  return analogReadMilliVolts(PIN_BAT_ADC) * 3.83f / 1000.0f;
}


// ═══════════════════════════════════════════════════════════════════════════════
// SOUND (DY-SV17F)
// ═══════════════════════════════════════════════════════════════════════════════
#ifdef USE_SOUND

uint8_t soundVolume = 15;

void soundSend(uint8_t cmd, uint8_t *data, uint8_t len) {
  uint8_t sum = 0xAA + cmd + len;
  Serial2.write(0xAA);
  Serial2.write(cmd);
  Serial2.write(len);
  for (uint8_t i = 0; i < len; i++) { Serial2.write(data[i]); sum += data[i]; }
  Serial2.write(sum & 0xFF);
}

void soundSetVolume(uint8_t vol) {
  if (vol > 30) vol = 30;
  soundVolume = vol;
  soundSend(0x13, &vol, 1);
}
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
void loop() {
  if (startWifi1 == 3) {
    startWifi1 = 0;
    RevertWiFi();
  } else if (startWifi1 == 1) {
    bool doSave = saveWifi1;
    startWifi1 = 0;
    saveWifi1  = false;
    StartWiFi(doSave);
  }

  if (wifiActive) {
    if (WiFi.status() != WL_CONNECTED) {
      if (wifiDropMs == 0) wifiDropMs = millis();
      else if (millis() - wifiDropMs >= WIFI_REVERT_MS) {
        wifiDropMs = 0; startWifi1 = 3;
      }
    } else { wifiDropMs = 0; }
  }

  if (bootIndicatorActive) {
    if (millis() - bootIndicatorStartMs >= 20000) {
      bootIndicatorActive = false;
      ledcWrite(PIN_NAV, 0);
      winWrite(13, false);
      winWrite(14, false);
    } else if (millis() - bootIndicatorBlinkMs >= 500) {
      bootIndicatorBlinkMs = millis();
      bootIndicatorPhase   = !bootIndicatorPhase;
      ledcWrite(PIN_NAV, bootIndicatorPhase ? 255 : 0);
      winWrite(13, bootIndicatorPhase);
      winWrite(14, bootIndicatorPhase);
    }
  }

  if (newLedCmd) {
    newLedCmd = false;
    handleLedCommand(pendingGroup, pendingCmd, pendingValue);
  }

  // Auto-start: if no ESP-NOW contact within autoStartDelayMs, run startup sequence.
  // Skipped entirely once demoModeOn — updateDemoCycle() owns the first power-on
  // too in that case (it reuses this same autoStartDelayMs for the first delay).
  if (!demoModeOn && !autoStartFired && !espNowReceived &&
      autoStartDelayMs > 0 && millis() - bootMs >= autoStartDelayMs) {
    autoStartFired = true;
    handleLedCommand(-1, LED_STARTUP, 0);
  }

  updateDemoCycle();

  if (pairWindowOpen && millis() >= pairWindowUntilMs) {
    pairWindowOpen = false;
    Serial.println("[pair] window closed (timeout)");
  }

  // Connection monitor: if contact lost for connLostMs, go to default state + fault blink
  if (!connectionLost && espNowReceived &&
      connLostMs > 0 && millis() - lastContactMs >= connLostMs) {
    connectionLost = true;
    if (currentEffect == EFF_IDLE && !engActive && !blinkActive) {
      handleLedCommand(-1, LED_STARTUP, 0);
    }
    // Force NAV on with fault pattern even if it was off
    blinkActive    = true;
    connPatternIdx = 0;
    connPatternMs  = millis();
    ledcWrite(PIN_NAV, 255);  // start on the first flash immediately
  }

  // Damage control auto-cancel
  if (currentEffect == EFF_ELEC_SHORT && millis() - damageStartMs >= damageTimeoutMs) {
    stopElecShort();   // handles currentEffect, engines, nav, windows
    struct_message reply;
    memset(&reply, 0, sizeof(reply));
    reply.boardInd = 1;
    reply.status   = 3;   // damage auto-cancelled
    esp_now_send(broadcastAddress2, (uint8_t *)&reply, sizeof(reply));
  }

  if (pendingStateReply) {
    pendingStateReply = false;
    struct_message reply; memset(&reply, 0, sizeof(reply));
    reply.boardInd = 1; reply.status = 1;
    reply.ledValue = asmMode ? 1 : 0;
    esp_now_send(broadcastAddress2, (uint8_t *)&reply, sizeof(reply));
  }

  // Status ping — tell DataPad we're still alive every 30 seconds
  static uint32_t lastStatusPingMs = 0;
  if (millis() - lastStatusPingMs >= 30000) {
    lastStatusPingMs = millis();
    struct_message ping;
    memset(&ping, 0, sizeof(ping));
    ping.boardInd = 1;
    ping.status   = 1;
    ping.ledValue = asmMode ? 1 : 0;
    if (wifiActive && WiFi.status() == WL_CONNECTED) {
      ping.wifiStatus = 5;
      ping.ipAddress  = (uint32_t)WiFi.localIP();
    }
    esp_now_send(broadcastAddress2, (uint8_t *)&ping, sizeof(ping));
  }

  static uint32_t lastBatMs = 0;
  if (millis() - lastBatMs >= 30000) {
    lastBatMs = millis();
    batVolts = readBatteryVolts();
    struct_message batPing;
    memset(&batPing, 0, sizeof(batPing));
    batPing.boardInd = 1;
    batPing.ledCmd   = LED_BAT_LEVEL;
    batPing.ledValue = (int)(batVolts * 1000.0f);
    esp_now_send(broadcastAddress2, (uint8_t *)&batPing, sizeof(batPing));
  }

  updateEffects();
  ArduinoOTA.handle();
  bridgeWebServer.handleClient();

  if (statusFlashUntilMs && millis() >= statusFlashUntilMs) {
    statusFlashUntilMs = 0;
    statusIdle();
  }
}


// ═══════════════════════════════════════════════════════════════════════════════
// WIFI CONNECT
// ═══════════════════════════════════════════════════════════════════════════════

void RevertWiFi() {
  prefs.begin("bridge", false);
  prefs.putBool("wifi_auto", false);
  prefs.end();
  WiFi.disconnect();
  esp_wifi_set_channel(1, WIFI_SECOND_CHAN_NONE);
  wifiChannel = 1;
  wifiActive  = false;
  wifiDropMs  = 0;
  servicesStarted = false;
}

void StartWiFi(bool saveCredentials) {
  const char* ssid     = myData.ssid1;
  const char* password = myData.password1;

  bool connected = false;
  for (int attempt = 1; attempt <= 2 && !connected; attempt++) {
    WiFi.disconnect();
    WiFi.begin(ssid, password);
    unsigned long startTime = millis();
    while (millis() - startTime < 10000) {
      if (WiFi.status() == WL_CONNECTED) { connected = true; break; }
      delay(100);
    }
  }

  if (!connected) {
    WiFi.disconnect();
    esp_wifi_set_channel(1, WIFI_SECOND_CHAN_NONE);
    wifiChannel = 1;
    prefs.begin("bridge", false); prefs.putBool("wifi_auto", false); prefs.end();
    myData.boardInd   = 1;
    myData.wifiStatus = 4;
    esp_now_send(broadcastAddress2, (uint8_t *)&myData, sizeof(myData));
    return;
  }

  // Re-establish ESP-NOW after WiFi connects: disable power save and refresh peers
  // on the new channel so sends don't fail
  esp_wifi_set_ps(WIFI_PS_NONE);
  esp_now_del_peer(broadcastAddress1);
  esp_now_del_peer(broadcastAddress2);
  memcpy(peerInfo.peer_addr, broadcastAddress1, 6);
  peerInfo.channel = 0; peerInfo.encrypt = false;
  esp_now_add_peer(&peerInfo);
  memcpy(peerInfo.peer_addr, broadcastAddress2, 6);
  peerInfo.channel = 0; peerInfo.encrypt = false;
  esp_now_add_peer(&peerInfo);
  wifiChannel = (uint8_t)WiFi.channel();

  myData.boardInd   = 1;
  myData.wifiStatus = 5;
  myData.ipAddress  = (uint32_t)WiFi.localIP();
  esp_now_send(broadcastAddress2, (uint8_t *)&myData, sizeof(myData));

  if (saveCredentials) {
    prefs.begin("bridge", false);
    prefs.putString("wifi_ssid", String(myData.ssid1));
    prefs.putString("wifi_pass", String(myData.password1));
    prefs.putBool("wifi_auto",   true);
    prefs.end();
  }

  if (!servicesStarted) {
    MDNS.begin(mdnsName);
    ArduinoOTA.begin();
    servicesStarted = true;
    wifiActive = true;
    wifiDropMs = 0;
  }
}

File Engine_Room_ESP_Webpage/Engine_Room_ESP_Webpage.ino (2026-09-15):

/*
  Engine Room ESP — Xiao ESP32-C3
  11 LED groups + ESP-NOW + OTA
*/

#include <esp_now.h>
#include <WiFi.h>
#include <esp_wifi.h>
#include <ESPmDNS.h>
#include <NetworkUdp.h>
#include <ArduinoOTA.h>
#include <Preferences.h>
#include <WebServer.h>
#include <math.h>

void RevertWiFi();
void StartWiFi(bool saveCredentials = false);
void handleLedCommand(int grp, int cmd, int val);
float readBatteryVolts();

const char* mdnsName      = "EngRoom";
uint32_t    last_ota_time = 0;
bool        servicesStarted = false;
bool        wifiActive      = false;
uint32_t    wifiDropMs      = 0;
#define WIFI_REVERT_MS 90000UL
uint8_t     wifiChannel   = 1;

// ── Bridge-AP join + fallback AP ─────────────────────────────────────────────
// The kit has no home-network join at all (control_html.h has no WiFi-join UI
// on purpose) — Bridge always hosts its own fixed AP, so joining it is the
// only path EngRoom has to OTA/mDNS reachability. Without this, EngRoom's OTA
// is unreachable in real kit use (the legacy push-based StartWiFi()/wifi_auto
// flow below is never triggered by anything in the kit UI).
#define BRIDGE_AP_SSID         "Enterprise D"
#define BRIDGE_AP_PASS         "ncc1701-d"
#define BRIDGE_JOIN_TIMEOUT_MS 180000UL   // 3 min, per UTILITY_BATCH_PROVISIONING.md
#define FALLBACK_AP_SSID       "EngRoom Fallback"
#define FALLBACK_AP_PASS       "ncc1701-d"   // same password as Bridge's AP, on purpose

uint32_t   bridgeJoinStartMs = 0;
bool       bridgeStaWasUp    = false;
bool       fallbackApActive  = false;
uint32_t   fallbackStartMs   = 0;
WebServer  fallbackServer(80);

uint8_t broadcastAddress[]  = {0x00, 0x00, 0x00, 0x00, 0x00, 0x00};  // DataPad — run MAC_address_retriver on your board (or use SETMAC below)
uint8_t bridgeAddress[]     = {0x00, 0x00, 0x00, 0x00, 0x00, 0x00};  // Bridge — run MAC_address_retriver on your board (or use SETMAC below)
uint8_t dataPad2Address[]   = {0x00, 0x00, 0x00, 0x00, 0x00, 0x00};  // DataPad 2.8" pocket remote — run MAC_address_retriver on your board (or use SETMAC below)

// ── LED command constants (must match Bridge and DataPad exactly) ─────────────
#define LED_ON             1
#define LED_OFF            2
#define LED_DIM            3
#define LED_BLINK          4
#define LED_ENGINE         5
#define LED_ELEC_SHORT     6
#define LED_STARTUP        7
#define LED_SHUTDOWN       8
#define LED_SET_BLINK_MS  20
#define LED_SET_WIN_MS    21
#define LED_SET_SPC_MS    22
#define LED_SET_AUTO_MS   23
#define LED_SET_CONN_MS   24
#define LED_SYNC_MODE     25   // assembled/separated mode (ledValue 1=assembled 0=separated)
#define LED_EFFECTS_SIMPLE 26
#define LED_ASSEMBLY_MODE  27
#define LED_WARP           28  // nacelle warp speed (ledValue 0=normal, 1-10=warp speed)
#define LED_BAT_LEVEL      31  // EngRoom → DataPad: battery mV as int
#define LED_PAIR_DATAPAD   34  // both ESPs: open a listen-and-adopt window for a broadcasting DataPad (startWifi=4)
#define LED_ALL_OFF       99

// Special group constants
#define GRP_ALL_WINDOWS   18   // Bridge compat — used as "all EngRoom windows" here
#define GRP_BOTH_ENGINES  19   // Bridge engines — ignored by EngRoom LED_ENGINE handler
#define GRP_BOTH_NAC      20   // EngRoom nacelles
#define GRP_ALL           -1

// ── Shared message struct ─────────────────────────────────────────────────────
typedef struct struct_message {
  int      status, boardInd;
  char     password1[65];
  char     ssid1[33];
  int      startWifi, wifiStatus;
  uint32_t ipAddress;
  int      ledGroup, ledCmd, ledValue;
} struct_message;

struct_message      myData;
esp_now_peer_info_t peerInfo;

volatile int  startWifi1        = 0;
volatile bool saveWifi1         = false;
volatile bool pendingStateReply = false;

// Incoming command flag — set in callback, dispatched in loop
volatile bool newLedCmd  = false;
int pendingGroup = 0, pendingCmd = 0, pendingValue = 0;

// ── NVS ───────────────────────────────────────────────────────────────────────
Preferences prefs;

// ── Pin and group constants ───────────────────────────────────────────────────
#define NUM_WINDOWS 3
const int WIN_PINS[] = {20, 7, 21};  // neck (all), eng top, eng bot

#define PIN_NAV        5
#define PIN_DEFLECTOR  6
#define PIN_IMPULSE   10
#define PIN_NAC_R      3
#define PIN_NAC_L      8
#define PIN_PHOTON     4
#define PIN_PHOTON_AFT 9   // EngRoom Photon 2x variant — active-low, no transistor (see HARDWARE.md)
#define PIN_BAT_ADC    2

// Group index constants (ledGroup values from DataPad)
#define IDX_NECK       0   // GPIO 20 (neck back + both battle bridges wired together)
#define IDX_ENG_TOP    1   // GPIO 7
#define IDX_ENG_BOT    2   // GPIO 21
#define IDX_NAV        5   // GPIO 5
#define IDX_DEFLECTOR  6   // GPIO 6
#define IDX_IMPULSE    7   // GPIO 10
#define IDX_NAC_RIGHT  8   // GPIO 9
#define IDX_NAC_LEFT   9   // GPIO 8
#define IDX_PHOTON    10   // GPIO 4
#define IDX_PHOTON_AFT 11  // GPIO 9 (Photon 2x variant)

// All pins in order — used only by assembly mode walk
const int ALL_PINS[]  = {4, 5, 6, 7, 8, 9, 10, 20, 21};
#define NUM_ALL_PINS 9

#define LEDC_FREQ 5000
#define LEDC_BITS 8

// ── NVS timing ────────────────────────────────────────────────────────────────
uint32_t blinkIntervalMs  = 500;
uint32_t winStartupMs     = 300;
uint32_t spcStartupMs     = 800;
uint32_t autoStartDelayMs = 30000;
uint32_t connLostMs       = 300000;

// ── Auto-start ────────────────────────────────────────────────────────────────
uint32_t bootMs               = 0;
bool     bootIndicatorActive  = false;
uint32_t bootIndicatorStartMs = 0;
uint32_t bootIndicatorBlinkMs = 0;
bool     bootIndicatorPhase   = false;
bool     espNowReceived = false;
bool     autoStartFired = false;

// ── DataPad auto-adopt pairing (Fix Queue #9 / UTILITY_BATCH_PROVISIONING.md) ─
// Mirrors Bridge_ESP.ino's pairing window — see its comment for the full flow.
bool     pairWindowOpen   = false;
uint32_t pairWindowUntilMs = 0;
#define PAIR_WINDOW_MS 60000UL   // 60s

// ── Connection monitor ────────────────────────────────────────────────────────
uint32_t lastContactMs  = 0;
bool     connectionLost  = false;
bool     intentionallyOff = false;  // set on shutdown/all-off; suppresses connection-loss auto-restart
const uint16_t CONN_LOST_PATTERN[] = {120, 80, 120, 80, 120, 1800};
#define CONN_PATTERN_LEN 6
uint8_t  connPatternIdx = 0;
uint32_t connPatternMs  = 0;

// ── Effect state machine ──────────────────────────────────────────────────────
enum Effect { EFF_IDLE, EFF_STARTUP, EFF_SHUTDOWN, EFF_ELEC_SHORT };
Effect currentEffect = EFF_IDLE;

struct SeqStep { int idx[3]; int count; };
const SeqStep STARTUP_SEQ[] = {
  {{IDX_NECK,    -1,           -1},            1},
  {{IDX_ENG_TOP, IDX_ENG_BOT, -1},            2},
  {{IDX_NAV,       -1,           -1},           1},
  {{IDX_DEFLECTOR, -1,           -1},           1},
  {{IDX_IMPULSE,   -1,           -1},           1},
  {{IDX_NAC_RIGHT, IDX_NAC_LEFT, -1},           2},
};
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

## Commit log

2026-06-05 Initial release — USS Enterprise-D ESP32 prop controller
    All sketches, PCB files, 3D print files, and documentation.
    MAC addresses zeroed — run MAC_address_retriver on your hardware.
    [BOM_BridgePCB1.xlsx, BOM_BridgePCB2.xlsx, BOM_BridgePCB3.xlsx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]
2026-06-08 Cross-link the WarpCore companion repo
    Fill in placeholder links now that Enterprise-D-WarpCore is published — root README points to the WarpCore repo, and WarpCore README points back to this one.
2026-06-08 Zero out real MAC addresses in README example code blocks
    The sketches' peer MAC arrays were already zeroed for publication, but the matching example blocks in Bridge_ESP, Engine_Room_ESP, Data_Pad, and WarpCore_ESP32 READMEs still showed the real on-model device MACs. Replaced with the same {0x00, ...} placeholder used in the sketches.
2026-06-08 Add ASSEMBLY.md build guide with FFC routing and mounting photos
    New top-level guide covering FFC ribbon cable routing through the saucer/stardrive frame and neck connection (including cable protection and mounting clearance notes), nacelle routing, dual speaker mounting, and DataPad internal wiring. Linked from the root README's repository contents table.
2026-06-08 Remove dead DESIGN_STORY.md reference from ASSEMBLY.md
    DESIGN_STORY.md is not included in this repo (it's reserved for a future
    standalone project write-up site), so the cross-reference was a dead link
    for anyone reading the published guide.
2026-06-09 Add nacelle LED resistor values to HARDWARE.md and EngRoom README
    Confirmed values: 240Ω for parallel SMD pairs, 470Ω for single through-hole
    LEDs, 1.2kΩ for nav lights (unchanged). EngRoom README notes the resistor
    swap as an optional mod for a brighter warp flash.
2026-06-17 Fix reversed nacelle polarity connections on EngRoom PCB
2026-06-17 Fix EngRoom right nacelle GPIO 9 strapping pin conflict, update PCB
    GPIO 9 is a boot strapping pin on ESP32-C3 — nacelle transistor circuit
    pulled it LOW at power-on, preventing boot. Right nacelle moved to GPIO 3
    on PCB. EngRoom MAC updated to 80:F1:B2:60:6F:54 (ESP replaced).
2026-06-18 Session 39: GPIO 9 strapping pin fix, new EngRoom MAC, broadcast WiFi push
    - Right nacelle moved from GPIO 9 to GPIO 3 — GPIO 9 is ESP32-C3 BOOT
    strapping pin, NPN base resistor pulled it LOW causing boot freeze
    - EngRoom MAC updated to 80:F1:B2:60:6F:54 (ESP replaced) in all sketches
    - SaveWifi now sends broadcast (FF:FF:FF:FF:FF:FF) + unicast fallback
    with 500ms delays to prevent channel shift killing the frame
    - EngRoom WiFi response includes MAC in ssid1 for diagnostic display
    [Bridge_ESP.ino, Data_Pad.ino, Engine_Room_ESP.ino]
2026-06-19 Redact MAC addresses from all sketches and docs for public repo
    Zero all ESP-NOW peer MAC arrays in Bridge_ESP, Data_Pad, and
    Engine_Room_ESP sketches. Redact MAC references in DEVNOTES.md,
    HARDWARE.md, and Engine_Room_ESP/README.md. Sync Data_Pad.ino
    battery alert fix (ledValue > 0 guard on Bridge battery path).
    [Bridge_ESP.ino, Data_Pad.ino, Engine_Room_ESP.ino]
2026-06-19 Add web_mac_address utility sketch
    Captive portal sketch preloaded on boards — starts a WiFi AP
    (enterprise / ncc-1701-d), auto-opens a webpage showing the
    board's MAC address. Includes OTA support for wireless updates.
2026-06-19 Add NVS clear to web_mac_address, remove standalone NVS clear sketches
    web_mac_address now serves NVS clear buttons on the captive portal
    page — clear Bridge, EngRoom, DataPad, WarpCore, or all namespaces
    with one tap. No need to edit WiFi credentials or flash a separate
    sketch. Removes Bridge_NVS_Clear and EngRoom_NVS_Clear folders.
    [web_mac_address.ino]
2026-06-19 Rename web_mac_address to board_utility
    Name now reflects the sketch's role as a general-purpose board
    utility (MAC address display + NVS clear). OTA hostname and all
    references updated to board_utility.
2026-06-19 Update README for board_utility, remove NVS clear references
    Getting started now points to board_utility for MAC retrieval.
    Repo contents table updated: board_utility replaces the two
    standalone NVS clear sketches, MAC_address_retriver marked legacy.
2026-06-23 Add ESP32-S3 blank chip UART flash note, update docs
    - HARDWARE.md: new section documenting that blank S3 modules need UART first flash before USB works, with dev board alternative
    - README.md: callout in First Flash section pointing to HARDWARE.md
    - HARDWARE.md: accumulated doc updates from recent sessions (ADC calibration, GPIO 9 fix, DataPad 2.8" section)
2026-06-24 Add Save WiFi hint label, update docs from website review
    DataPad: add "Press again to disconnect" hint below Save WiFi button
    on Screen 3 (ui_LabelSaveHint). Shows after save, clears on revert.
    HARDWARE.md: corrections found during website content review.
    DEVNOTES.md: session notes updated.
    [Data_Pad.ino]
2026-06-24 Update DEVNOTES for session 44 — website rewrite, Save WiFi hint, web server
2026-06-25 Session 45 — audio fix, battery alert fix, board settings warning, website deploy
    - Data_Pad: Save WiFi hint label fix (missing extern, font size bump)
    - Data_Pad: Battery alert split into per-unit flags (bridgeBat/engRoomBat)
    - All sketch READMEs: board settings reset warning added
    - DEVNOTES: session 45 logged, website deploy resolved
    - WarpCore MAC zeroed in Data_Pad.ino
    [Data_Pad.ino]
2026-06-28 Add mDNS and serial print WiFi credentials to board_utility
2026-06-28 Session 46 — board_utility mDNS and serial WiFi credentials
2026-06-28 Remove DEVNOTES.md from repo — personal session log only
2026-08-08 Update EngRoom and Neck PCB files — wider 0.8-1mm VCC/GND traces
    Supports single shared power source between sections if ever needed.
2026-08-08 Document single power source option for EngRoom/Neck PCBs
    Wider VCC/GND traces on these boards support routing power through the
    stand into the saucer via a single source, at the cost of permanently
    joining the two model sections.
2026-08-08 Document EngRoom/Neck PCB power trace widening in HARDWARE.md
    Cross-references the single power source option write-up in README.md.
2026-08-15 Bridge PCB3: add 0Ω bypass jumper for 5V regulator
    Allows future conversion to a 5V power source by removing the
    regulator and changing only the LED current-limiting resistor
    values, instead of requiring a board respin.
    [BOM_BridgePCB3.xlsx, PickAndPlace_BridgePCB3.xlsx]
2026-08-15 HARDWARE: add 5V bypass build row to LED resistor table
    Documents the calculated 510Ω LED resistor value for the PCB3
    0Ω regulator bypass jumper, matching the ~3.5mA target current
    used by the 2S and 3S builds. Not yet populated on hardware.
2026-08-15 Document nacelle warp-flash resistor rework (240Ω/470Ω)
    Bench-confirmed values from session 36 physically installed on the
    nacelle boards 2026-08-15. Notes that firmware caps normal-running
    nacelle brightness well below the new max, so higher current only
    appears during warp flash.
2026-08-18 Add EngRoom Photon 2x PCB variant
    New board variant adding a 2-pin GPIO9 connector for an aft photon
    torpedo LED, wired active-low to avoid the existing GPIO9 boot
    strapping issue. Separate variant from the main EngRoom PCB, not a
    revision. Firmware not yet updated.
    [BOM_Engroom Photon 2x.xlsx, PickAndPlace_Engroom Photon 2x.xlsx]
2026-08-28 Document single-power-source fuse/reverse-polarity protection
    Add inline fuse + reverse-polarity diode guidance for the barrel-jack
    single-power-source mod, with exact part selection left to the builder.
    Fuse holder sourced and added to the parts list.
2026-09-09 Document kit external-power fuse; exclude cost tracker from public repo
    Claude-Session: https://claude.ai/code/session_0179gYWYPBBtpWgsqzat2n36
2026-09-11 board_utility: join Bridge's AP instead of hosting its own
    Avoids a channel-1 conflict between board_utility's own AP and
    Bridge's AP + ESP-NOW when bench-testing both together. Now joins
    Bridge's AP as a STA client at a fixed IP instead of hosting a
    separate hotspot; captive-portal DNS handling removed since it's
    no longer its own AP.
    Claude-Session: https://claude.ai/code/session_01Guyy5vwStkS5TEscyy4vpt
    [board_utility.ino]
2026-09-15 Add work-in-progress webpage-control firmware variant
    Bridge_ESP_Webpage/ and Engine_Room_ESP_Webpage/ are new sketches
    (renamed/sanitized from private kit development) offering a
    self-hosted control webpage instead of the DataPad-driven WiFi push
    flow. Includes independent aft photon torpedo support on EngRoom.
    Real MACs zeroed to placeholders per existing convention.
    Also: HARDWARE.md's Photon 2x note updated to reflect firmware
    support, and README.md cleaned up (fixed a stale DEVNOTES.md
    reference and a Data_Pad_240x320 folder that was never added).
    [Bridge_ESP_Webpage.ino, Engine_Room_ESP_Webpage.ino]
2026-10-09 Webpage firmware: real-hardware fixes, field update page, power-cycle toggle
    Refreshes Bridge_ESP_Webpage and Engine_Room_ESP_Webpage after a full
    control-page test pass on real LEDs.
    - Nav and impulse commands now reach EngRoom (group numbers translated)
    - Saucer impulse turns off properly (engine pulse kept re-lighting it)
    - Nav "Always On" setting implemented on both boards (nav_mode NVS key)
    - All On / All Off toggle (new LED_ALL_ON = 35)
    - Engage Warp works on every press, plays a warp sound, auto-reverts
    - Demo mode: page shows real state, stays quiet unless Demo Sound is on,
    no longer fires effects at a model that's been switched off
    - Trigger Damage is a toggle with a working Canc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
2026-10-13 HARDWARE: measured Bridge power draw, single-source budget, 5V observations
2026-10-13 Web_Control_Kit: packing list — add zip ties
2026-10-18 Web_Control_Kit: packing list — drop zip ties, speaker + power FFC notes
2026-10-19 HARDWARE: kit power path note (USB-C breakout + XL6009 boost)
2026-10-22 Web_Control_Kit: Assembly Mode button syncs from /status; HARDWARE: connector label note
    Bridge /status now reports asm, and the control page syncs the Assembly
    Mode toggle from it, so the first tap works after a reboot (bench-tested).
    HARDWARE.md notes the original-part-number connector labels and the *
    suffix for connectors split between two LED groups.
2026-10-25 Web_Control_Kit: add Data_Pad_Kit; zero example MACs in READMEs
    - New Web_Control_Kit/Data_Pad_Kit/: 7" DataPad firmware for the web-control
    kit — Pair New DataPad announce, Aft Photon + Fire All Weapons buttons,
    Engage Warp button (replaces slider), All On via LED_ALL_ON (incl. aft
    photon), red/yellow alert also sound on the saucer. MACs zeroed.
    - HARDWARE: flash the 7" Waveshare over its UART USB-C port.
    - Data_Pad/Bridge_ESP/Engine_Room_ESP/WarpCore_ESP32 READMEs: example peer
    MACs zeroed to match the sketches.
2026-10-26 ASSEMBLY: leave the 2 neck plate screws out (FFC short risk)
2026-10-27 HARDWARE: plain 5V does not run the fully assembled model
